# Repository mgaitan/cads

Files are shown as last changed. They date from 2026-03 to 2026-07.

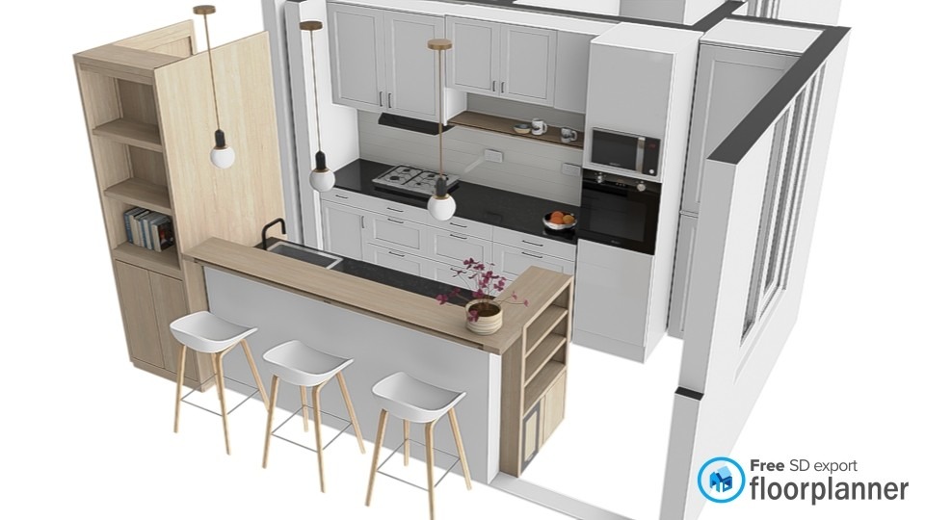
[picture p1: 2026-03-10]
renders/fuga.jpeg

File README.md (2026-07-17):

# Diseños CAD - Cocina

Repositorio de mis diseños de muebles en FreeCAD.

## Flujo actual
- Se edita el modelo directo en FreeCAD, idealmente via MCP.
- La fuente de verdad es el `FCStd`.
- Cada pieza guarda metadata embebida (`bom_*`).
- El despiece para proveedor sale en `TSV`, una fila por objeto real.
- La optimización de corte lee esos `TSV`, no BOM resumidos.

## FreeCAD MCP
Se usa [`freecad-mcp`](https://github.com/neka-nat/freecad-mcp) para editar los modelos desde una sesion de FreeCAD abierta.

La mejor manera de saber donde hay que copiar el addon es preguntarselo a FreeCAD desde su consola Python:

```python
import FreeCAD as App
print(App.getUserAppDataDir())
```

En este caso, usando AppImage `rc3`, el directorio fue:

```text
~/.local/share/FreeCAD/v1-1/
```

Configuracion MCP usada:

```json
{
  "freecad-mcp": {
    "command": "uvx",
    "args": ["-p", "3.12", "freecad-mcp", "--only-text-feedback"],
    "env": {}
  }
}
```

## Estructura útil
- `models/`: modelos fuente
- `models/*.md`: notas constructivas por mueble
- `src/cads/`: herramientas vigentes
- `outputs/supplier/`: TSV para proveedor, un archivo por material y espesor
- `outputs/cutting/`: placements, summary y SVG de corte
- `outputs/screenshots/`: capturas desde FreeCAD GUI
- `outputs/manuals/COCINA.pdf`: manual final

## Modulos
- `AA`: alacena izquierda
- `AB`: alacena derecha
- `AC`: complemento inferior de `AB`
- `BA`: bajo mesada izquierdo
- `BB`: bajo mesada derecho
- `F`: heladera + modular
- `H`: columna horno + micro
- `I`: bajo mesada isla
- `L`: armario lavarropas
- `M`: mesada principal
- `R`: rinconera
- `ENS`: ensamble cocina principal
- `ENSI`: ensamble isla
- `FULL`: ensamble completo
- `vanitory_flotante_800`: vanitory flotante anterior de 800 mm
- `vanitory_reforma_770`: vanitory reforma de 770 mm
- `vanitory_reforma_830`: vanitory reforma de 830 mm

## Herramientas vigentes
- `src/cads/freecad/macros/export_supplier_cut_list_macro.py`
  - macro FreeCAD GUI
  - exporta una fila por pieza real
- `src/cads/freecad/macros/export_screenshots_gui_macro.py`
  - macro FreeCAD GUI para vistas
- `.agents/SKILLS/freecad-furnitures/macros/create_essential_dimensions_macro.py`
  - recurso reutilizable de la skill para cotas opcionales
- `src/cads/cli/optimize_cuts.py`
  - optimiza cortes desde un solo `TSV` por corrida
- `src/cads/cli/refresh_site.py`
  - sincroniza `manual`, `screenshots`, `STL` y `cutting` dentro de `outputs/site/`
- `src/cads/freecad/freecad_gola.py`
  - helpers geométricos de gola
- `tools/build_vanitory_reforma_770.py` y `tools/build_vanitory_reforma_830.py`
  - scripts auxiliares de los vanitories; los `FCStd` siguen siendo la fuente de verdad

## Cantos del proveedor
El proveedor interpreta los 4 flags en este orden:
1. lado izquierdo del `Largo`
2. lado derecho del `Largo`
3. lado superior del `Ancho`
4. lado inferior del `Ancho`

Es decir:
- `Largo` -> `| |`
- `Ancho` -> `— —`

La macro traduce los cantos visibles del modelo a ese sistema.

Cada TSV se importa sin encabezado y tiene este orden fijo:

```text
pieza  cantidad  largo_mm  ancho_mm  girar  canto_izq  canto_der  canto_sup  canto_inf
```

La pieza se forma como `bom_codigo` + `_` + el slug de `bom_pieza`; por ejemplo,
`A1_PISO` o `A2_LAT_DERECHO`.

## Uso
Supplier desde FreeCAD GUI:
- abrir los módulos
- ejecutar `src/cads/freecad/macros/export_supplier_cut_list_macro.py`

Cotas maestras en FreeCAD GUI:
1. abrir el `FCStd` y seleccionar el documento en el arbol
2. abrir `Ver > Paneles > Consola Python`
3. pegar y ejecutar:

```python
DIMENSION_SCOPE = "casco"  # total | casco | seleccion
DIMENSION_AXES = ("X", "Y", "Z")
exec(open("/home/tin/lab/cads/.agents/SKILLS/freecad-furnitures/macros/create_essential_dimensions_macro.py").read())
```

4. en el arbol, seleccionar `Cotas esenciales` y presionar `Espacio` para mostrarlas u ocultarlas

La macro crea solo las cotas elegidas. `casco` excluye frentes, cajones,
herrajes y mesada; se ven tambien en perspectiva y se reemplazan al volver a
ejecutar la macro despues de modificar el mueble.

Optimización de corte:
```bash
uv run optimize-cuts \
  outputs/supplier/AA_AB_BA_BB_H_R_blanco_18mm.tsv \
  --board 2750x1830 --svg
```

Cada espesor o material se corre por separado, con el tamaño de placa que corresponda:

```bash
uv run optimize-cuts outputs/supplier/AA_AB_BA_BB_H_R_blanco_18mm.tsv --board 2750x1830 --svg
uv run optimize-cuts outputs/supplier/AA_AB_BA_BB_H_R_fondo_3mm.tsv --board 2440x1830 --svg
uv run optimize-cuts outputs/supplier/AA_AB_BA_BB_H_R_fondo_6mm.tsv --board 2440x1830 --svg
```

Actualización del sitio:
```bash
uv run refresh-site
```

Ese comando:
- copia el manual desde `outputs/manuals/`
- copia los STL desde `outputs/web_models/`
- copia los cortes desde `outputs/cutting/`
- aplana las capturas desde `outputs/screenshots/<MODULO>/` a `outputs/site/assets/screenshots/`

GitHub Pages publica `outputs/site/` al hacer `push` a `master`.

## Estado actual
- `I.FCStd` es la versión vigente de la isla.
- Los flujos viejos basados en `scripts/models`, `bom/*.csv` y `STEP` quedaron retirados.

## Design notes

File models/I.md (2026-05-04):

# Bajo mesada isla I

## Parametros vigentes
- Ancho casco: `1680 mm`
- Profundidad casco: `650 mm`
- Mesada: `1720 x 658 x 30 mm`
- Alzada piedra: `1720 x 30 x 180 mm`
- Fondo paraiso: desde `z=80` hasta `z=1080`
- Barra: `1720 x 370 x 30 mm`
- Alto casco: `870 mm`
- Zocalo/patas: `80 mm`

## Configuracion actual
- Nicho lavavajillas libre a la izquierda
- Dos puertas bajo bacha:
  - `I18`
  - `I18B`
- Gola `J` superior bajo mesada para las puertas de bacha: `I41`
- Divisor central bajo bacha `I4`
- Sin puerta en lavavajillas
- `I8B` y `I8C` removibles en lavavajillas
- `I8` estante regulable bajo bacha
- Alzada y barra integradas en el propio modelo `I`
- Interior del cajon superior `I29*` de `100 mm` de alto, con fondo `2 mm` sobre `I25`

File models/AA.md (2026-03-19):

# Alacena AA

## Parametros vigentes
- Ancho exterior: `903 mm`
- Profundidad exterior: `300 mm`
- Alto total: `710 mm`
- Base del casco: `0 mm`
- Tapa superior: `692..710 mm`
- Liston fijo inferior `AA10`: `313 x 90 mm`
- Referencia extractor `AA11`: `590 x 470 mm`

## Configuracion
- Dos puertas iguales `AA8/AA9`
- Piso y tapa pasantes
- Profundidad ya corregida de `320` a `300`
- El liston `AA10` va solo desde el lateral izquierdo hasta el extractor

## Instalacion
- En ensamble, la base de `AA` va a `1590 mm`
- Coronacion final alineada a `2300 mm`

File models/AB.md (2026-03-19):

# Conjunto AB + AC

## Parametros vigentes
- Ancho exterior total: `1355 mm`
- Profundidad exterior: `300 mm`
- `AC` inferior en paraiso
- `AB` superior en blanco

## AC
- Alto total de `AC`: `327 mm`
- Laterales `AC1/AC2`: `291 mm` de alto
- `AC4` hace de techo de `AC` y piso estructural de `AB`
- `AC5` es fondo de `18 mm`
- Ya no existen `AC6` a `AC9`

## AB
- Alto total de `AB`: `473 mm` sobre `AC`
- Tres puertas `AB6/AB7/AB8`
- Piso `AB3` al nivel de la gola
- Divisor `AB10` del lado derecho de la puerta central, arrancando sobre `AB3`
- Profundidad ya corregida de `320` a `300`

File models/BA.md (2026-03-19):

# Bajo mesada BA

## Parametros vigentes
- Ancho exterior: `903 mm`
- Profundidad exterior: `580 mm`
- Alto casco: `870 mm`
- Zocalo/patas: `80 mm`

## Configuracion
- Frente falso superior `BA9`
- Dos frentes grandes `BA10/BA11`
- Soporte superior frontal `BA5`: `867 x 100 mm`
- Soporte superior fondo `BA6`: `867 x 100 mm`
- Los cajones mantienen `500 mm` de largo

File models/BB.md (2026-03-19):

# Bajo mesada BB

## Parametros vigentes
- Ancho exterior: `1355 mm`
- Profundidad exterior: `580 mm`
- Alto casco: `870 mm`
- Zocalo/patas: `80 mm`

## Configuracion
- Seis frentes: `BB8` a `BB13`
- Soporte superior frontal `BB5`: `1319 x 100 mm`
- Soporte superior fondo `BB6`: `1319 x 100 mm`
- Los cajones mantienen `500 mm` de largo

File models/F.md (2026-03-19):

# Mueble F

## Parametros vigentes
- Alto total lateral: `2260 mm` sobre patas de `80 mm`
- Coronacion con `F26`: `2278 mm`
- Ancho total: `780 mm`
- Profundidad total: `950 mm`

## Configuracion
- Todo `F` va en paraiso `18 mm`
- Sin cajon superior para spots
- `F26_Techo_Modulo_Estantes` pasante a toda la profundidad
- Los laterales terminan en la cara inferior de `F26`

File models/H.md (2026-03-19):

# Columna H

## Parametros vigentes
- Altura total: `2300 mm`
- Profundidad total: `580 mm`
- Ancho exterior: `672 mm`
- Ancho interior libre entre laterales: `636 mm`
- Patas: `80 mm`

## Configuracion actual
- Dos cuerpos:
  - inferior hasta `H7`
  - alacena superior sobre `H19`
- Cuatro puertas:
  - `H10A/H10B` abajo
  - `H11A/H11B` arriba
- Regruesos horizontales:
  - `H12B` abajo del horno
  - `H9B` arriba del horno
- Regruesos verticales:
  - `H15`
  - `H16`
- `H8` es estante regulable con luz lateral

## Huecos utiles aproximados
- Horno visible de frente: `600 x 600 mm`
- Microondas interior: ancho `636 mm`, profundidad `580 mm`

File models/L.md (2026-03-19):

# Mueble L

## Parametros vigentes
- Ancho exterior: `890 mm`
- Profundidad exterior: `760 mm`
- Altura total: `2300 mm`
- Parantes exteriores: `100 mm`

## Configuracion actual
- Dos cuerpos:
  - inferior hasta la gola
  - alacena superior separada
- Gola `C` media `L12`
- Piso del modulo superior `L13`
- Puertas inferiores:
  - `L8`
  - `L9`
- Puertas superiores:
  - `L10`
  - `L11`
- `L6` es techo del sector lavarropas

## Medidas de puertas
- Inferiores: `1528 x 444 mm`
- Superiores: `666 x 442 mm`

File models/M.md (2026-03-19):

# Mesada M

## Parametros vigentes
- Largo total: `2258 mm`
- Profundidad total: `648 mm`
- Espesor: `30 mm`
- Cota inferior: `870 mm`
- Cota superior final: `900 mm`

## Nota
- La pieza vigente en el modelo es `M1_Mesada_Gris_Mara`
- Verificar siempre plantilla final in situ antes del corte definitivo de piedra

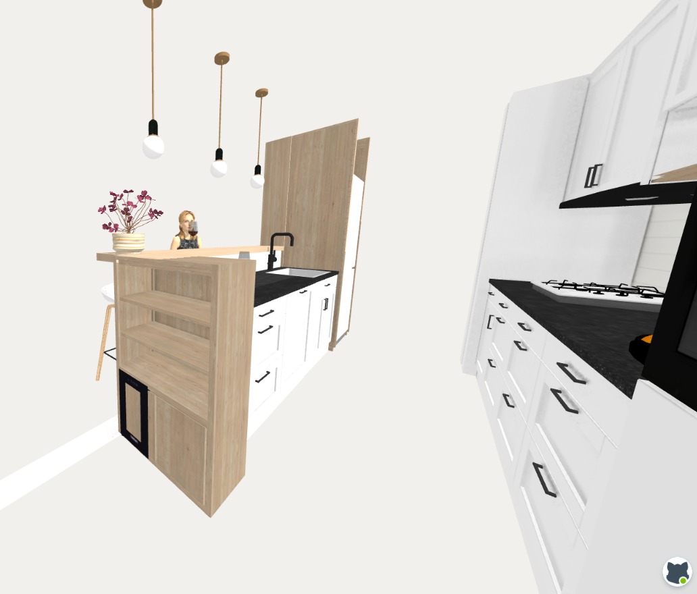
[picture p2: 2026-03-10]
renders/vista_lateral.jpeg

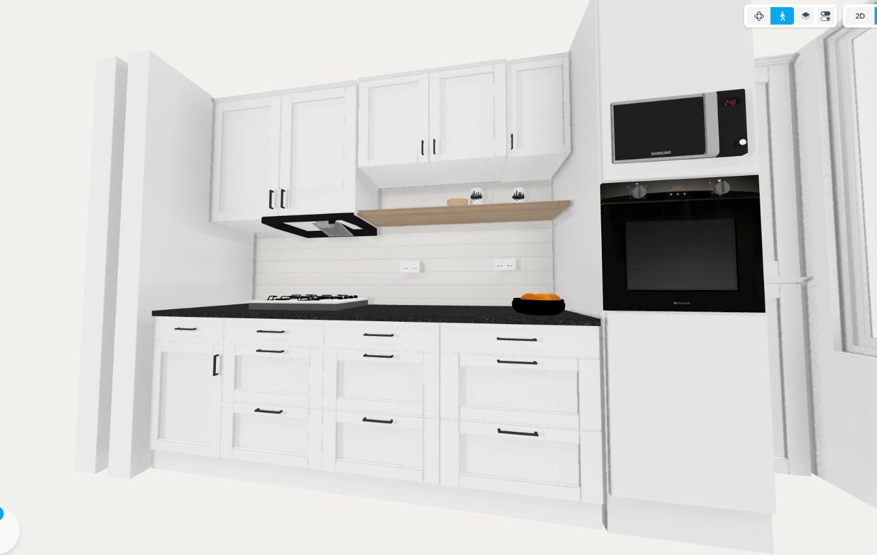
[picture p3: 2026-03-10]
renders/cocina_alacena.jpeg

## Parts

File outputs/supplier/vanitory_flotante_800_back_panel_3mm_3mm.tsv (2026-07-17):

codigo | pieza | categoria | material | largo_mm | ancho_mm | espesor_mm | canto_izq | canto_der | canto_sup | canto_inf | cantos | bisagra_codo | luz_bisagra_mm | bisagra_lado | cazoleta_diametro_mm | cazoleta_cantidad | cazoleta_posiciones
VF07 | Fondo trasero pasante 3mm | Back | back panel 3mm | 800 | 450 | 3 | 0 | 0 | 0 | 0 | sin canto de melamina |  |  |  | 0 | 0

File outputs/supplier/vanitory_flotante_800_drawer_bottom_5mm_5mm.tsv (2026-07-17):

codigo | pieza | categoria | material | largo_mm | ancho_mm | espesor_mm | canto_izq | canto_der | canto_sup | canto_inf | cantos | bisagra_codo | luz_bisagra_mm | bisagra_lado | cazoleta_diametro_mm | cazoleta_cantidad | cazoleta_posiciones
VF12_Cajon_InferiorE | Fondo 5mm pasante cajon inferior | Drawer | drawer bottom 5mm | 347 | 327 | 5 | 0 | 0 | 0 | 0 | fondo cajon 5mm pasante; sin canto de melamina |  |  |  | 0 | 0
VF13_Cajon_MedioE | Fondo 5mm pasante cajon medio | Drawer | drawer bottom 5mm | 347 | 327 | 5 | 0 | 0 | 0 | 0 | fondo cajon 5mm pasante; sin canto de melamina |  |  |  | 0 | 0
VF14_Cajon_SuperiorE | Fondo 5mm pasante cajon superior | Drawer | drawer bottom 5mm | 347 | 327 | 5 | 0 | 0 | 0 | 0 | fondo cajon 5mm pasante; sin canto de melamina |  |  |  | 0 | 0

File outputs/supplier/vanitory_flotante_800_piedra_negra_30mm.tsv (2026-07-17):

codigo | pieza | categoria | material | largo_mm | ancho_mm | espesor_mm | canto_izq | canto_der | canto_sup | canto_inf | cantos | bisagra_codo | luz_bisagra_mm | bisagra_lado | cazoleta_diametro_mm | cazoleta_cantidad | cazoleta_posiciones
VF20 | Tapa piedra negra | Countertop | piedra negra | 800 | 400 | 30 | 0 | 0 | 0 | 0 | sin canto de melamina |  |  |  | 0 | 0

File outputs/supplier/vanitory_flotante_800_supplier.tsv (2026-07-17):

codigo | pieza | categoria | material | largo_mm | ancho_mm | espesor_mm | canto_izq | canto_der | canto_sup | canto_inf | cantos | bisagra_codo | luz_bisagra_mm | bisagra_lado | cazoleta_diametro_mm | cazoleta_cantidad | cazoleta_posiciones
VF03 | Base inferior pasante | Carcass | white melamine | 800 | 370 | 18 | 1 | 0 | 0 | 0 | front edge |  |  |  | 0 | 0
VF01 | Lateral izquierdo sobre base | Carcass | white melamine | 432 | 370 | 18 | 1 | 0 | 0 | 0 | front edge |  |  |  | 0 | 0
VF02 | Lateral derecho sobre base | Carcass | white melamine | 432 | 370 | 18 | 1 | 0 | 0 | 0 | front edge |  |  |  | 0 | 0
VF04 | Riel superior frontal soporte piedra | Carcass | white melamine | 764 | 100 | 18 | 1 | 0 | 0 | 0 | front edge |  |  |  | 0 | 0
VF05 | Riel superior trasero soporte piedra | Carcass | white melamine | 764 | 100 | 18 | 0 | 0 | 0 | 0 | oculto, sin canto visible |  |  |  | 0 | 0
VF06 | Divisor vertical interior puerta/cajones | Partition | white melamine | 414 | 370 | 18 | 1 | 0 | 0 | 0 | front edge |  |  |  | 0 | 0
VF07 | Fondo trasero pasante 3mm | Back | back panel 3mm | 800 | 450 | 3 | 0 | 0 | 0 | 0 | sin canto de melamina |  |  |  | 0 | 0
VF08 | Frente puerta izquierda codo 0 | Front | white melamine | 444 | 395 | 18 | 1 | 1 | 1 | 1 | todos los cantos visibles | 0 | 3 | left | 35 | 2 | left side; codo 0; 3mm reveal; centers 90mm from bottom/top; x center 22mm from hinge edge
VF09 | Frente cajon inferior medio canto | Front | white melamine | 396 | 146 | 18 | 1 | 1 | 1 | 1 | todos los cantos visibles |  |  |  | 0 | 0
VF10 | Frente cajon medio medio canto | Front | white melamine | 396 | 146 | 18 | 1 | 1 | 1 | 1 | todos los cantos visibles |  |  |  | 0 | 0
VF11 | Frente cajon superior medio canto | Front | white melamine | 396 | 146 | 18 | 1 | 1 | 1 | 1 | todos los cantos visibles |  |  |  | 0 | 0
VF20 | Tapa piedra negra | Countertop | piedra negra | 800 | 400 | 30 | 0 | 0 | 0 | 0 | sin canto de melamina |  |  |  | 0 | 0
VF21 | Zocalo posterior piedra negra | Countertop | piedra negra | 800 | 70 | 20 | 0 | 0 | 0 | 0 | sin canto de melamina |  |  |  | 0 | 0
VF22 | Zocalo lateral izquierdo piedra negra | Countertop | piedra negra | 400 | 70 | 20 | 0 | 0 | 0 | 0 | sin canto de melamina |  |  |  | 0 | 0
VF12_Cajon_InferiorE | Fondo 5mm pasante cajon inferior | Drawer | drawer bottom 5mm | 347 | 327 | 5 | 0 | 0 | 0 | 0 | fondo cajon 5mm pasante; sin canto de melamina |  |  |  | 0 | 0
VF12_Cajon_InferiorA | Lateral izquierdo cajon inferior | Drawer | white melamine | 327 | 110 | 18 | 0 | 0 | 1 | 0 | canto superior visible al abrir el cajon |  |  |  | 0 | 0
VF12_Cajon_InferiorB | Lateral derecho cajon inferior | Drawer | white melamine | 327 | 110 | 18 | 0 | 0 | 1 | 0 | canto superior visible al abrir el cajon |  |  |  | 0 | 0
VF12_Cajon_InferiorC | Trasfrente cajon inferior | Drawer | white melamine | 311 | 110 | 18 | 0 | 0 | 1 | 0 | canto superior visible al abrir el cajon |  |  |  | 0 | 0
VF12_Cajon_InferiorD | Contrafrente cajon inferior | Drawer | white melamine | 311 | 110 | 18 | 0 | 0 | 1 | 0 | canto superior visible al abrir el cajon |  |  |  | 0 | 0
VF13_Cajon_MedioE | Fondo 5mm pasante cajon medio | Drawer | drawer bottom 5mm | 347 | 327 | 5 | 0 | 0 | 0 | 0 | fondo cajon 5mm pasante; sin canto de melamina |  |  |  | 0 | 0
VF13_Cajon_MedioA | Lateral izquierdo cajon medio | Drawer | white melamine | 327 | 110 | 18 | 0 | 0 | 1 | 0 | canto superior visible al abrir el cajon |  |  |  | 0 | 0
VF13_Cajon_MedioB | Lateral derecho cajon medio | Drawer | white melamine | 327 | 110 | 18 | 0 | 0 | 1 | 0 | canto superior visible al abrir el cajon |  |  |  | 0 | 0
VF13_Cajon_MedioC | Trasfrente cajon medio | Drawer | white melamine | 311 | 110 | 18 | 0 | 0 | 1 | 0 | canto superior visible al abrir el cajon |  |  |  | 0 | 0
VF13_Cajon_MedioD | Contrafrente cajon medio | Drawer | white melamine | 311 | 110 | 18 | 0 | 0 | 1 | 0 | canto superior visible al abrir el cajon |  |  |  | 0 | 0
VF14_Cajon_SuperiorE | Fondo 5mm pasante cajon superior | Drawer | drawer bottom 5mm | 347 | 327 | 5 | 0 | 0 | 0 | 0 | fondo cajon 5mm pasante; sin canto de melamina |  |  |  | 0 | 0
VF14_Cajon_SuperiorA | Lateral izquierdo cajon superior | Drawer | white melamine | 327 | 110 | 18 | 0 | 0 | 1 | 0 | canto superior visible al abrir el cajon |  |  |  | 0 | 0
VF14_Cajon_SuperiorB | Lateral derecho cajon superior | Drawer | white melamine | 327 | 110 | 18 | 0 | 0 | 1 | 0 | canto superior visible al abrir el cajon |  |  |  | 0 | 0
VF14_Cajon_SuperiorC | Trasfrente cajon superior | Drawer | white melamine | 311 | 110 | 18 | 0 | 0 | 1 | 0 | canto superior visible al abrir el cajon |  |  |  | 0 | 0
VF14_Cajon_SuperiorD | Contrafrente cajon superior | Drawer | white melamine | 311 | 110 | 18 | 0 | 0 | 1 | 0 | canto superior visible al abrir el cajon |  |  |  | 0 | 0

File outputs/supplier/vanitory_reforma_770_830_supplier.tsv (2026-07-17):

codigo | pieza | categoria | material | largo_mm | ancho_mm | espesor_mm | canto_izq | canto_der | canto_sup | canto_inf | cantos | bisagra_codo | luz_bisagra_mm | bisagra_lado | cazoleta_diametro_mm | cazoleta_cantidad | cazoleta_posiciones
VS_01_base_inf_pas | 770 - Base inferior pasante | Carcass | white melamine | 770 | 500 | 18 | 1 | 0 | 0 | 0 | front edge |  |  |  | 0 | 0
VS_02_lat_izq_base | 770 - Lateral izquierdo sobre base | Carcass | white melamine | 702 | 500 | 18 | 1 | 0 | 0 | 0 | front edge |  |  |  | 0 | 0
VS_03_lat_der_base | 770 - Lateral derecho sobre base | Carcass | white melamine | 702 | 500 | 18 | 1 | 0 | 0 | 0 | front edge |  |  |  | 0 | 0
VS_04_riel_sup_front_sop | 770 - Riel superior frontal soporte piedra | Carcass | white melamine | 734 | 100 | 18 | 1 | 0 | 0 | 0 | front edge |  |  |  | 0 | 0
VS_05_riel_sup_tras_sop | 770 - Riel superior trasero soporte piedra | Carcass | white melamine | 734 | 100 | 18 | 0 | 0 | 0 | 0 | oculto, sin canto visible |  |  |  | 0 | 0
VS_06_est_reg_comp | 770 - Estante regulable completo | Adjustable_Shelf | white melamine | 734 | 470 | 18 | 1 | 0 | 0 | 0 | front edge; estante regulable con soportes/perforaciones laterales |  |  |  | 0 | 0
VS_17_faja_cent_izq_sop | 770 - Faja central izquierda soporte corredera | Carcass | white melamine | 500 | 180 | 18 | 0 | 0 | 0 | 0 | soporte interior de corredera, atornillable desde arriba |  |  |  | 0 | 0
VS_18_faja_cent_der_sop | 770 - Faja central derecha soporte corredera | Carcass | white melamine | 500 | 180 | 18 | 0 | 0 | 0 | 0 | soporte interior de corredera, atornillable desde arriba |  |  |  | 0 | 0
VS_07_fte_caj_izq | 770 - Frente cajon izquierdo | Front | white melamine | 380 | 180 | 18 | 1 | 1 | 1 | 1 | todos los cantos visibles |  |  |  | 0 | 0
VS_08_fte_caj_der | 770 - Frente cajon derecho | Front | white melamine | 380 | 180 | 18 | 1 | 1 | 1 | 1 | todos los cantos visibles |  |  |  | 0 | 0
VS_09_pta_inf_izq | 770 - Puerta inferior izquierda | Front | white melamine | 510 | 380 | 18 | 1 | 1 | 1 | 1 | todos los cantos visibles | 0 | 3 | left | 35 | 2 | left side; codo 0; 3mm reveal; centers 90mm from bottom/top; x center 22mm from hinge edge
VS_10_pta_inf_der | 770 - Puerta inferior derecha | Front | white melamine | 510 | 380 | 18 | 1 | 1 | 1 | 1 | todos los cantos visibles | 0 | 3 | right | 35 | 2 | right side; codo 0; 3mm reveal; centers 90mm from bottom/top; x center 22mm from hinge edge
VS_11a_lat_izq_caj_izq | 770 - Lateral izquierdo cajon izquierdo | Drawer | white melamine | 300 | 140 | 18 | 0 | 0 | 1 | 0 | canto superior visible al abrir el cajon |  |  |  | 0 | 0
VS_11b_lat_der_caj_izq | 770 - Lateral derecho cajon izquierdo | Drawer | white melamine | 300 | 140 | 18 | 0 | 0 | 1 | 0 | canto superior visible al abrir el cajon |  |  |  | 0 | 0
VS_11c_trasfte_caj_izq | 770 - Trasfrente cajon izquierdo | Drawer | white melamine | 283 | 140 | 18 | 0 | 0 | 1 | 0 | canto superior visible al abrir el cajon |  |  |  | 0 | 0
VS_11d_ctrfte_caj_izq | 770 - Contrafrente cajon izquierdo | Drawer | white melamine | 283 | 140 | 18 | 0 | 0 | 1 | 0 | canto superior visible al abrir el cajon |  |  |  | 0 | 0
VS_11e_fondo_caj_izq | 770 - Fondo cajon izquierdo | Drawer | drawer bottom 5mm | 300 | 283 | 5 | 0 | 0 | 0 | 0 | sin canto visible |  |  |  | 0 | 0
VS_12a_lat_izq_caj_der | 770 - Lateral izquierdo cajon derecho | Drawer | white melamine | 300 | 140 | 18 | 0 | 0 | 1 | 0 | canto superior visible al abrir el cajon |  |  |  | 0 | 0
VS_12b_lat_der_caj_der | 770 - Lateral derecho cajon derecho | Drawer | white melamine | 300 | 140 | 18 | 0 | 0 | 1 | 0 | canto superior visible al abrir el cajon |  |  |  | 0 | 0
VS_12c_trasfte_caj_der | 770 - Trasfrente cajon derecho | Drawer | white melamine | 283 | 140 | 18 | 0 | 0 | 1 | 0 | canto superior visible al abrir el cajon |  |  |  | 0 | 0
VS_12d_ctrfte_caj_der | 770 - Contrafrente cajon derecho | Drawer | white melamine | 283 | 140 | 18 | 0 | 0 | 1 | 0 | canto superior visible al abrir el cajon |  |  |  | 0 | 0
VS_12e_fondo_caj_der | 770 - Fondo cajon derecho | Drawer | drawer bottom 5mm | 300 | 283 | 5 | 0 | 0 | 0 | 0 | sin canto visible |  |  |  | 0 | 0
VS_15_zoc_mes_piedra_tras | 770 - Zocalo mesada piedra trasero | Plinth | black stone | 770 | 120 | 20 | 0 | 0 | 0 | 0 | alzada trasera sobre mesada |  |  |  | 0 | 0
VS_16_piedra_sup | 770 - Piedra superior | Countertop | black stone | 770 | 533 | 20 | 0 | 0 | 0 | 0 | vuela 15mm por delante de los frentes; verificar plantilla en obra |  |  |  | 0 | 0
VC_01_base_inf_pas | 820 - Base inferior pasante | Carcass | white melamine | 820 | 407 | 18 | 1 | 0 | 0 | 0 | front edge |  |  |  | 0 | 0
VC_02_lat_izq_base | 820 - Lateral izquierdo sobre base | Carcass | white melamine | 702 | 407 | 18 | 1 | 0 | 0 | 0 | front edge |  |  |  | 0 | 0
VC_03_lat_der_base | 820 - Lateral derecho sobre base | Carcass | white melamine | 702 | 407 | 18 | 1 | 0 | 0 | 0 | front edge |  |  |  | 0 | 0
VC_04_riel_sup_front_sop | 820 - Riel superior frontal soporte piedra | Carcass | white melamine | 784 | 100 | 18 | 1 | 0 | 0 | 0 | front edge |  |  |  | 0 | 0
VC_05_riel_sup_tras_sop | 820 - Riel superior trasero soporte piedra | Carcass | white melamine | 784 | 100 | 18 | 0 | 0 | 0 | 0 | oculto, sin canto visible |  |  |  | 0 | 0
VC_06_est_reg_comp | 820 - Estante regulable completo | Adjustable_Shelf | white melamine | 784 | 377 | 18 | 1 | 0 | 0 | 0 | front edge; estante regulable con soportes/perforaciones laterales |  |  |  | 0 | 0
VC_17_faja_cent_izq_sop | 820 - Faja central izquierda soporte corredera | Carcass | white melamine | 407 | 180 | 18 | 0 | 0 | 0 | 0 | soporte interior de corredera, atornillable desde arriba |  |  |  | 0 | 0
VC_18_faja_cent_der_sop | 820 - Faja central derecha soporte corredera | Carcass | white melamine | 407 | 180 | 18 | 0 | 0 | 0 | 0 | soporte interior de corredera, atornillable desde arriba |  |  |  | 0 | 0
VC_07_fte_caj_izq | 820 - Frente cajon izquierdo | Front | white melamine | 405 | 180 | 18 | 1 | 1 | 1 | 1 | todos los cantos visibles |  |  |  | 0 | 0
VC_08_fte_caj_der | 820 - Frente cajon derecho | Front | white melamine | 405 | 180 | 18 | 1 | 1 | 1 | 1 | todos los cantos visibles |  |  |  | 0 | 0
VC_09_pta_inf_izq | 820 - Puerta inferior izquierda | Front | white melamine | 510 | 405 | 18 | 1 | 1 | 1 | 1 | todos los cantos visibles | 0 | 3 | left | 35 | 2 | left side; codo 0; 3mm reveal; centers 90mm from bottom/top; x center 22mm from hinge edge
VC_10_pta_inf_der | 820 - Puerta inferior derecha | Front | white melamine | 510 | 405 | 18 | 1 | 1 | 1 | 1 | todos los cantos visibles | 0 | 3 | right | 35 | 2 | right side; codo 0; 3mm reveal; centers 90mm from bottom/top; x center 22mm from hinge edge
VC_11a_lat_izq_caj_izq | 820 - Lateral izquierdo cajon izquierdo | Drawer | white melamine | 300 | 140 | 18 | 0 | 0 | 1 | 0 | canto superior visible al abrir el cajon |  |  |  | 0 | 0
VC_11b_lat_der_caj_izq | 820 - Lateral derecho cajon izquierdo | Drawer | white melamine | 300 | 140 | 18 | 0 | 0 | 1 | 0 | canto superior visible al abrir el cajon |  |  |  | 0 | 0
VC_11c_trasfte_caj_izq | 820 - Trasfrente cajon izquierdo | Drawer | white melamine | 308 | 140 | 18 | 0 | 0 | 1 | 0 | canto superior visible al abrir el cajon |  |  |  | 0 | 0
VC_11d_ctrfte_caj_izq | 820 - Contrafrente cajon izquierdo | Drawer | white melamine | 308 | 140 | 18 | 0 | 0 | 1 | 0 | canto superior visible al abrir el cajon |  |  |  | 0 | 0
VC_11e_fondo_caj_izq | 820 - Fondo cajon izquierdo | Drawer | drawer bottom 5mm | 308 | 300 | 5 | 0 | 0 | 0 | 0 | sin canto visible |  |  |  | 0 | 0
VC_12a_lat_izq_caj_der | 820 - Lateral izquierdo cajon derecho | Drawer | white melamine | 300 | 140 | 18 | 0 | 0 | 1 | 0 | canto superior visible al abrir el cajon |  |  |  | 0 | 0
VC_12b_lat_der_caj_der | 820 - Lateral derecho cajon derecho | Drawer | white melamine | 300 | 140 | 18 | 0 | 0 | 1 | 0 | canto superior visible al abrir el cajon |  |  |  | 0 | 0
VC_12c_trasfte_caj_der | 820 - Trasfrente cajon derecho | Drawer | white melamine | 308 | 140 | 18 | 0 | 0 | 1 | 0 | canto superior visible al abrir el cajon |  |  |  | 0 | 0
VC_12d_ctrfte_caj_der | 820 - Contrafrente cajon derecho | Drawer | white melamine | 308 | 140 | 18 | 0 | 0 | 1 | 0 | canto superior visible al abrir el cajon |  |  |  | 0 | 0
VC_12e_fondo_caj_der | 820 - Fondo cajon derecho | Drawer | drawer bottom 5mm | 308 | 300 | 5 | 0 | 0 | 0 | 0 | sin canto visible |  |  |  | 0 | 0
VC_15_zoc_mes_piedra_tras | 820 - Zocalo mesada piedra trasero | Plinth | black stone | 820 | 120 | 20 | 0 | 0 | 0 | 0 | alzada trasera sobre mesada |  |  |  | 0 | 0
VC_16_piedra_sup | 820 - Piedra superior | Countertop | black stone | 820 | 440 | 20 | 0 | 0 | 0 | 0 | vuela 15mm por delante de los frentes; verificar plantilla en obra |  |  |  | 0 | 0

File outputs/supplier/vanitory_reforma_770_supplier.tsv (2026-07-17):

codigo | pieza | categoria | material | largo_mm | ancho_mm | espesor_mm | canto_izq | canto_der | canto_sup | canto_inf | cantos | bisagra_codo | luz_bisagra_mm | bisagra_lado | cazoleta_diametro_mm | cazoleta_cantidad | cazoleta_posiciones
VS_01_base_inf_pas | Base inferior pasante | Carcass | white melamine | 770 | 500 | 18 | 1 | 0 | 0 | 0 | front edge |  |  |  | 0 | 0
VS_02_lat_izq_base | Lateral izquierdo sobre base | Carcass | white melamine | 702 | 500 | 18 | 1 | 0 | 0 | 0 | front edge |  |  |  | 0 | 0
VS_03_lat_der_base | Lateral derecho sobre base | Carcass | white melamine | 702 | 500 | 18 | 1 | 0 | 0 | 0 | front edge |  |  |  | 0 | 0
VS_04_riel_sup_front_sop | Riel superior frontal soporte piedra | Carcass | white melamine | 734 | 100 | 18 | 1 | 0 | 0 | 0 | front edge |  |  |  | 0 | 0
VS_05_riel_sup_tras_sop | Riel superior trasero soporte piedra | Carcass | white melamine | 734 | 100 | 18 | 0 | 0 | 0 | 0 | oculto, sin canto visible |  |  |  | 0 | 0
VS_06_est_reg_comp | Estante regulable completo | Adjustable_Shelf | white melamine | 734 | 470 | 18 | 1 | 0 | 0 | 0 | front edge; estante regulable con soportes/perforaciones laterales |  |  |  | 0 | 0
VS_17_faja_cent_izq_sop | Faja central izquierda soporte corredera | Carcass | white melamine | 500 | 180 | 18 | 0 | 0 | 0 | 0 | soporte interior de corredera, atornillable desde arriba |  |  |  | 0 | 0
VS_18_faja_cent_der_sop | Faja central derecha soporte corredera | Carcass | white melamine | 500 | 180 | 18 | 0 | 0 | 0 | 0 | soporte interior de corredera, atornillable desde arriba |  |  |  | 0 | 0
VS_07_fte_caj_izq | Frente cajon izquierdo | Front | white melamine | 380 | 180 | 18 | 1 | 1 | 1 | 1 | todos los cantos visibles |  |  |  | 0 | 0
VS_08_fte_caj_der | Frente cajon derecho | Front | white melamine | 380 | 180 | 18 | 1 | 1 | 1 | 1 | todos los cantos visibles |  |  |  | 0 | 0
VS_09_pta_inf_izq | Puerta inferior izquierda | Front | white melamine | 510 | 380 | 18 | 1 | 1 | 1 | 1 | todos los cantos visibles | 0 | 3 | left | 35 | 2 | left side; codo 0; 3mm reveal; centers 90mm from bottom/top; x center 22mm from hinge edge
VS_10_pta_inf_der | Puerta inferior derecha | Front | white melamine | 510 | 380 | 18 | 1 | 1 | 1 | 1 | todos los cantos visibles | 0 | 3 | right | 35 | 2 | right side; codo 0; 3mm reveal; centers 90mm from bottom/top; x center 22mm from hinge edge
VS_11a_lat_izq_caj_izq | Lateral izquierdo cajon izquierdo | Drawer | white melamine | 300 | 140 | 18 | 0 | 0 | 1 | 0 | canto superior visible al abrir el cajon |  |  |  | 0 | 0
VS_11b_lat_der_caj_izq | Lateral derecho cajon izquierdo | Drawer | white melamine | 300 | 140 | 18 | 0 | 0 | 1 | 0 | canto superior visible al abrir el cajon |  |  |  | 0 | 0
VS_11c_trasfte_caj_izq | Trasfrente cajon izquierdo | Drawer | white melamine | 283 | 140 | 18 | 0 | 0 | 1 | 0 | canto superior visible al abrir el cajon |  |  |  | 0 | 0
VS_11d_ctrfte_caj_izq | Contrafrente cajon izquierdo | Drawer | white melamine | 283 | 140 | 18 | 0 | 0 | 1 | 0 | canto superior visible al abrir el cajon |  |  |  | 0 | 0
VS_11e_fondo_caj_izq | Fondo cajon izquierdo | Drawer | drawer bottom 5mm | 300 | 283 | 5 | 0 | 0 | 0 | 0 | sin canto visible |  |  |  | 0 | 0
VS_12a_lat_izq_caj_der | Lateral izquierdo cajon derecho | Drawer | white melamine | 300 | 140 | 18 | 0 | 0 | 1 | 0 | canto superior visible al abrir el cajon |  |  |  | 0 | 0
VS_12b_lat_der_caj_der | Lateral derecho cajon derecho | Drawer | white melamine | 300 | 140 | 18 | 0 | 0 | 1 | 0 | canto superior visible al abrir el cajon |  |  |  | 0 | 0
VS_12c_trasfte_caj_der | Trasfrente cajon derecho | Drawer | white melamine | 283 | 140 | 18 | 0 | 0 | 1 | 0 | canto superior visible al abrir el cajon |  |  |  | 0 | 0
VS_12d_ctrfte_caj_der | Contrafrente cajon derecho | Drawer | white melamine | 283 | 140 | 18 | 0 | 0 | 1 | 0 | canto superior visible al abrir el cajon |  |  |  | 0 | 0
VS_12e_fondo_caj_der | Fondo cajon derecho | Drawer | drawer bottom 5mm | 300 | 283 | 5 | 0 | 0 | 0 | 0 | sin canto visible |  |  |  | 0 | 0
VS_15_zoc_mes_piedra_tras | Zocalo mesada piedra trasero | Plinth | black stone | 770 | 120 | 20 | 0 | 0 | 0 | 0 | alzada trasera sobre mesada |  |  |  | 0 | 0
VS_16_piedra_sup | Piedra superior | Countertop | black stone | 770 | 533 | 20 | 0 | 0 | 0 | 0 | vuela 15mm por delante de los frentes; verificar plantilla en obra |  |  |  | 0 | 0

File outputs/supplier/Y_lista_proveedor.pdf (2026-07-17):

# Lista de piezas proveedor - Modulo Y

## Blanco 18 mm (25 piezas)

Pieza | Cant. | Largo | Ancho | Rot. | C.Izq | C.Der | C.Sup | C.Inf
Y18B_Puerta_Bacha_Der | 1 | 762 | 555 | SI | 0 | 0 | 0 | 0
Y18_Puerta_Bacha_Izq | 1 | 762 | 555 | SI | 1 | 1 | 1 | 1
Y1_Lateral_Izq_Frente | 1 | 772 | 650 | SI | 0 | 1 | 0 | 0
Y24_Division_Cajonera_Izq | 1 | 772 | 650 | SI | 0 | 1 | 0 | 0
Y26_Frente_Cajon_Superior | 1 | 237 | 556 | SI | 1 | 1 | 1 | 1
Y27_Frente_Cajon_Medio | 1 | 597 | 556 | SI | 1 | 1 | 1 | 1
Y28_Frente_Cajon_Inferior | 1 | 237 | 538 | SI | 1 | 1 | 1 | 1
Y29B_Caja_Cajon_Superior_Lateral_Der | 1 | 330 | 100 | SI | 0 | 0 | 0 | 0
Y29C_Caja_Cajon_Superior_Frente | 1 | 477 | 100 | SI | 0 | 0 | 0 | 0
Y29D_Caja_Cajon_Superior_Trasera | 1 | 477 | 100 | SI | 0 | 0 | 0 | 0
Y29_Caja_Cajon_Superior_Lateral_Izq | 1 | 330 | 100 | SI | 0 | 0 | 0 | 0
Y2_Lateral_Der | 1 | 772 | 650 | SI | 1 | 0 | 0 | 0
Y32_Piso_Cajonera | 1 | 574 | 650 | SI | 0 | 0 | 0 | 0
Y35_Estante_Nicho_Trasero | 1 | 536 | 290 | SI | 0 | 0 | 0 | 0
Y37_Fondo_Cajon_Trasero | 1 | 772 | 538 | SI | 0 | 0 | 0 | 0
Y38_Regrueso_Bisagra_Nicho | 1 | 772 | 50 | SI | 0 | 0 | 0 | 0
Y39_Puerta_Nicho_Lateral | 1 | 744 | 284 | SI | 0 | 0 | 0 | 0
Y3_Division_1 | 1 | 772 | 650 | SI | 1 | 0 | 0 | 0
Y6_Piso_Der | 1 | 1057 | 650 | SI | 0 | 0 | 0 | 0
Y8B_Piso_Removible_Lavavajillas | 1 | 583 | 601 | SI | 0 | 0 | 0 | 0
Y8C_Piso_Falso_Lavavajillas | 1 | 601 | 650 | SI | 0 | 0 | 0 | 0
Y9B_Soporte_Sup_Trasero | 1 | 556 | 100 | SI | 0 | 0 | 0 | 0
Y9C_Soporte_Sup_Frente_Bacha | 1 | 1095 | 100 | SI | 1 | 0 | 0 | 0
Y9D_Soporte_Sup_Trasero_Bacha | 1 | 1095 | 100 | SI | 0 | 0 | 0 | 0
Y9_Soporte_Sup_Frente | 1 | 556 | 100 | SI | 1 | 0 | 0 | 0

## Fondo 3 mm (0 piezas)

Sin piezas para este material.

## Fondo 6 mm (1 piezas)

Pieza | Cant. | Largo | Ancho | Rot. | C.Izq | C.Der | C.Sup | C.Inf
Y29E_Caja_Cajon_Superior_Fondo_6mm | 1 | 513 | 330 | SI | 0 | 0 | 0 | 0

## Paraiso 18 mm (1 piezas)

Pieza | Cant. | Largo | Ancho | Rot. | C.Izq | C.Der | C.Sup | C.Inf
Y21B_Placa_Fondo_Paraiso | 1 | 2350 | 1000 | SI | 0 | 0 | 0 | 0

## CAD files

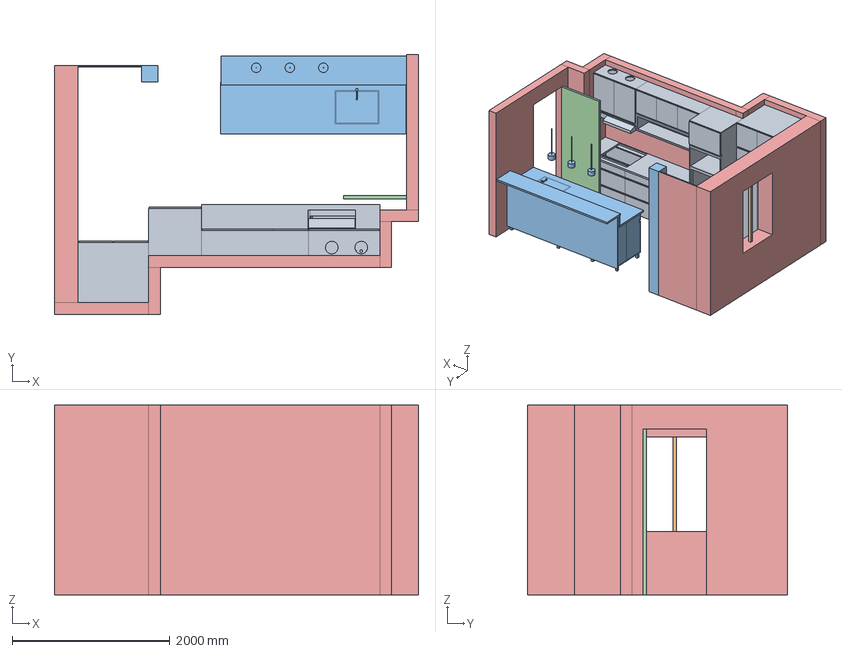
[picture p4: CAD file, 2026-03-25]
models/FULL.FCStd
4610.0 x 3293.0 x 2400.0 mm
FULL_ENS
FULL_Ventana_Parteluz
FULL_ENSI
FULL_Puerta_Cierre_Der
FULL_Muros_Arquitectura

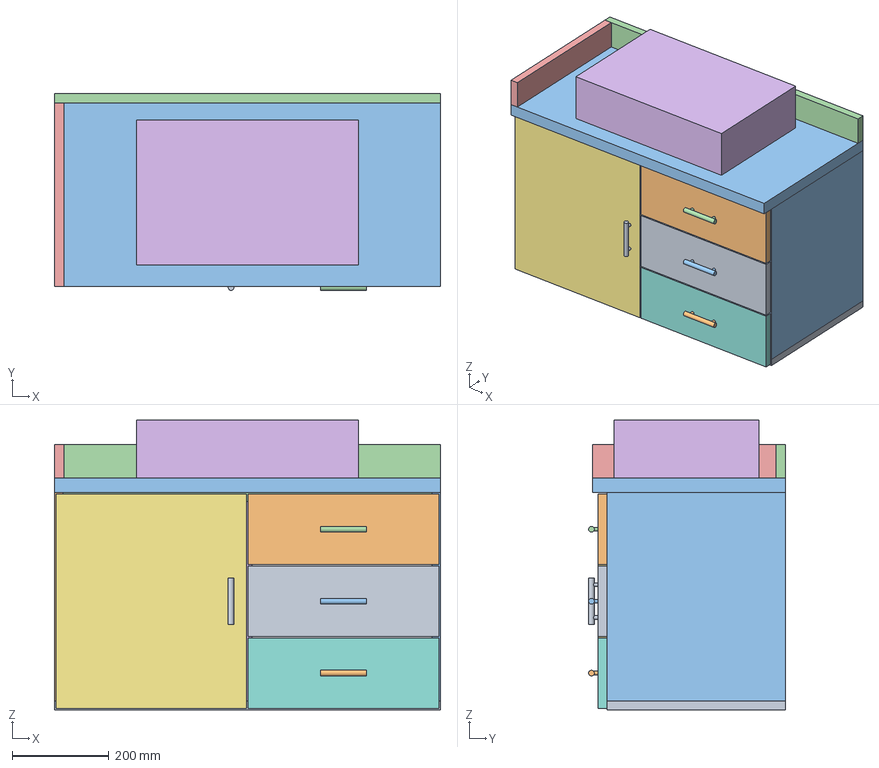
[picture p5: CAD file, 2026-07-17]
models/vanitory_flotante_800.FCStd
800.0 x 408.0 x 600.0 mm
VF03_Base_Inferior_Pasante
VF01_Lateral_Izquierdo
VF02_Lateral_Derecho
VF04_Riel_Superior_Frontal
VF05_Riel_Superior_Trasero
VF06_Divisor_Vertical_Interior
VF08_Frente_Puerta_Izquierda
VF09_Frente_cajon_inferior_medio_canto
VF10_Frente_cajon_medio_medio_canto
VF11_Frente_cajon_superior_medio_canto
VF20_Tapa_Piedra_Negra
VF21_Zocalo_Posterior_Piedra
VF22_Zocalo_Lateral_Izq_Piedra
VF30_Pileta_Sobreponer_120h
VF31_Cavidad_Pileta_Referencia
VF32_Desague_Referencia
VF50_Tirador_Puerta_Compuesto
VF51_Tirador_Cajon_Inferior_Compuesto
VF52_Tirador_Cajon_Medio_Compuesto
VF53_Tirador_Cajon_Superior_Compuesto
VF60_Cazoletas_Puerta_35mm
VF12_Cajon_Inferior_Fondo_5mm_Pasante
VF12_Cajon_Inferior_Lateral_Izq
VF12_Cajon_Inferior_Lateral_Der
VF12_Cajon_Inferior_Trasfrente
VF12_Cajon_Inferior_Contrafrente
VF13_Cajon_Medio_Fondo_5mm_Pasante
VF13_Cajon_Medio_Lateral_Izq
VF13_Cajon_Medio_Lateral_Der
VF13_Cajon_Medio_Trasfrente
VF13_Cajon_Medio_Contrafrente
VF14_Cajon_Superior_Fondo_5mm_Pasante
VF14_Cajon_Superior_Lateral_Izq
VF14_Cajon_Superior_Lateral_Der
VF14_Cajon_Superior_Trasfrente
VF14_Cajon_Superior_Contrafrente

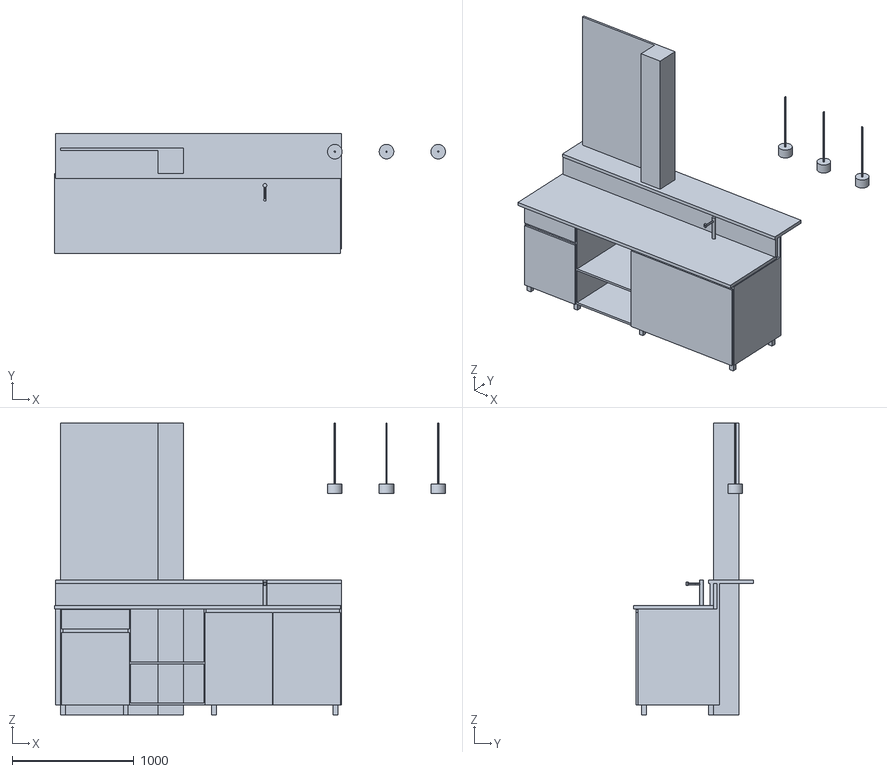
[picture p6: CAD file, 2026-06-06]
outputs/site/assets/models/ENSI.stl
3215.0 x 988.0 x 2400.0

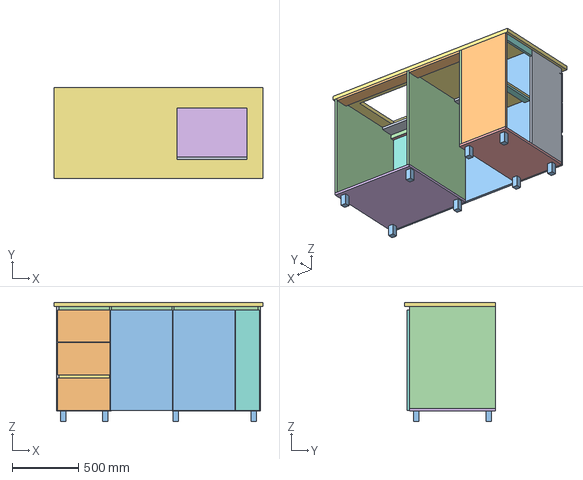
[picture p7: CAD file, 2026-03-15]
outputs/site/assets/variants/I/alt-01/I_alt-01.step
1580.0 x 688.0 x 900.0 mm

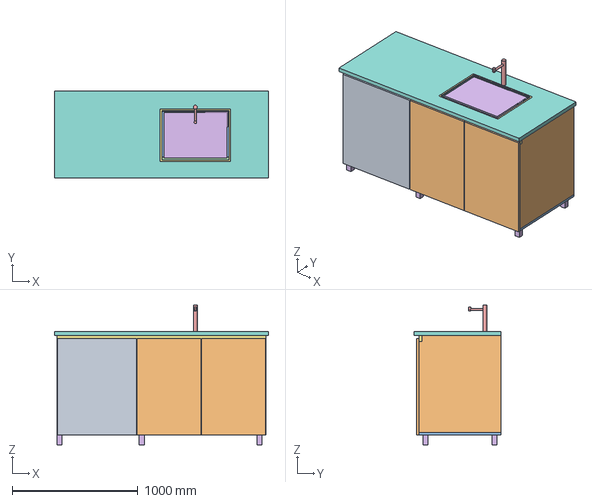
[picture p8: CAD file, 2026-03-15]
outputs/site/assets/variants/I/alt-02/I_alt-02.step
1700.0 x 688.0 x 1110.0 mm

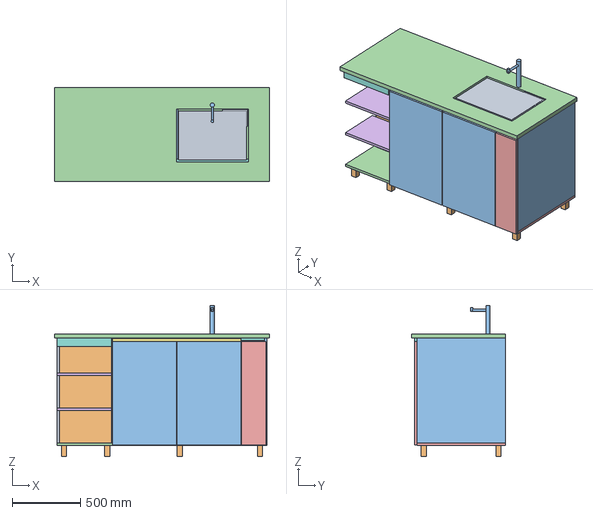
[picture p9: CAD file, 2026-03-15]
outputs/site/assets/variants/I/alt-03/I_alt-03.step
1580.0 x 688.0 x 1110.0 mm

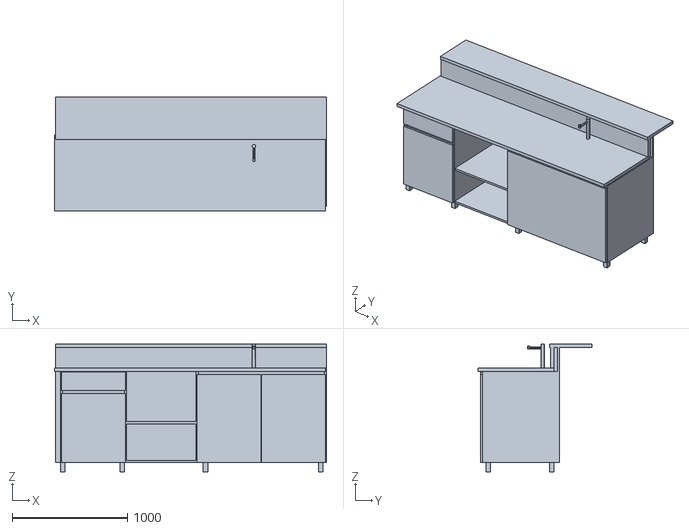
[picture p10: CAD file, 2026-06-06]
outputs/web_models/I.stl
2360.0 x 988.0 x 1110.0

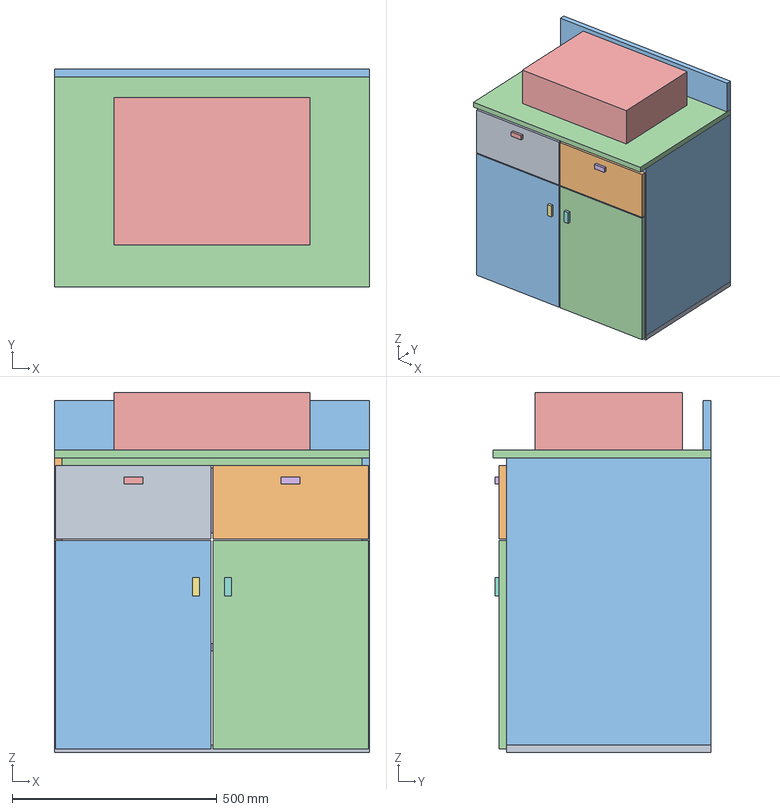
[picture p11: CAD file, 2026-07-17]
models/vanitory_reforma_770.FCStd
770.0 x 533.0 x 880.0 mm
VS_01_base_inf_pas Base inferior pasante
VS_02_lat_izq_base Lateral izquierdo sobre base
VS_03_lat_der_base Lateral derecho sobre base
VS_04_riel_sup_front_sop Riel superior frontal soporte piedra
VS_05_riel_sup_tras_sop Riel superior trasero soporte piedra
VS_06_est_reg_comp Estante regulable completo
VS_17_faja_cent_izq_sop Faja central izquierda soporte corredera
VS_18_faja_cent_der_sop Faja central derecha soporte corredera
VS_07_fte_caj_izq Frente cajon izquierdo
VS_08_fte_caj_der Frente cajon derecho
VS_09_pta_inf_izq Puerta inferior izquierda
VS_10_pta_inf_der Puerta inferior derecha
VS_01_tirado_negro_46mm_horizo Tirador negro 46mm horizontal cajon izquierdo
VS_02_tirado_negro_46mm_horizo Tirador negro 46mm horizontal cajon derecho
VS_03_tirado_negro_46mm_vertic Tirador negro 46mm vertical puerta izquierda
VS_04_tirado_negro_46mm_vertic Tirador negro 46mm vertical puerta derecha
VS_11a_lat_izq_caj_izq Lateral izquierdo cajon izquierdo
VS_11b_lat_der_caj_izq Lateral derecho cajon izquierdo
VS_11c_trasfte_caj_izq Trasfrente cajon izquierdo
VS_11d_ctrfte_caj_izq Contrafrente cajon izquierdo
VS_11e_fondo_caj_izq Fondo cajon izquierdo
VS_12a_lat_izq_caj_der Lateral izquierdo cajon derecho
VS_12b_lat_der_caj_der Lateral derecho cajon derecho
VS_12c_trasfte_caj_der Trasfrente cajon derecho
VS_12d_ctrfte_caj_der Contrafrente cajon derecho
VS_12e_fondo_caj_der Fondo cajon derecho
VS_15_zoc_mes_piedra_tras Zocalo mesada piedra trasero
VS_16_piedra_sup Piedra superior
VS_01_bacha_de_apoyar_centra Bacha de apoyar centrada referencia
VS_02_canal_sanita_cajone_80mm Canal sanitario cajones 80mm

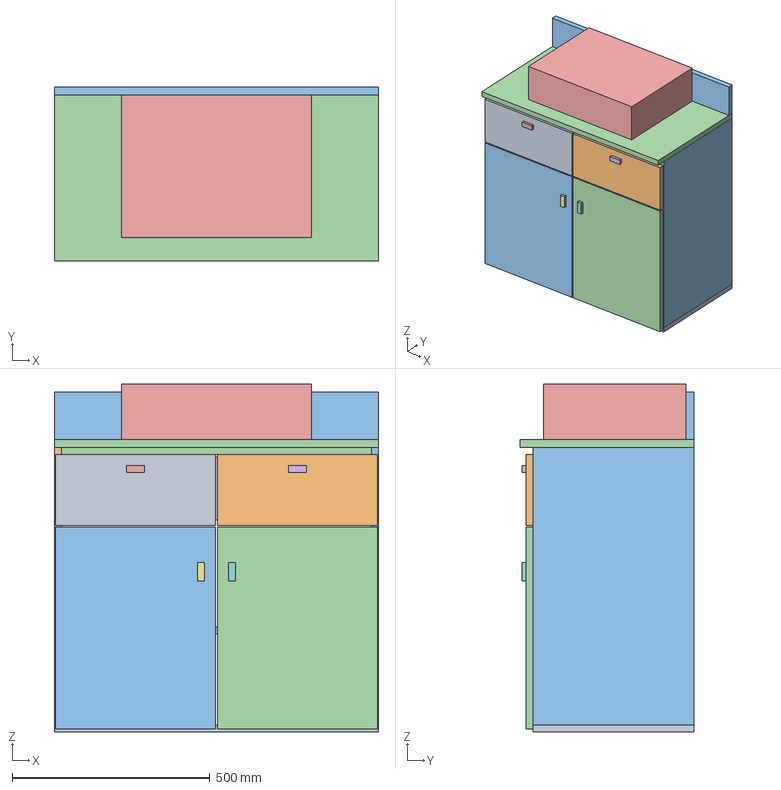
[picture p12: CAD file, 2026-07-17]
models/vanitory_reforma_830.FCStd
820.0 x 440.0 x 880.0 mm
VC_01_base_inf_pas Base inferior pasante
VC_02_lat_izq_base Lateral izquierdo sobre base
VC_03_lat_der_base Lateral derecho sobre base
VC_04_riel_sup_front_sop Riel superior frontal soporte piedra
VC_05_riel_sup_tras_sop Riel superior trasero soporte piedra
VC_06_est_reg_comp Estante regulable completo
VC_17_faja_cent_izq_sop Faja central izquierda soporte corredera
VC_18_faja_cent_der_sop Faja central derecha soporte corredera
VC_07_fte_caj_izq Frente cajon izquierdo
VC_08_fte_caj_der Frente cajon derecho
VC_09_pta_inf_izq Puerta inferior izquierda
VC_10_pta_inf_der Puerta inferior derecha
VC_01_tirado_negro_46mm_horizo Tirador negro 46mm horizontal cajon izquierdo
VC_02_tirado_negro_46mm_horizo Tirador negro 46mm horizontal cajon derecho
VC_03_tirado_negro_46mm_vertic Tirador negro 46mm vertical puerta izquierda
VC_04_tirado_negro_46mm_vertic Tirador negro 46mm vertical puerta derecha
VC_11a_lat_izq_caj_izq Lateral izquierdo cajon izquierdo
VC_11b_lat_der_caj_izq Lateral derecho cajon izquierdo
VC_11c_trasfte_caj_izq Trasfrente cajon izquierdo
VC_11d_ctrfte_caj_izq Contrafrente cajon izquierdo
VC_11e_fondo_caj_izq Fondo cajon izquierdo
VC_12a_lat_izq_caj_der Lateral izquierdo cajon derecho
VC_12b_lat_der_caj_der Lateral derecho cajon derecho
VC_12c_trasfte_caj_der Trasfrente cajon derecho
VC_12d_ctrfte_caj_der Contrafrente cajon derecho
VC_12e_fondo_caj_der Fondo cajon derecho
VC_15_zoc_mes_piedra_tras Zocalo mesada piedra trasero
VC_16_piedra_sup Piedra superior
VC_01_bacha_de_apoyar_centra Bacha de apoyar centrada referencia
VC_02_canal_sanita_cajone_80mm Canal sanitario cajones 80mm

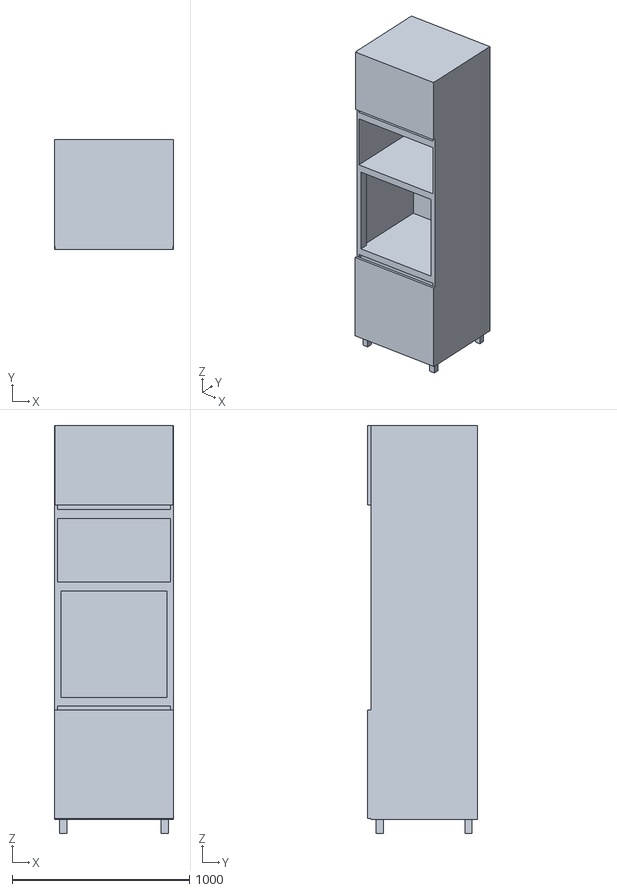
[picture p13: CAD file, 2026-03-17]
outputs/site/assets/models/H.stl
672.0 x 618.0 x 2300.0

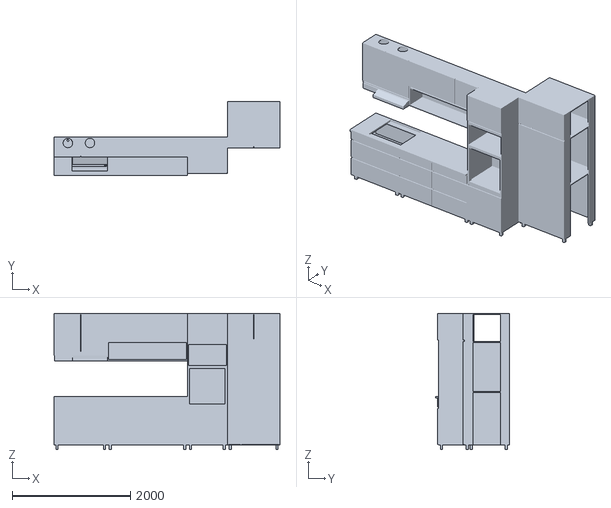
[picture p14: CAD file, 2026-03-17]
outputs/site/assets/models/ENS.stl
3820.0 x 1243.0 x 2300.0

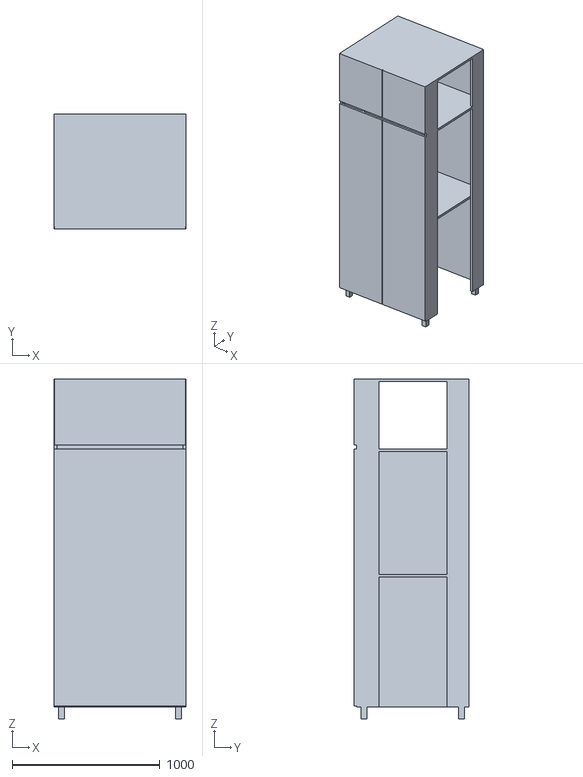
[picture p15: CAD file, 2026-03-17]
outputs/site/assets/models/L.stl
890.0 x 778.0 x 2300.0

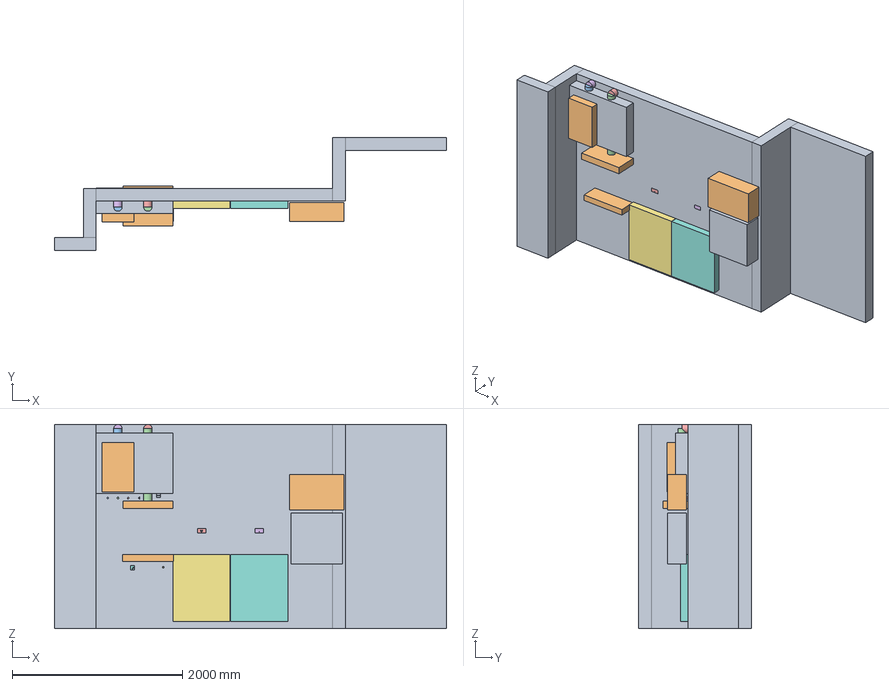
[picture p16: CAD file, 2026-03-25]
models/ENS_INSTALACIONES.FCStd
4610.0 x 1325.0 x 2400.0 mm
ENS_INST_Muros
AA_Calefon_Simplificado
AA_Calefon_AguaCaliente
AA_Calefon_Gas
AA_Calefon_AguaFria
AA_Calefon_Salida_100
AA_Calefon_Gancho_Izq
AA_Calefon_Gancho_Der
REF_AA_Casco_Simplificado
REF_AA_Extractor_Simplificado
AA_Calefon_Ducto_Vertical
AA_Extractor_Ducto_Vertical
AA_Extractor_Codo_100
AA_Calefon_Llave_Paso_Fria
BA_Anafe_Gas
BA_Anafe_Caja_Electrica
AA_Extractor_Caja_Electrica
BA_Anafe_Simplificado
H_Horno_Caja_Electrica
H_Micro_Caja_Electrica
BB_Caja_Electrica_Izq
BB_Caja_Electrica_Der
BB_Cajonera_Izq_Simplificada
BB_Cajonera_Der_Simplificada
H_Horno_Simplificado
H_Micro_Simplificado
BB_Caja_Inspeccion_Agua

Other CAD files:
outputs/site/assets/models/FULL.stl
models/ENSI.FCStd
models/I.FCStd
models/AA.FCStd
models/AB.FCStd
models/BA.FCStd
models/BB.FCStd
models/ENS.FCStd
models/F.FCStd
models/H.FCStd
models/L.FCStd
models/M.FCStd
models/R.FCStd
outputs/site/assets/models/AA.stl
outputs/site/assets/models/AB.stl
outputs/site/assets/models/BA.stl
outputs/site/assets/models/BB.stl
outputs/site/assets/models/F.stl
outputs/site/assets/models/M.stl
outputs/site/assets/models/R.stl
outputs/site/assets/variants/I/alt-01/I_alt-01.stl
outputs/site/assets/variants/I/alt-02/I_alt-02.stl
outputs/site/assets/variants/I/alt-03/I_alt-03.stl

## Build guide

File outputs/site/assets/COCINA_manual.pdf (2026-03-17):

# Manual Constructivo Integral - Cocina

## 1. Ensambles generales

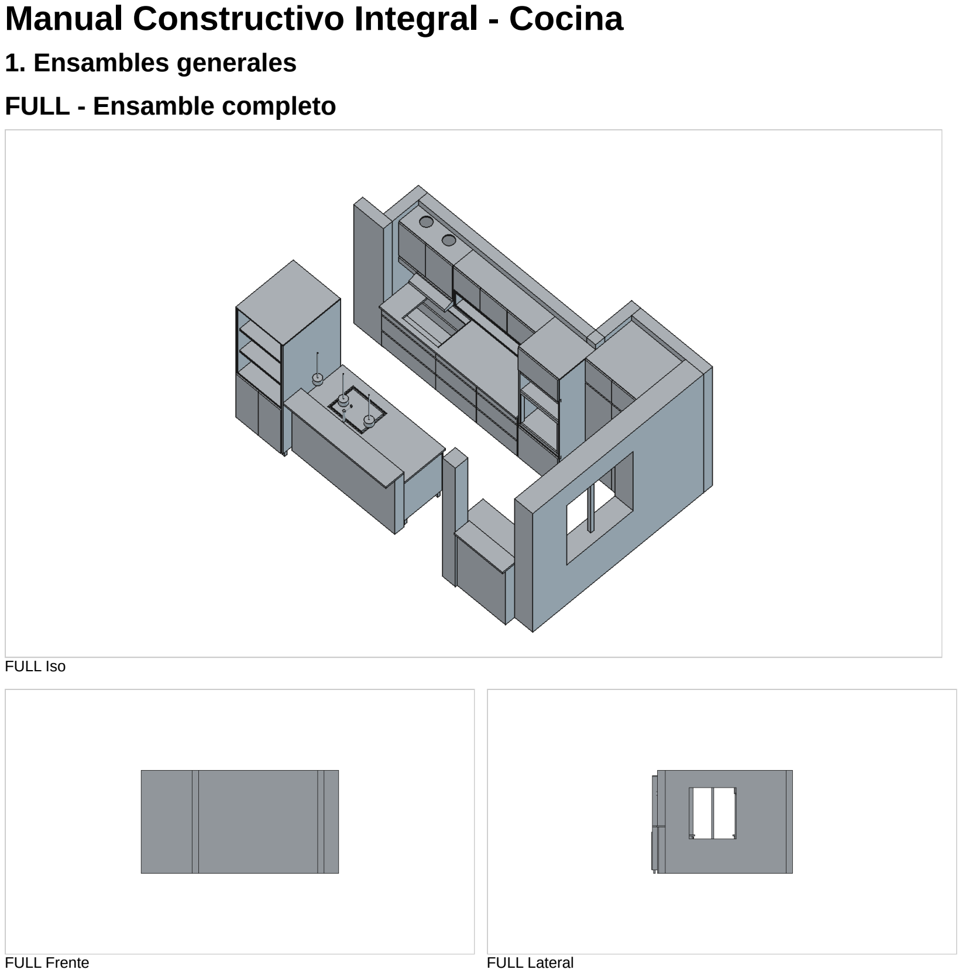
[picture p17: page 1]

## FULL - Ensamble completo

FULL Iso

FULL Frente | FULL Lateral

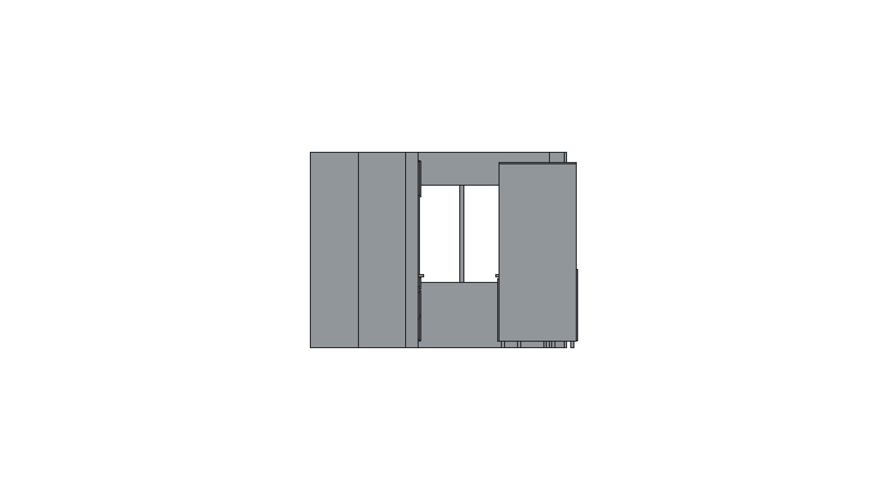
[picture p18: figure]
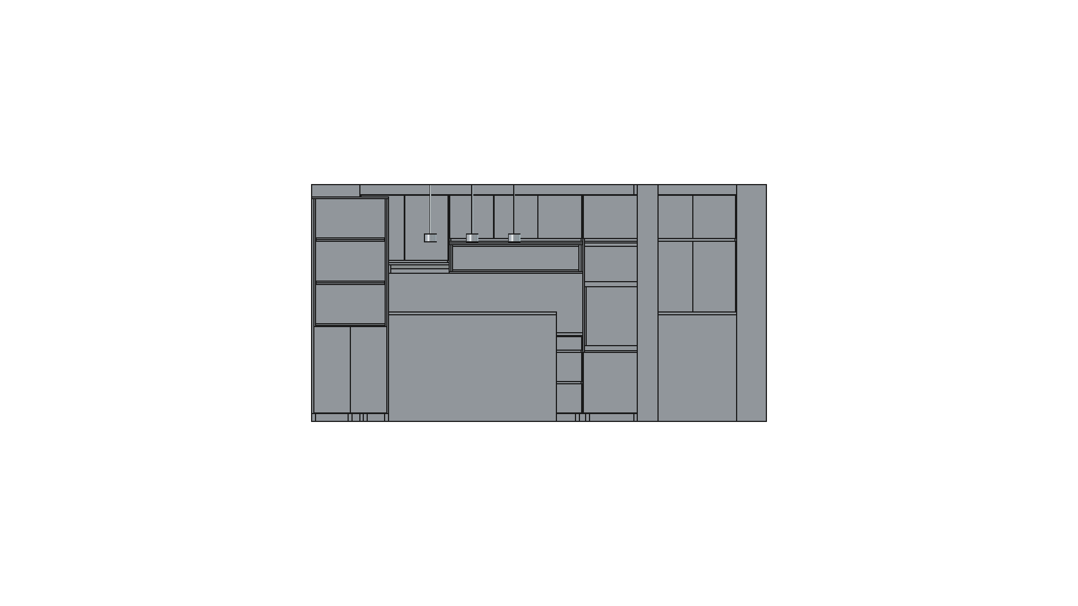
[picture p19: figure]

FULL Lateral opuesto | FULL Posterior

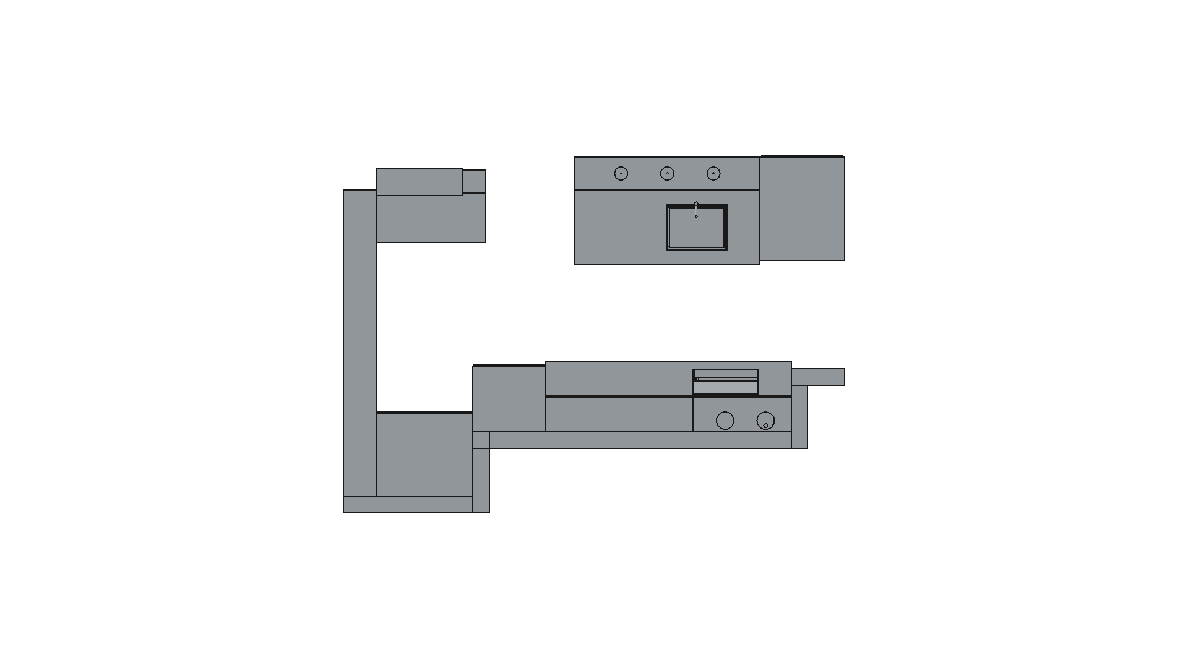
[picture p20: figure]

FULL Superior

## ENS - Ensamble cocina principal

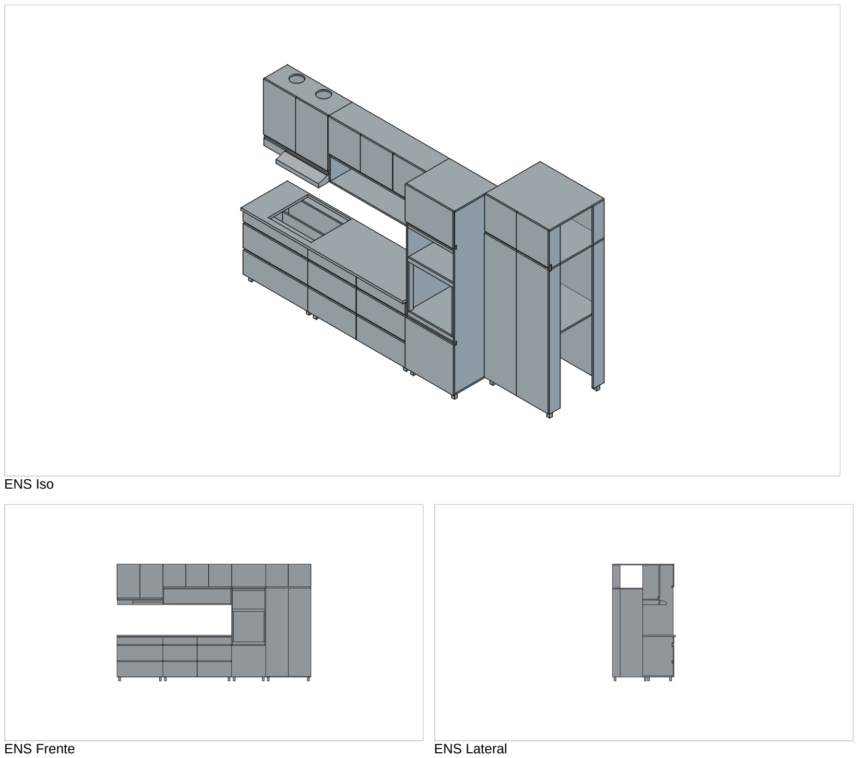
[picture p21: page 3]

ENS Iso

ENS Frente | ENS Lateral

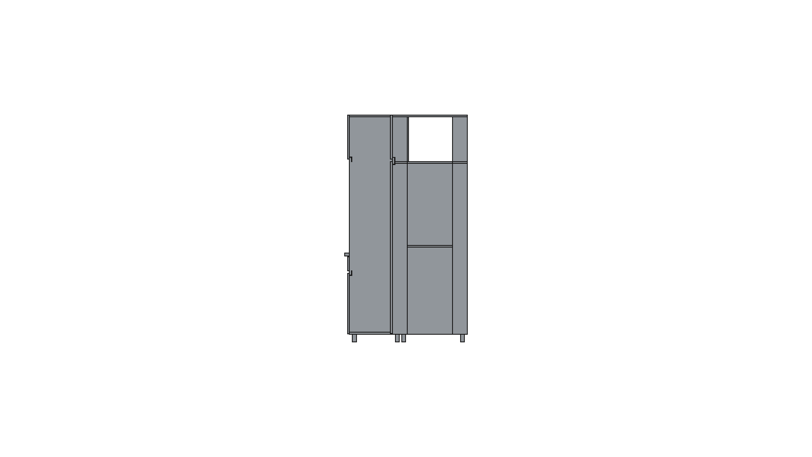
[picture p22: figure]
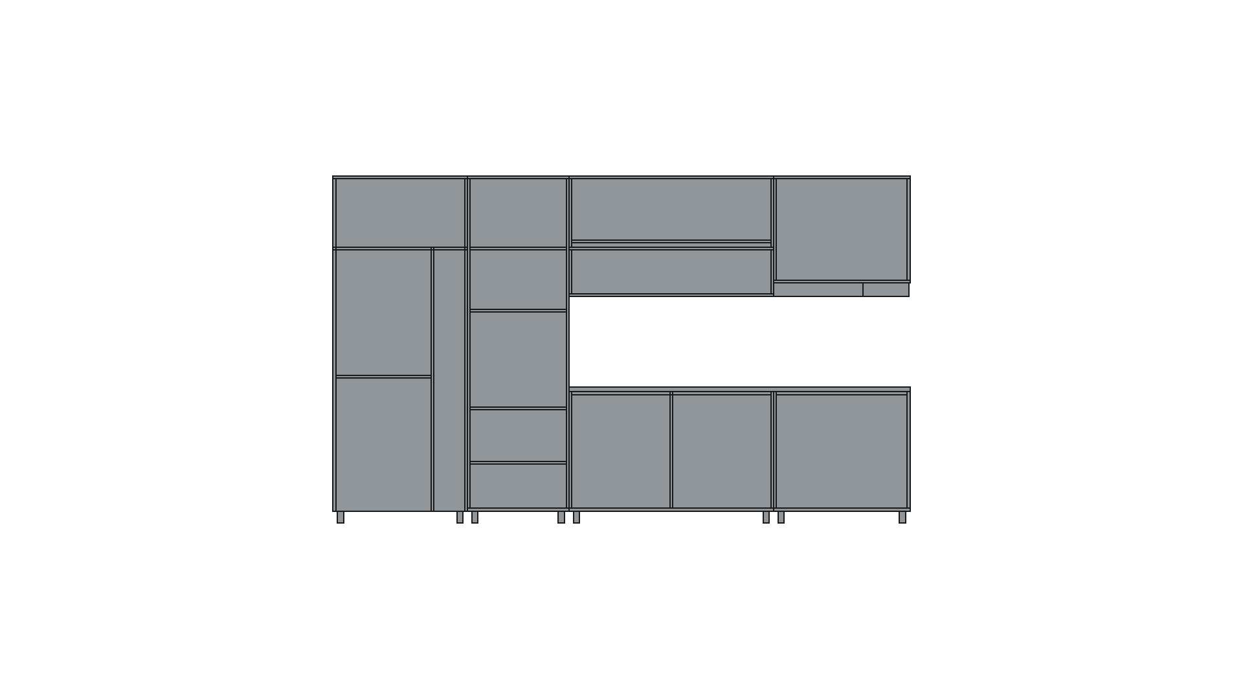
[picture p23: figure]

ENS Lateral opuesto | ENS Posterior

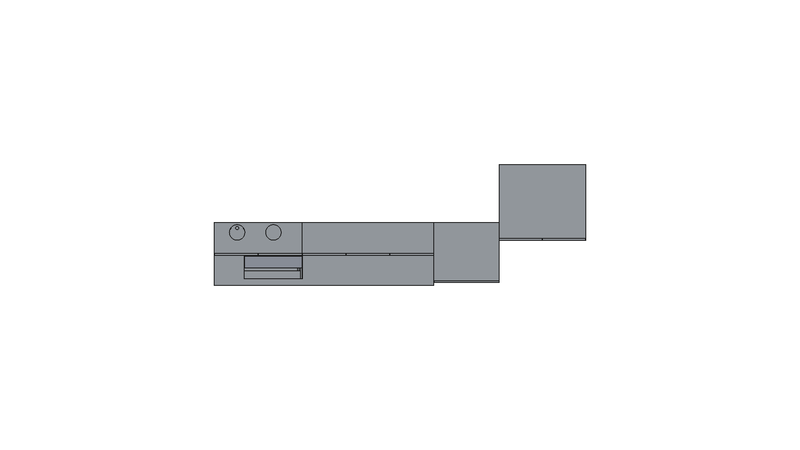
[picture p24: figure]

ENS Superior

## ENSI - Ensamble isla

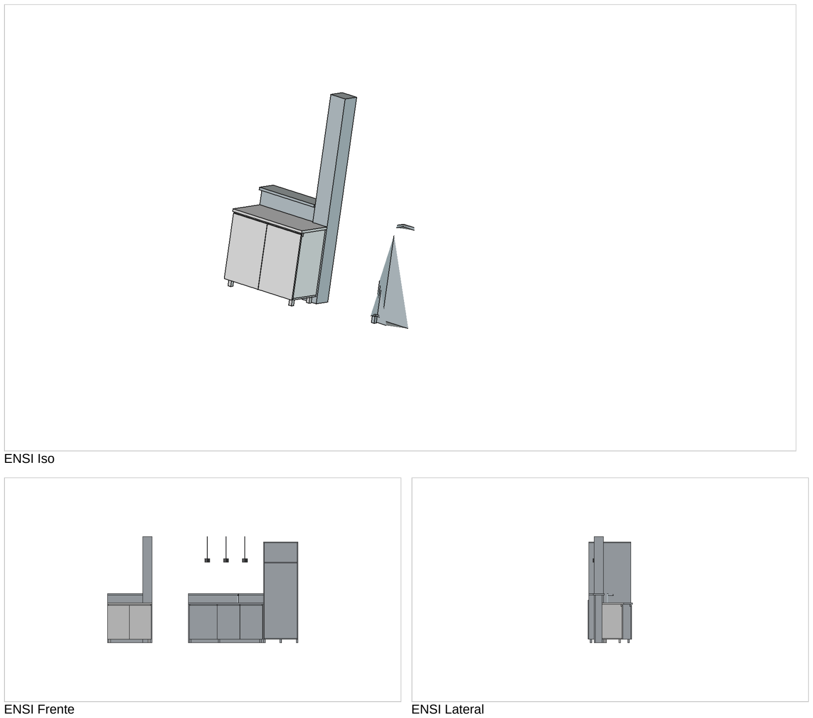
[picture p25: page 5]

ENSI Iso

ENSI Frente | ENSI Lateral

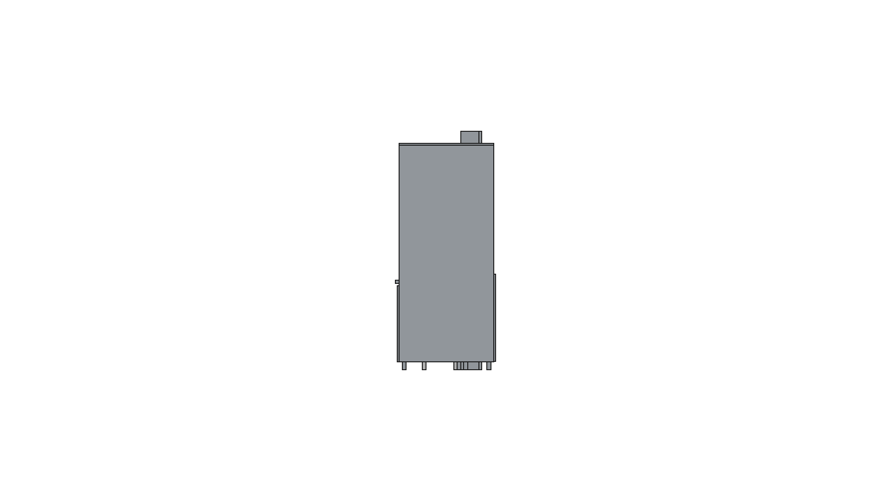
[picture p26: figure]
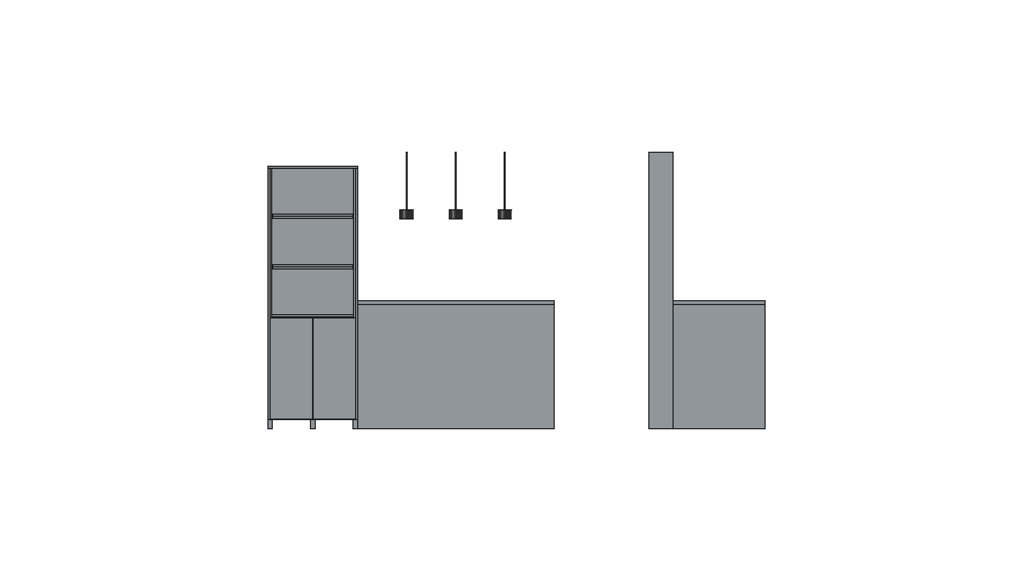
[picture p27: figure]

ENSI Lateral opuesto | ENSI Posterior

ENSI Superior

## 2. Lista unica total de partes

Categoria | Pieza | Cant total | Largo | Ancho | Espesor | Cantos | Modulos | ML gola | Bisagras
Cajon | Caja_Bot_Der_Frente_Caja | 1 | 589.1 | 180.0 | 18.0 | 4 cantos | BB
Cajon | Caja_Bot_Der_Trasera_Caja | 1 | 589.1 | 180.0 | 18.0 | Sin canto | BB
Cajon | Caja_Bot_Frente_Caja | 1 | 805.6 | 180.0 | 18.0 | 4 cantos | BA
Cajon | Caja_Bot_Izq_Frente_Caja | 1 | 589.1 | 180.0 | 18.0 | 4 cantos | BB
Cajon | Caja_Bot_Izq_Trasera_Caja | 1 | 589.1 | 180.0 | 18.0 | Sin canto | BB
Cajon | Caja_Bot_Trasera_Caja | 1 | 805.6 | 180.0 | 18.0 | Sin canto | BA
Cajon | Caja_Mid_Der_Frente_Caja | 1 | 589.1 | 180.0 | 18.0 | 4 cantos | BB
Cajon | Caja_Mid_Der_Trasera_Caja | 1 | 589.1 | 180.0 | 18.0 | Sin canto | BB
Cajon | Caja_Mid_Frente_Caja | 1 | 805.6 | 180.0 | 18.0 | 4 cantos | BA
Cajon | Caja_Mid_Izq_Frente_Caja | 1 | 589.1 | 180.0 | 18.0 | 4 cantos | BB
Cajon | Caja_Mid_Izq_Trasera_Caja | 1 | 589.1 | 180.0 | 18.0 | Sin canto | BB
Cajon | Caja_Mid_Trasera_Caja | 1 | 805.6 | 180.0 | 18.0 | Sin canto | BA
Cajon | Caja_Top_Der_Frente_Caja | 1 | 589.1 | 60.0 | 18.0 | 4 cantos | BB
Cajon | Caja_Top_Der_Trasera_Caja | 1 | 589.1 | 60.0 | 18.0 | Sin canto | BB
Cajon | Caja_Top_Izq_Frente_Caja | 1 | 589.1 | 60.0 | 18.0 | 4 cantos | BB
Cajon | Caja_Top_Izq_Trasera_Caja | 1 | 589.1 | 60.0 | 18.0 | Sin canto | BB
Casco | Caja_Bot_Der_Lateral_Der | 1 | 500.0 | 180.0 | 18.0 | Canto frente | BB
Casco | Caja_Bot_Der_Lateral_Izq | 1 | 500.0 | 180.0 | 18.0 | Canto frente | BB
Casco | Caja_Bot_Izq_Lateral_Der | 1 | 500.0 | 180.0 | 18.0 | Canto frente | BB
Casco | Caja_Bot_Izq_Lateral_Izq | 1 | 500.0 | 180.0 | 18.0 | Canto frente | BB
Casco | Caja_Bot_Lateral_Der | 1 | 500.0 | 180.0 | 18.0 | Canto frente | BA
Casco | Caja_Bot_Lateral_Izq | 1 | 500.0 | 180.0 | 18.0 | Canto frente | BA
Casco | Caja_Mid_Der_Lateral_Der | 1 | 500.0 | 180.0 | 18.0 | Canto frente | BB
Casco | Caja_Mid_Der_Lateral_Izq | 1 | 500.0 | 180.0 | 18.0 | Canto frente | BB
Casco | Caja_Mid_Izq_Lateral_Der | 1 | 500.0 | 180.0 | 18.0 | Canto frente | BB
Casco | Caja_Mid_Izq_Lateral_Izq | 1 | 500.0 | 180.0 | 18.0 | Canto frente | BB
Casco | Caja_Mid_Lateral_Der | 1 | 500.0 | 180.0 | 18.0 | Canto frente | BA
Casco | Caja_Mid_Lateral_Izq | 1 | 500.0 | 180.0 | 18.0 | Canto frente | BA
Casco | Caja_Top_Der_Lateral_Der | 1 | 500.0 | 60.0 | 18.0 | Canto frente | BB
Casco | Caja_Top_Der_Lateral_Izq | 1 | 500.0 | 60.0 | 18.0 | Canto frente | BB
Casco | Caja_Top_Izq_Lateral_Der | 1 | 500.0 | 60.0 | 18.0 | Canto frente | BB

Categoria | Pieza | Cant total | Largo | Ancho | Espesor | Cantos | Modulos | ML gola | Bisagras
Casco | Caja_Top_Izq_Lateral_Izq | 1 | 500.0 | 60.0 | 18.0 | Canto frente | BB
Casco | Extractor_Ref | 1 | 590.0 | 470.0 | 90.0 | Sin canto | AA
Casco | Faja_Frontal_50 | 1 | 636.0 | 50.0 | 18.0 | Sin canto | H
Casco | Faja_Frontal_Inferior_50 | 1 | 636.0 | 50.0 | 18.0 | Sin canto | H
Casco | Faja_Frontal_Superior_Micro_50 | 1 | 636.0 | 50.0 | 18.0 | Sin canto | H
Casco | Lateral_Der | 1 | 674.0 | 320.0 | 18.0 | Canto frente | AA
Casco | Lateral_Der | 1 | 455.0 | 320.0 | 18.0 | Canto frente | AB
Casco | Lateral_Der | 1 | 320.0 | 291.0 | 18.0 | Canto frente | AB
Casco | Lateral_Der | 2 | 772.0 | 600.0 | 18.0 | Canto frente | BA,BB
Casco | Lateral_Der | 1 | 2180.0 | 950.0 | 18.0 | Canto frente | F
Casco | Lateral_Der | 1 | 2184.0 | 600.0 | 18.0 | Canto frente | H
Casco | Lateral_Der | 1 | 772.0 | 650.0 | 18.0 | Canto frente | I
Casco | Lateral_Der | 1 | 790.0 | 420.0 | 18.0 | Canto frente | R
Casco | Lateral_Izq | 1 | 674.0 | 320.0 | 18.0 | Canto frente | AA
Casco | Lateral_Izq | 1 | 455.0 | 320.0 | 18.0 | Canto frente | AB
Casco | Lateral_Izq | 1 | 320.0 | 291.0 | 18.0 | Canto frente | AB
Casco | Lateral_Izq | 2 | 772.0 | 600.0 | 18.0 | Canto frente | BA,BB
Casco | Lateral_Izq | 1 | 2180.0 | 950.0 | 18.0 | Canto frente | F
Casco | Lateral_Izq | 1 | 2184.0 | 600.0 | 18.0 | Canto frente | H
Casco | Lateral_Izq | 1 | 790.0 | 450.0 | 18.0 | Canto frente | R
Casco | Lateral_Izq_Frente | 1 | 790.0 | 650.0 | 18.0 | 4 cantos | I
Casco | Liston_Fijo_90 | 1 | 885.0 | 90.0 | 18.0 | Sin canto | AA
Casco | Liston_Vert_Der | 1 | 631.0 | 60.0 | 18.0 | Sin canto | H
Casco | Liston_Vert_Izq | 1 | 631.0 | 60.0 | 18.0 | Sin canto | H
Casco | Piso | 1 | 1319.0 | 295.6 | 18.0 | Canto frente | AB
Casco | Piso | 1 | 1355.0 | 320.0 | 18.0 | Canto frente | AB
Casco | Piso | 1 | 990.0 | 450.0 | 18.0 | Canto frente | R
Casco | Piso_Casco | 1 | 903.0 | 320.0 | 18.0 | Canto frente | AA
Casco | Piso_Casco | 1 | 672.0 | 600.0 | 18.0 | Canto frente | H
Casco | Piso_Der | 1 | 1037.0 | 650.0 | 18.0 | Canto frente | I
Casco | Piso_Falso_Lavavajillas | 1 | 612.0 | 601.0 | 18.0 | Canto frente | I
Casco | Piso_Horno | 1 | 636.0 | 582.0 | 18.0 | Canto frente | H
Casco | Piso_Micro | 1 | 636.0 | 582.0 | 18.0 | Canto frente | H
Casco | Piso_Modular | 1 | 744.0 | 300.0 | 18.0 | Canto frente | F
Casco | Piso_Modulo_Superior | 1 | 890.0 | 734.0 | 18.0 | Canto frente | L
Casco | Piso_Pasante | 1 | 903.0 | 600.0 | 18.0 | Canto frente | BA
Casco | Piso_Pasante | 1 | 1355.0 | 600.0 | 18.0 | Canto frente | BB
Casco | Piso_Removible_Lavavajillas | 1 | 612.0 | 601.0 | 18.0 | Canto frente | I
Casco | Soporte_Sup_Fondo | 1 | 1037.0 | 100.0 | 18.0 | Canto frente | I
Casco | Soporte_Sup_Frente | 1 | 1624.0 | 100.0 | 18.0 | 4 cantos | I
Casco | Soporte_Superior_Fondo | 1 | 867.0 | 100.0 | 18.0 | Canto frente | BA
Casco | Soporte_Superior_Fondo | 1 | 1319.0 | 100.0 | 18.0 | Canto frente | BB
Casco | Soporte_Superior_Frente | 1 | 867.0 | 100.0 | 18.0 | 4 cantos | BA
Casco | Soporte_Superior_Frente | 1 | 1319.0 | 100.0 | 18.0 | 4 cantos | BB
Casco | Tapa | 2 | 1355.0 | 320.0 | 18.0 | Sin canto | AB
Casco | Tapa_Casco | 1 | 903.0 | 320.0 | 18.0 | Sin canto | AA
Casco | Tapa_Casco | 1 | 672.0 | 600.0 | 18.0 | Sin canto | H
Casco | Tapa_Casco | 1 | 890.0 | 760.0 | 18.0 | Sin canto | L
Casco | Tapa_Micro | 1 | 636.0 | 600.0 | 18.0 | Sin canto | H
Casco | Techo_Heladera_1800 | 1 | 740.0 | 650.0 | 18.0 | Sin canto | F
Casco | Techo_Lavarropas_Der | 1 | 760.0 | 630.0 | 18.0 | Sin canto | L
Casco | Travesano_Sup_Trasero | 1 | 764.0 | 100.0 | 18.0 | Sin canto | R
Division | Division_1 | 1 | 772.0 | 650.0 | 18.0 | Canto frente | I
Division | Division_2 | 1 | 772.0 | 650.0 | 18.0 | Canto frente | I
Division | Divisor_Central | 1 | 772.0 | 600.0 | 18.0 | Canto frente | BB
Division | Panel_Divisor_Prof | 1 | 2180.0 | 744.0 | 18.0 | Canto frente | F
Division | Parante_Front_Der | 1 | 2202.0 | 150.0 | 18.0 | Canto frente | L

Categoria | Pieza | Cant total | Largo | Ancho | Espesor | Cantos | Modulos | ML gola | Bisagras
Division | Parante_Front_Izq | 1 | 2202.0 | 150.0 | 18.0 | Canto frente | L
Division | Parante_Interior | 1 | 1747.0 | 760.0 | 18.0 | Canto frente | L
Division | Parante_Rear_Der | 1 | 2202.0 | 150.0 | 18.0 | Canto frente | L
Division | Parante_Rear_Izq | 1 | 2202.0 | 150.0 | 18.0 | Canto frente | L
Estante_Regulable | Estante_Bajo_Reg | 1 | 708.0 | 282.0 | 18.0 | Canto frente | F
Estante_Regulable | Estante_Fijo_Interior | 1 | 708.0 | 282.0 | 18.0 | Canto frente | F
Estante_Regulable | Estante_Inferior | 1 | 636.0 | 600.0 | 18.0 | Canto frente | H
Estante_Regulable | Estante_Regulable | 1 | 760.0 | 442.0 | 18.0 | Canto frente | R
Estante_Regulable | Estante_Regulable_Bacha | 1 | 612.0 | 509.8 | 18.0 | Canto frente | I
Estante_Regulable | Estante_Sup_Reg_1 | 1 | 692.0 | 262.0 | 18.0 | Canto frente | F
Estante_Regulable | Estante_Sup_Reg_2 | 1 | 692.0 | 262.0 | 18.0 | Canto frente | F
Estante_Regulable | Regrueso_Front_Estante_Sup_1 | 1 | 692.0 | 50.0 | 18.0 | Crudo (cinta 36mm en obra) | F
Estante_Regulable | Regrueso_Front_Estante_Sup_2 | 1 | 692.0 | 50.0 | 18.0 | Crudo (cinta 36mm en obra) | F
Estante_Regulable | Techo_Modulo_Estantes | 1 | 950.0 | 780.0 | 18.0 | Canto frente | F
Fondo | Caja_Bot_Der_Fondo_6mm | 1 | 625.1 | 500.0 | 6.0 | Fondo clavado pasante | BB
Fondo | Caja_Bot_Fondo_6mm | 1 | 841.6 | 500.0 | 6.0 | Fondo clavado pasante | BA
Fondo | Caja_Bot_Izq_Fondo_6mm | 1 | 625.1 | 500.0 | 6.0 | Fondo clavado pasante | BB
Fondo | Caja_Mid_Der_Fondo_6mm | 1 | 625.1 | 500.0 | 6.0 | Fondo clavado pasante | BB
Fondo | Caja_Mid_Fondo_6mm | 1 | 841.6 | 500.0 | 6.0 | Fondo clavado pasante | BA
Fondo | Caja_Mid_Izq_Fondo_6mm | 1 | 625.1 | 500.0 | 6.0 | Fondo clavado pasante | BB
Fondo | Caja_Top_Der_Fondo_6mm | 1 | 625.1 | 500.0 | 6.0 | Fondo clavado pasante | BB
Fondo | Caja_Top_Izq_Fondo_6mm | 1 | 625.1 | 500.0 | 6.0 | Fondo clavado pasante | BB
Fondo | Fondo_18mm | 1 | 1319.0 | 291.0 | 18.0 | Sin canto | AB
Fondo | Fondo_3mm | 1 | 867.0 | 674.0 | 3.0 | Sin canto | AA
Fondo | Fondo_3mm | 1 | 1319.0 | 455.0 | 3.0 | Sin canto | AB
Fondo | Fondo_3mm | 1 | 867.0 | 772.0 | 3.0 | Sin canto | BA
Fondo | Fondo_3mm | 1 | 1319.0 | 772.0 | 3.0 | Sin canto | BB
Fondo | Fondo_3mm | 1 | 2184.0 | 636.0 | 3.0 | Sin canto | H
Fondo | Fondo_3mm | 1 | 2202.0 | 854.0 | 3.0 | Sin canto | L
Fondo | Fondo_6mm | 1 | 954.0 | 790.0 | 36.0 | Fondo clavado pasante | R
Frente | Frente_Bot | 1 | 903.0 | 293.0 | 18.0 | 4 cantos | BA
Frente | Frente_Bot_Der | 1 | 679.0 | 293.0 | 18.0 | 4 cantos | BB
Frente | Frente_Bot_Izq | 1 | 672.0 | 293.0 | 18.0 | 4 cantos | BB
Frente | Frente_Der | 1 | 666.0 | 448.0 | 18.0 | 4 cantos | AA
Frente | Frente_Falso_Sup | 1 | 903.0 | 139.0 | 18.0 | 4 cantos | BA
Frente | Frente_Izq | 1 | 666.0 | 448.0 | 18.0 | 4 cantos | AA
Frente | Frente_Mid | 1 | 903.0 | 293.0 | 18.0 | 4 cantos | BA
Frente | Frente_Mid_Der | 1 | 679.0 | 293.0 | 18.0 | 4 cantos | BB
Frente | Frente_Mid_Izq | 1 | 672.0 | 293.0 | 18.0 | 4 cantos | BB
Frente | Frente_Top_Der | 1 | 679.0 | 139.0 | 18.0 | 4 cantos | BB
Frente | Frente_Top_Izq | 1 | 672.0 | 139.0 | 18.0 | 4 cantos | BB

Categoria | Pieza | Cant total | Largo | Ancho | Espesor | Cantos | Modulos | ML gola | Bisagras
Frente | Puerta_1 | 1 | 448.3 | 447.0 | 18.0 | 4 cantos | AB
Frente | Puerta_2 | 1 | 448.3 | 447.0 | 18.0 | 4 cantos | AB
Frente | Puerta_3 | 1 | 448.3 | 447.0 | 18.0 | 4 cantos | AB
Frente | Puerta_Bacha_Der | 1 | 764.0 | 510.8 | 18.0 | 4 cantos | I
Frente | Puerta_Bacha_Izq | 1 | 764.0 | 510.8 | 18.0 | 4 cantos | I
Frente | Puerta_Der | 1 | 768.0 | 493.5 | 18.0 | 4 cantos | R
Frente | Puerta_Inf_Der | 1 | 1738.0 | 444.0 | 18.0 | 4 cantos | L
Frente | Puerta_Inf_Izq | 1 | 1738.0 | 444.0 | 18.0 | 4 cantos | L
Frente | Puerta_Inferior | 1 | 672.0 | 612.0 | 18.0 | 4 cantos | H
Frente | Puerta_Izq | 1 | 768.0 | 493.5 | 18.0 | 4 cantos | R
Frente | Puerta_Lavavajillas | 1 | 764.0 | 628.5 | 18.0 | 4 cantos | I
Frente | Puerta_Mod_Der | 1 | 877.0 | 369.0 | 18.0 | 4 cantos | F
Frente | Puerta_Mod_Izq | 1 | 877.0 | 369.0 | 18.0 | 4 cantos | F
Frente | Puerta_Sup_Der | 1 | 447.0 | 441.5 | 18.0 | 4 cantos | L
Frente | Puerta_Sup_Izq | 1 | 447.0 | 441.5 | 18.0 | 4 cantos | L
Frente | Puerta_Superior | 1 | 668.0 | 447.0 | 18.0 | 4 cantos | H
Herraje | Gola_C_Media | 1 | 890.0 | 72.8 | 26.0 | Aluminio | L
Herraje | Gola_C_Superior | 1 | 903.0 | 72.8 | 26.0 | Aluminio | BA
Herraje | Gola_C_Superior | 1 | 1355.0 | 72.8 | 26.0 | Aluminio | BB
Herraje | Gola_J_Continuidad | 1 | 672.0 | 48.0 | 24.4 | Aluminio | H
Herraje | Gola_J_Inferior | 1 | 903.0 | 48.0 | 24.4 | Aluminio | AA
Herraje | Gola_J_Inferior | 1 | 1355.0 | 48.0 | 24.4 | Aluminio | AB
Herraje | Gola_J_Media | 1 | 903.0 | 48.0 | 24.4 | Aluminio | BA
Herraje | Gola_J_Media | 1 | 1355.0 | 48.0 | 24.4 | Aluminio | BB
Herraje | Gola_J_Sup | 1 | 672.0 | 48.0 | 24.4 | Aluminio | H
Herraje | Gola_J_Superior | 1 | 1660.0 | 48.0 | 24.4 | Aluminio | I
Herraje | Gola_J_Superior | 1 | 990.0 | 48.0 | 24.4 | Aluminio | R
Herraje | Pata_1 | 6 | 80.0 | 40.0 | 40.0 | PVC/Aluminio | BA,BB,F,H,L,R
Herraje | Pata_2 | 6 | 80.0 | 40.0 | 40.0 | PVC/Aluminio | BA,BB,F,H,L,R
Herraje | Pata_3 | 6 | 80.0 | 40.0 | 40.0 | PVC/Aluminio | BA,BB,F,H,L,R
Herraje | Pata_4 | 6 | 80.0 | 40.0 | 40.0 | PVC/Aluminio | BA,BB,F,H,L,R
Herraje | Pata_5 | 1 | 80.0 | 40.0 | 40.0 | PVC/Aluminio | F
Herraje | Pata_Back_1 | 1 | 80.0 | 40.0 | 40.0 | PVC/Aluminio | I
Herraje | Pata_Back_2 | 1 | 80.0 | 40.0 | 40.0 | PVC/Aluminio | I
Herraje | Pata_Back_3 | 1 | 80.0 | 40.0 | 40.0 | PVC/Aluminio | I
Herraje | Pata_Front_1 | 1 | 80.0 | 40.0 | 40.0 | PVC/Aluminio | I
Herraje | Pata_Front_2 | 1 | 80.0 | 40.0 | 40.0 | PVC/Aluminio | I
Herraje | Pata_Front_3 | 1 | 80.0 | 40.0 | 40.0 | PVC/Aluminio | I
Mesada | Mesada | 1 | 1010.0 | 488.0 | 30.0 | Sin canto | R
Mesada | Mesada_Calado_Bacha | 1 | 1700.0 | 688.0 | 30.0 | Sin canto | I
Mesada | Mesada_Gris_Mara | 1 | 2258.0 | 648.0 | 30.0 | Sin canto | M
Regrueso | Regrueso_Sobre_F9 | 1 | 708.0 | 50.0 | 18.0 | Crudo (cinta 36mm en obra) | F
Regrueso | Regrueso_Techo_Lav | 1 | 630.0 | 60.0 | 18.0 | Crudo (cinta 36mm en obra) | L
Regrueso | Regrueso_Vis_Der | 1 | 2162.0 | 282.0 | 18.0 | Crudo (cinta 36mm en obra) | F
Regrueso | Regrueso_Vis_Izq | 1 | 2162.0 | 282.0 | 18.0 | Crudo (cinta 36mm en obra) | F

## 3. Modulos Modulo H - Columna horno + micro

Terminacion: Melamina blanca

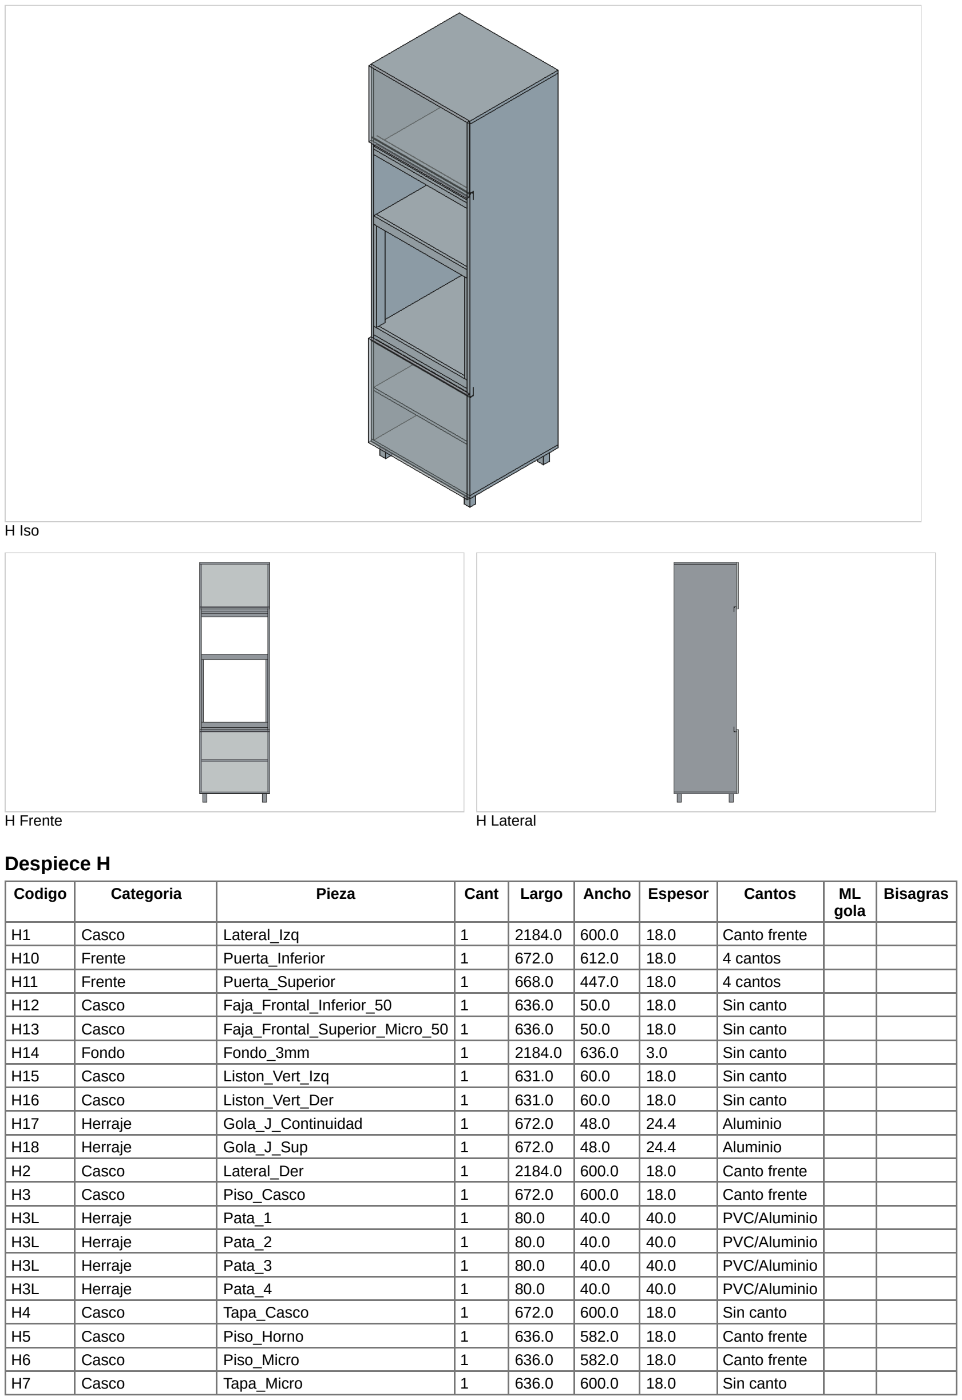
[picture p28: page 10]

H Iso

H Frente | H Lateral

### Despiece H

Codigo | Categoria | Pieza | Cant | Largo | Ancho | Espesor | Cantos | ML gola | Bisagras
H1 | Casco | Lateral_Izq | 1 | 2184.0 | 600.0 | 18.0 | Canto frente
H10 | Frente | Puerta_Inferior | 1 | 672.0 | 612.0 | 18.0 | 4 cantos
H11 | Frente | Puerta_Superior | 1 | 668.0 | 447.0 | 18.0 | 4 cantos
H12 | Casco | Faja_Frontal_Inferior_50 | 1 | 636.0 | 50.0 | 18.0 | Sin canto
H13 | Casco | Faja_Frontal_Superior_Micro_50 | 1 | 636.0 | 50.0 | 18.0 | Sin canto
H14 | Fondo | Fondo_3mm | 1 | 2184.0 | 636.0 | 3.0 | Sin canto
H15 | Casco | Liston_Vert_Izq | 1 | 631.0 | 60.0 | 18.0 | Sin canto
H16 | Casco | Liston_Vert_Der | 1 | 631.0 | 60.0 | 18.0 | Sin canto
H17 | Herraje | Gola_J_Continuidad | 1 | 672.0 | 48.0 | 24.4 | Aluminio
H18 | Herraje | Gola_J_Sup | 1 | 672.0 | 48.0 | 24.4 | Aluminio
H2 | Casco | Lateral_Der | 1 | 2184.0 | 600.0 | 18.0 | Canto frente
H3 | Casco | Piso_Casco | 1 | 672.0 | 600.0 | 18.0 | Canto frente
H3L | Herraje | Pata_1 | 1 | 80.0 | 40.0 | 40.0 | PVC/Aluminio
H3L | Herraje | Pata_2 | 1 | 80.0 | 40.0 | 40.0 | PVC/Aluminio
H3L | Herraje | Pata_3 | 1 | 80.0 | 40.0 | 40.0 | PVC/Aluminio
H3L | Herraje | Pata_4 | 1 | 80.0 | 40.0 | 40.0 | PVC/Aluminio
H4 | Casco | Tapa_Casco | 1 | 672.0 | 600.0 | 18.0 | Sin canto
H5 | Casco | Piso_Horno | 1 | 636.0 | 582.0 | 18.0 | Canto frente
H6 | Casco | Piso_Micro | 1 | 636.0 | 582.0 | 18.0 | Canto frente
H7 | Casco | Tapa_Micro | 1 | 636.0 | 600.0 | 18.0 | Sin canto

Codigo | Categoria | Pieza | Cant | Largo | Ancho | Espesor | Cantos | ML gola | Bisagras
H8 | Estante_Regulable | Estante_Inferior | 1 | 636.0 | 600.0 | 18.0 | Canto frente
H9 | Casco | Faja_Frontal_50 | 1 | 636.0 | 50.0 | 18.0 | Sin canto

### Notas de armado H

# Columna horno + microondas (melamina 18 mm)

## Parametros usados

Altura total: 2300 mm
Profundidad total: 600 mm
Ancho interior util: 636 mm
Ancho exterior: 672 mm
Patas: 80 mm (ocultas por zocalo)
Fondo 3 mm (oculto en vistas de captura)
Piso y techo del casco pasantes (672 mm), con laterales apoyados Laterales entre piso y techo (36 mm menos de altura respecto al casco) Piso de horno y piso de micro retranqueados 18 mm (profundidad 582 mm)

## Codigos de piezas (prefijo H)

H1: Lateral izquierdo
H2: Lateral derecho
H3: Piso casco (pasante)
H4: Tapa casco (pasante)
H5: Piso horno
H6: Piso micro
H7: Tapa micro
H8: Estante inferior
H9: Faja frontal central 50 mm (entre horno y micro)
H10: Puerta inferior
H11: Puerta superior
H12: Faja frontal inferior 50 mm (entre puerta inferior y horno)
H13: Faja frontal superior micro 50 mm (techo del hueco micro)
H14: Fondo 3 mm
H15: Liston vertical frontal izq (18 mm frente x 60 mm fondo, solo horno) H16: Liston vertical frontal der (18 mm frente x 60 mm fondo, solo horno) Hueco horno visible: 600 x 599 mm, arranque a 800 mm desde piso
Hueco horno interno: 600 x 650 mm
Hueco microondas: 600 x 436 mm
Hueco microondas arranca a 1449 mm desde piso (enrasado con faja intermedia) Fajas frontales: 3 unidades de 50 mm
Arriba del micro: puerta
Abajo del horno: puerta + 1 estante intermedio

## Logica del “regrueso” frontal

Se deja 50 mm extra internos por encima del horno (hueco interno de 650 mm), y se tapa visualmente con una faja frontal central de 50 mm. De frente se percibe una separacion marcada entre horno y micro, pero el horno internamente queda con aire superior extra.

## Herrajes sugeridos

4 patas regulables de 80 mm (o 6 si queres mayor rigidez)
4 bisagras cazoleta 35 mm para puerta inferior (apertura derecha) 3 bisagras cazoleta 35 mm para puerta superior
1 juego de soportes para estante interior
Tornillos confirmat 5x50 o sistema minifix (segun tu preferencia)

## Secuencia de armado (resumen)

1. Cortar y cantear piezas segun BOM.
2. Pre-taladrar laterales para pisos/tapas/estante.
3. Armar casco: laterales + piso inferior + tapa superior.
4. Instalar piso horno, piso micro y tapa micro a cotas definidas.
5. Instalar estante interior inferior a media altura.
6. Colocar las 3 fajas frontales de 50 mm (inferior horno, central y techo micro).

## Nota de validacion

## Modulo AA - Alacena izquierda

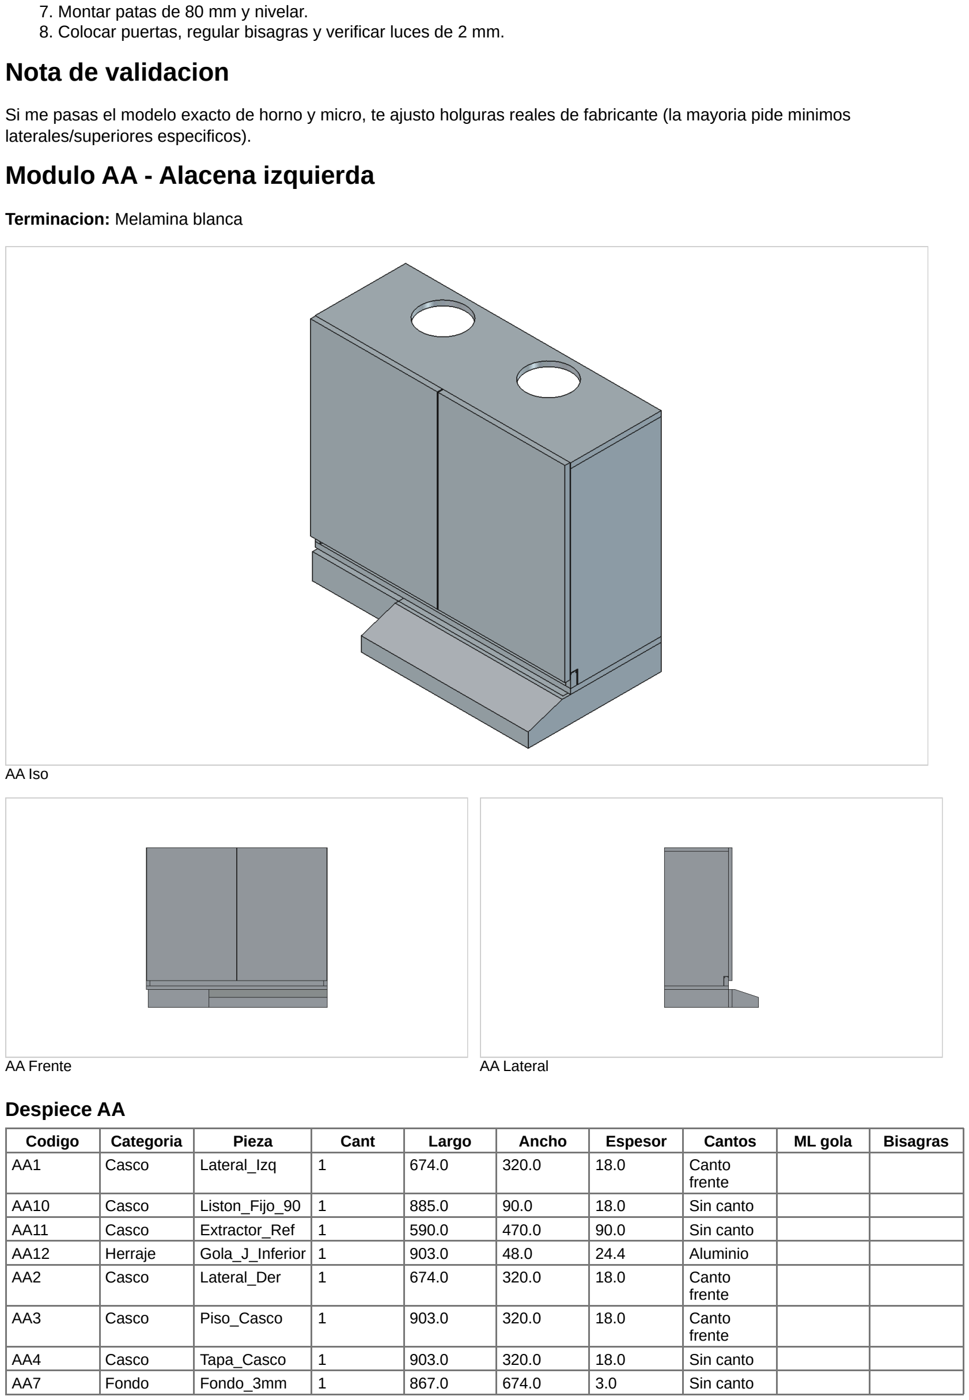
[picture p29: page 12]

7. Montar patas de 80 mm y nivelar.
8. Colocar puertas, regular bisagras y verificar luces de 2 mm.

Si me pasas el modelo exacto de horno y micro, te ajusto holguras reales de fabricante (la mayoria pide minimos laterales/superiores especificos).

Terminacion: Melamina blanca

AA Iso

AA Frente | AA Lateral

### Despiece AA

Codigo | Categoria | Pieza | Cant | Largo | Ancho | Espesor | Cantos | ML gola | Bisagras
AA1 | Casco | Lateral_Izq | 1 | 674.0 | 320.0 | 18.0 | Canto frente
AA10 | Casco | Liston_Fijo_90 | 1 | 885.0 | 90.0 | 18.0 | Sin canto
AA11 | Casco | Extractor_Ref | 1 | 590.0 | 470.0 | 90.0 | Sin canto
AA12 | Herraje | Gola_J_Inferior | 1 | 903.0 | 48.0 | 24.4 | Aluminio
AA2 | Casco | Lateral_Der | 1 | 674.0 | 320.0 | 18.0 | Canto frente
AA3 | Casco | Piso_Casco | 1 | 903.0 | 320.0 | 18.0 | Canto frente
AA4 | Casco | Tapa_Casco | 1 | 903.0 | 320.0 | 18.0 | Sin canto
AA7 | Fondo | Fondo_3mm | 1 | 867.0 | 674.0 | 3.0 | Sin canto

Codigo | Categoria | Pieza | Cant | Largo | Ancho | Espesor | Cantos | ML gola | Bisagras
AA8 | Frente | Frente_Izq | 1 | 666.0 | 448.0 | 18.0 | 4 cantos
AA9 | Frente | Frente_Der | 1 | 666.0 | 448.0 | 18.0 | 4 cantos

### Notas de armado AA

# Alacena A (AA) - superior izquierda

## Parametros usados

Espesor melamina: 18 mm
Fondo: 3 mm
Ancho exterior: 1050 mm
Profundidad exterior: 320 mm
Alto del mueble: 680 mm
Piso y tapa pasantes (laterales entre piso y tapa)
Interior dividido en 2 mitades iguales por divisor vertical central Estante solo en lado derecho, a media altura
2 puertas iguales (apertura desde centro hacia izquierda y derecha) Calado para ducto extractor: diametro 160 mm
Eje de calado centrado en modulo derecho y a 20 mm del fondo El calado atraviesa piso, estante derecho y tapa

## Instalacion recomendada (respecto a cocina)

Mesada: 900 mm
Techo: 2300 mm
Colocacion sugerida: base de alacena a 1620 mm
Con eso, la alacena llega al techo (1620 + 680 = 2300)

## Codigos de piezas (prefijo AA)

AA1: lateral izquierdo
AA2: lateral derecho
AA3: piso casco (calado 160)
AA4: tapa casco (calado 160) AA5: divisor central
AA6: estante derecho
AA7: fondo 3 mm
AA8: puerta izquierda
AA9: puerta derecha

## Herrajes sugeridos

4 bisagras cazoleta 35 mm (2 por puerta)
1 tirador por puerta
Colgadores de alacena o escuadras segun sistema de fijacion Tornillos para melamina (confirmat 5x50 o equivalente) Soportes de estante

## Secuencia de armado

1. Cortar y cantear piezas segun BOM.
2. Armar casco: laterales + piso + techo.
3. Colocar divisor central y luego estante derecho a media altura.
4. Fijar fondo de 3 mm escuadrando el mueble.
5. Colocar puertas AA8 y AA9, regular bisagras y dejar luz central de 2 mm.
6. Ejecutar calado de 160 mm en piso/techo antes de montaje final en pared.

## Nota tecnica

El fondo se deja oculto en las capturas para mantener limpieza visual del modelo.
Si queres cambiar altura de colgado, modificar la cota de instalacion; el mueble sigue midiendo 680 mm.

## Modulo AB - Alacena derecha + cajon AC

Terminacion: AB blanco / AC simil paraiso

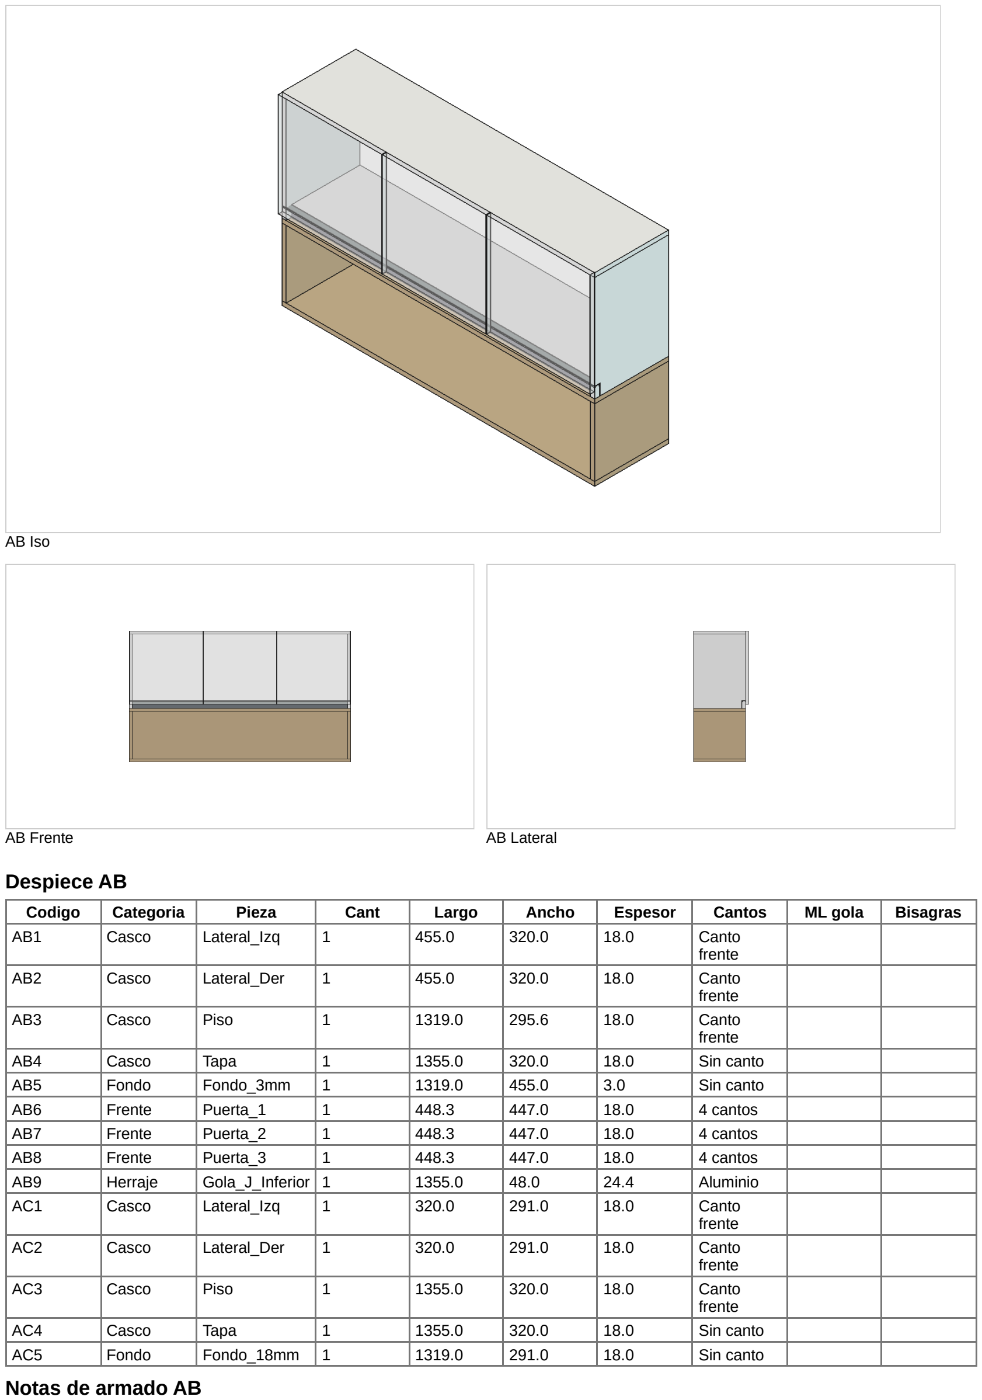
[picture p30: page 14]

AB Iso

AB Frente | AB Lateral

### Despiece AB

Codigo | Categoria | Pieza | Cant | Largo | Ancho | Espesor | Cantos | ML gola | Bisagras
AB1 | Casco | Lateral_Izq | 1 | 455.0 | 320.0 | 18.0 | Canto frente
AB2 | Casco | Lateral_Der | 1 | 455.0 | 320.0 | 18.0 | Canto frente
AB3 | Casco | Piso | 1 | 1319.0 | 295.6 | 18.0 | Canto frente
AB4 | Casco | Tapa | 1 | 1355.0 | 320.0 | 18.0 | Sin canto
AB5 | Fondo | Fondo_3mm | 1 | 1319.0 | 455.0 | 3.0 | Sin canto
AB6 | Frente | Puerta_1 | 1 | 448.3 | 447.0 | 18.0 | 4 cantos
AB7 | Frente | Puerta_2 | 1 | 448.3 | 447.0 | 18.0 | 4 cantos
AB8 | Frente | Puerta_3 | 1 | 448.3 | 447.0 | 18.0 | 4 cantos
AB9 | Herraje | Gola_J_Inferior | 1 | 1355.0 | 48.0 | 24.4 | Aluminio
AC1 | Casco | Lateral_Izq | 1 | 320.0 | 291.0 | 18.0 | Canto frente
AC2 | Casco | Lateral_Der | 1 | 320.0 | 291.0 | 18.0 | Canto frente
AC3 | Casco | Piso | 1 | 1355.0 | 320.0 | 18.0 | Canto frente
AC4 | Casco | Tapa | 1 | 1355.0 | 320.0 | 18.0 | Sin canto
AC5 | Fondo | Fondo_18mm | 1 | 1319.0 | 291.0 | 18.0 | Sin canto

### Notas de armado AB

# Conjunto derecho AB + AC

## Parametros

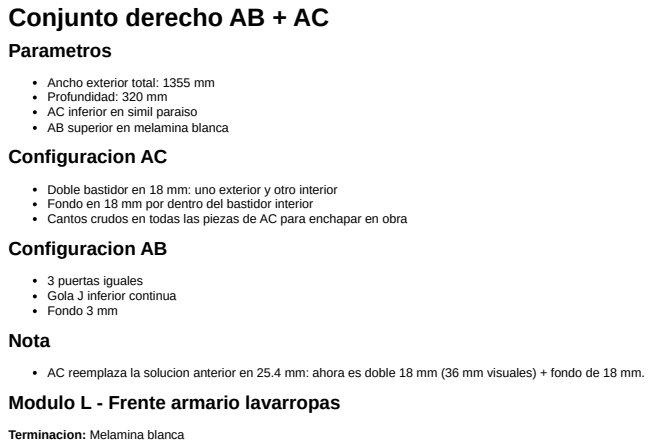
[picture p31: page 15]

Ancho exterior total: 1355 mm
Profundidad: 320 mm
AC inferior en simil paraiso
AB superior en melamina blanca
Configuracion AC

Doble bastidor en 18 mm: uno exterior y otro interior
Fondo en 18 mm por dentro del bastidor interior
Cantos crudos en todas las piezas de AC para enchapar en obra
Configuracion AB

3 puertas iguales
Gola J inferior continua
Fondo 3 mm
Nota

AC reemplaza la solucion anterior en 25.4 mm: ahora es doble 18 mm (36 mm visuales) + fondo de 18 mm.
Modulo L - Frente armario lavarropas

Terminacion: Melamina blanca

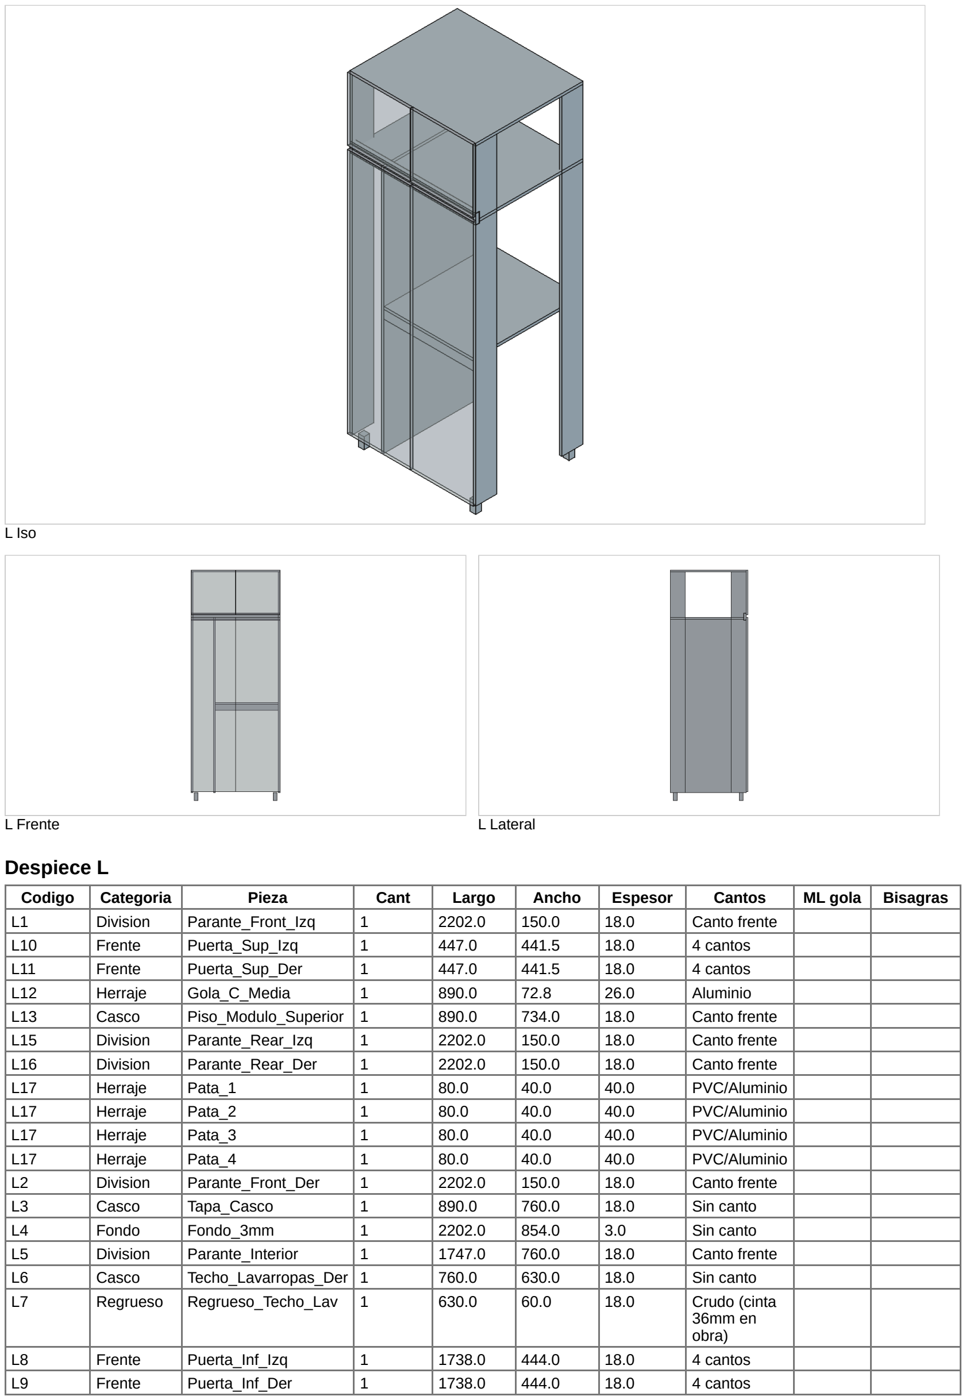
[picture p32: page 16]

L Iso

L Frente | L Lateral

### Despiece L

Codigo | Categoria | Pieza | Cant | Largo | Ancho | Espesor | Cantos | ML gola | Bisagras
L1 | Division | Parante_Front_Izq | 1 | 2202.0 | 150.0 | 18.0 | Canto frente
L10 | Frente | Puerta_Sup_Izq | 1 | 447.0 | 441.5 | 18.0 | 4 cantos
L11 | Frente | Puerta_Sup_Der | 1 | 447.0 | 441.5 | 18.0 | 4 cantos
L12 | Herraje | Gola_C_Media | 1 | 890.0 | 72.8 | 26.0 | Aluminio
L13 | Casco | Piso_Modulo_Superior | 1 | 890.0 | 734.0 | 18.0 | Canto frente
L15 | Division | Parante_Rear_Izq | 1 | 2202.0 | 150.0 | 18.0 | Canto frente
L16 | Division | Parante_Rear_Der | 1 | 2202.0 | 150.0 | 18.0 | Canto frente
L17 | Herraje | Pata_1 | 1 | 80.0 | 40.0 | 40.0 | PVC/Aluminio
L17 | Herraje | Pata_2 | 1 | 80.0 | 40.0 | 40.0 | PVC/Aluminio
L17 | Herraje | Pata_3 | 1 | 80.0 | 40.0 | 40.0 | PVC/Aluminio
L17 | Herraje | Pata_4 | 1 | 80.0 | 40.0 | 40.0 | PVC/Aluminio
L2 | Division | Parante_Front_Der | 1 | 2202.0 | 150.0 | 18.0 | Canto frente
L3 | Casco | Tapa_Casco | 1 | 890.0 | 760.0 | 18.0 | Sin canto
L4 | Fondo | Fondo_3mm | 1 | 2202.0 | 854.0 | 3.0 | Sin canto
L5 | Division | Parante_Interior | 1 | 1747.0 | 760.0 | 18.0 | Canto frente
L6 | Casco | Techo_Lavarropas_Der | 1 | 760.0 | 630.0 | 18.0 | Sin canto
L7 | Regrueso | Regrueso_Techo_Lav | 1 | 630.0 | 60.0 | 18.0 | Crudo (cinta 36mm en obra)
L8 | Frente | Puerta_Inf_Izq | 1 | 1738.0 | 444.0 | 18.0 | 4 cantos
L9 | Frente | Puerta_Inf_Der | 1 | 1738.0 | 444.0 | 18.0 | 4 cantos

### Notas de armado L

1. Armar casco L1-L4 sobre patas/zócalo de 80 mm, verificando escuadra y plomo.
2. Colocar fondo L5 (3 mm) clavado/atornillado para rigidizar el frente completo.
3. Instalar divisor L6 a 260 mm desde el lateral derecho (medida exterior), dejando nicho derecho para escobas.
4. Montar L7 (techo lavarropas) con cara superior a 900 mm y reforzar con L8 por debajo.
5. Montar faja frontal L9 de 50 mm en la cota alineada con puerta superior de H.
6. Verificar calados en piso/tapa:
piso L3: 3 perforaciones de 35 mm para conexiones; tapa L4: perforación 160 mm para ducto.
7. Instalar golas:
L12 (J inferior) alineada con nivel de puerta inferior de H; L15 (J superior) bajo puertas superiores.
8. Colgar frentes:
inferiores L10-L11 (2 hojas iguales);
superiores L13-L14 (2 hojas iguales).
9. Ajustar luces finales (2 mm central) y solape lateral (9 mm) en todas las hojas.

## Modulo BA - Bajo mesada izquierdo

Terminacion: Melamina blanca

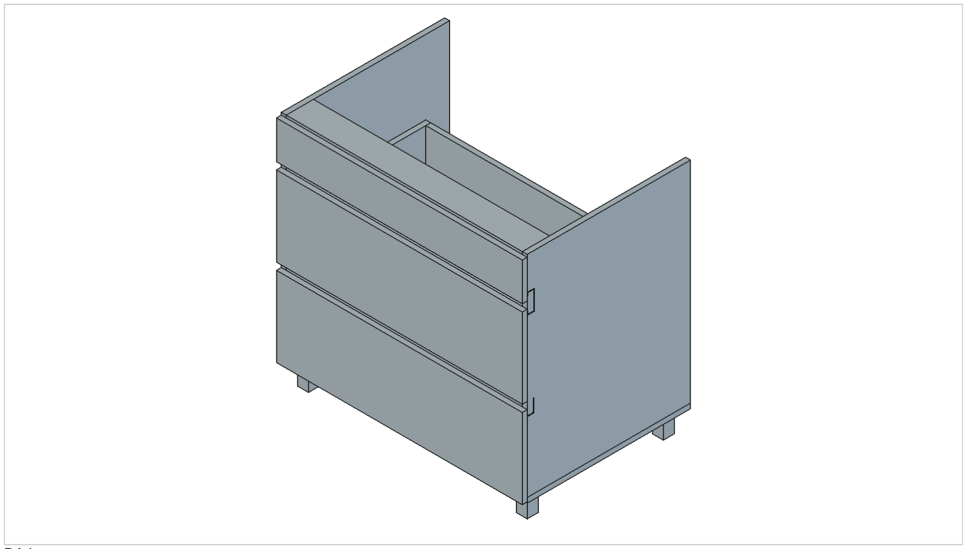
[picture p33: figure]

BA Iso

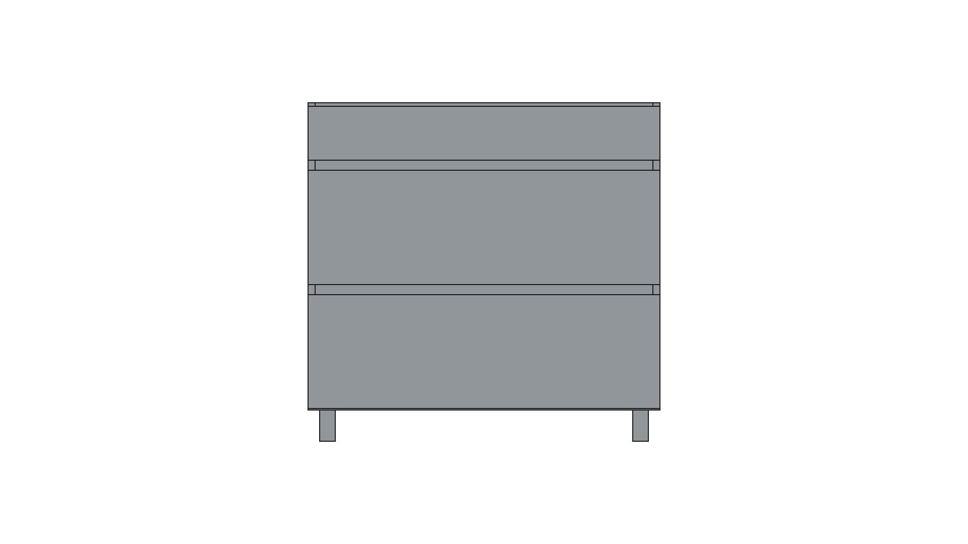
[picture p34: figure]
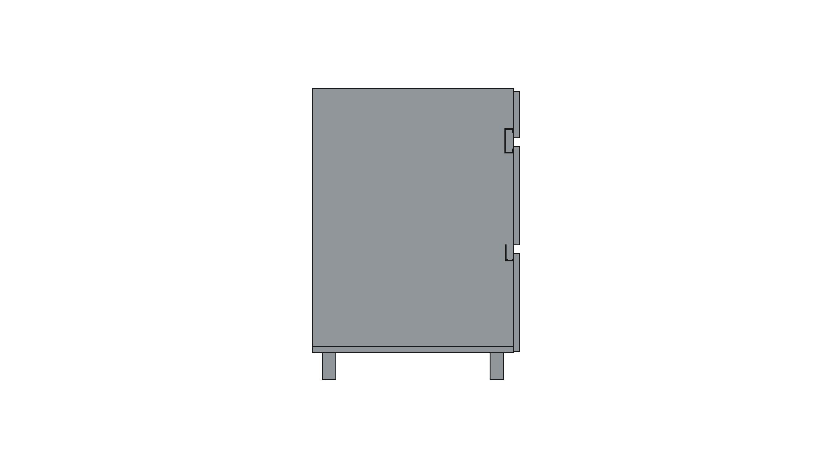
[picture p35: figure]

BA Frente | BA Lateral

### Despiece BA

Codigo | Categoria | Pieza | Cant | Largo | Ancho | Espesor | Cantos | ML gola | Bisagras
BA1 | Casco | Lateral_Izq | 1 | 772.0 | 600.0 | 18.0 | Canto frente
BA10 | Frente | Frente_Mid | 1 | 903.0 | 293.0 | 18.0 | 4 cantos

Codigo | Categoria | Pieza | Cant | Largo | Ancho | Espesor | Cantos | ML gola | Bisagras
BA11 | Frente | Frente_Bot | 1 | 903.0 | 293.0 | 18.0 | 4 cantos
BA12 | Herraje | Gola_C_Superior | 1 | 903.0 | 72.8 | 26.0 | Aluminio
BA13 | Herraje | Gola_J_Media | 1 | 903.0 | 48.0 | 24.4 | Aluminio
BA14 | Fondo | Caja_Mid_Fondo_6mm | 1 | 841.6 | 500.0 | 6.0 | Fondo clavado pasante
BA14 | Cajon | Caja_Mid_Frente_Caja | 1 | 805.6 | 180.0 | 18.0 | 4 cantos
BA14 | Casco | Caja_Mid_Lateral_Der | 1 | 500.0 | 180.0 | 18.0 | Canto frente
BA14 | Casco | Caja_Mid_Lateral_Izq | 1 | 500.0 | 180.0 | 18.0 | Canto frente
BA14 | Cajon | Caja_Mid_Trasera_Caja | 1 | 805.6 | 180.0 | 18.0 | Sin canto
BA15 | Fondo | Caja_Bot_Fondo_6mm | 1 | 841.6 | 500.0 | 6.0 | Fondo clavado pasante
BA15 | Cajon | Caja_Bot_Frente_Caja | 1 | 805.6 | 180.0 | 18.0 | 4 cantos
BA15 | Casco | Caja_Bot_Lateral_Der | 1 | 500.0 | 180.0 | 18.0 | Canto frente
BA15 | Casco | Caja_Bot_Lateral_Izq | 1 | 500.0 | 180.0 | 18.0 | Canto frente
BA15 | Cajon | Caja_Bot_Trasera_Caja | 1 | 805.6 | 180.0 | 18.0 | Sin canto
BA2 | Casco | Lateral_Der | 1 | 772.0 | 600.0 | 18.0 | Canto frente
BA3 | Casco | Piso_Pasante | 1 | 903.0 | 600.0 | 18.0 | Canto frente
BA3L | Herraje | Pata_1 | 1 | 80.0 | 40.0 | 40.0 | PVC/Aluminio
BA3L | Herraje | Pata_2 | 1 | 80.0 | 40.0 | 40.0 | PVC/Aluminio
BA3L | Herraje | Pata_3 | 1 | 80.0 | 40.0 | 40.0 | PVC/Aluminio
BA3L | Herraje | Pata_4 | 1 | 80.0 | 40.0 | 40.0 | PVC/Aluminio
BA4 | Fondo | Fondo_3mm | 1 | 867.0 | 772.0 | 3.0 | Sin canto
BA5 | Casco | Soporte_Superior_Frente | 1 | 867.0 | 100.0 | 18.0 | 4 cantos
BA6 | Casco | Soporte_Superior_Fondo | 1 | 867.0 | 100.0 | 18.0 | Canto frente
BA9 | Frente | Frente_Falso_Sup | 1 | 903.0 | 139.0 | 18.0 | 4 cantos

### Notas de armado BA

# Bajo mesada BA

Ancho: 903 mm
Profundidad: 600 mm
Alto casco: 870 mm
Zocalo: 80 mm
Fila superior: 130 mm
Soportes superiores de mesada: 100 mm de profundidad, por dentro del casco Configuracion: frente falso superior bajo anafe + 2 puertas inferiores + estante interior

## Modulo BB - Bajo mesada derecho

Terminacion: Melamina blanca

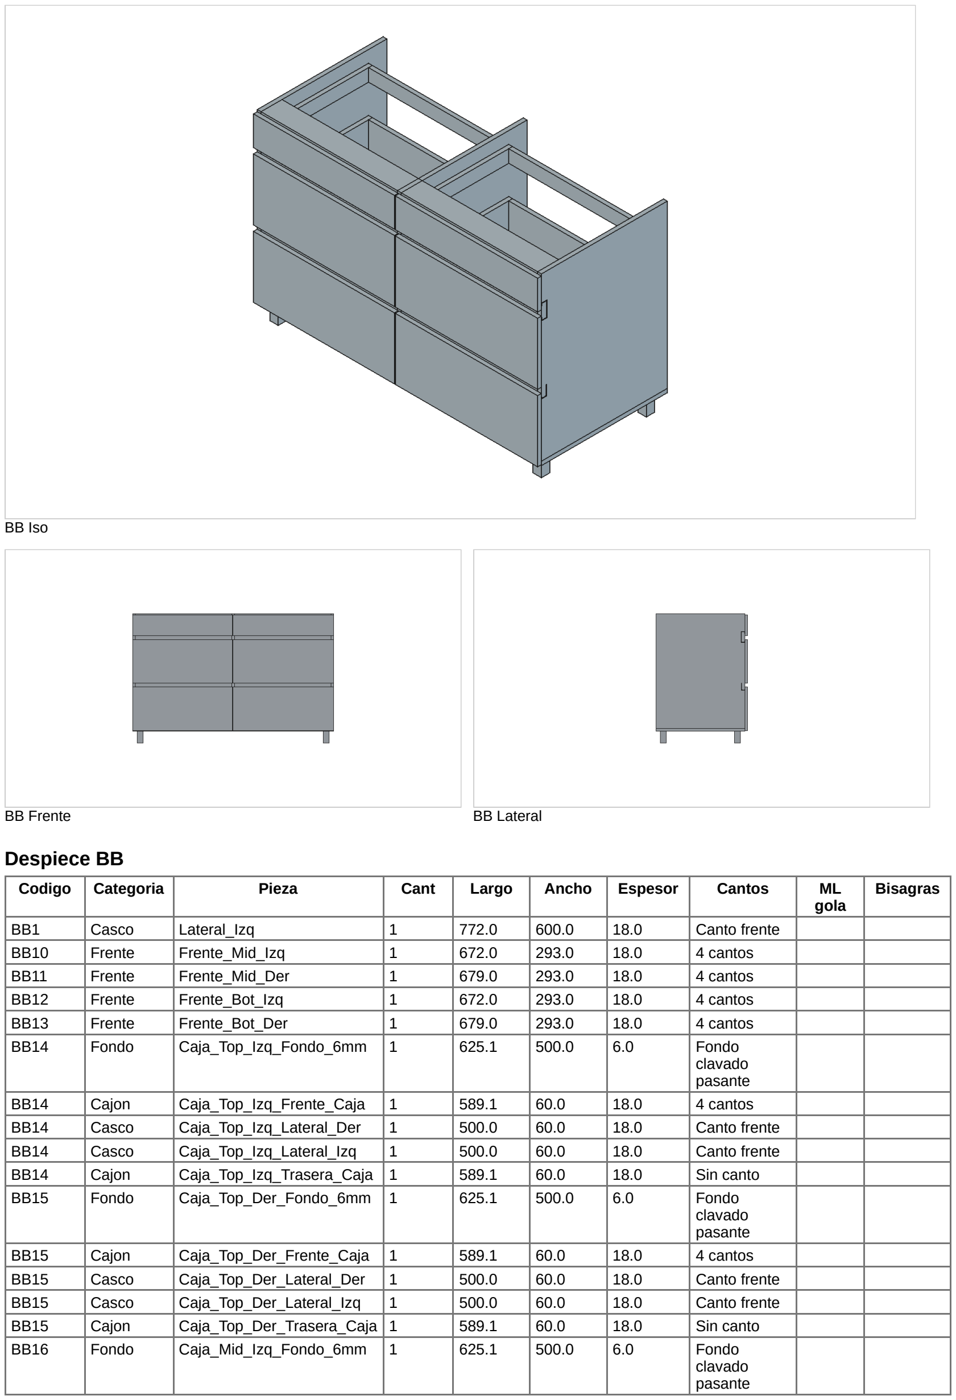
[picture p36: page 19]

BB Iso

BB Frente | BB Lateral

### Despiece BB

Codigo | Categoria | Pieza | Cant | Largo | Ancho | Espesor | Cantos | ML gola | Bisagras
BB1 | Casco | Lateral_Izq | 1 | 772.0 | 600.0 | 18.0 | Canto frente
BB10 | Frente | Frente_Mid_Izq | 1 | 672.0 | 293.0 | 18.0 | 4 cantos
BB11 | Frente | Frente_Mid_Der | 1 | 679.0 | 293.0 | 18.0 | 4 cantos
BB12 | Frente | Frente_Bot_Izq | 1 | 672.0 | 293.0 | 18.0 | 4 cantos
BB13 | Frente | Frente_Bot_Der | 1 | 679.0 | 293.0 | 18.0 | 4 cantos
BB14 | Fondo | Caja_Top_Izq_Fondo_6mm | 1 | 625.1 | 500.0 | 6.0 | Fondo clavado pasante
BB14 | Cajon | Caja_Top_Izq_Frente_Caja | 1 | 589.1 | 60.0 | 18.0 | 4 cantos
BB14 | Casco | Caja_Top_Izq_Lateral_Der | 1 | 500.0 | 60.0 | 18.0 | Canto frente
BB14 | Casco | Caja_Top_Izq_Lateral_Izq | 1 | 500.0 | 60.0 | 18.0 | Canto frente
BB14 | Cajon | Caja_Top_Izq_Trasera_Caja | 1 | 589.1 | 60.0 | 18.0 | Sin canto
BB15 | Fondo | Caja_Top_Der_Fondo_6mm | 1 | 625.1 | 500.0 | 6.0 | Fondo clavado pasante
BB15 | Cajon | Caja_Top_Der_Frente_Caja | 1 | 589.1 | 60.0 | 18.0 | 4 cantos
BB15 | Casco | Caja_Top_Der_Lateral_Der | 1 | 500.0 | 60.0 | 18.0 | Canto frente
BB15 | Casco | Caja_Top_Der_Lateral_Izq | 1 | 500.0 | 60.0 | 18.0 | Canto frente
BB15 | Cajon | Caja_Top_Der_Trasera_Caja | 1 | 589.1 | 60.0 | 18.0 | Sin canto
BB16 | Fondo | Caja_Mid_Izq_Fondo_6mm | 1 | 625.1 | 500.0 | 6.0 | Fondo clavado pasante

Codigo | Categoria | Pieza | Cant | Largo | Ancho | Espesor | Cantos | ML gola | Bisagras
BB16 | Cajon | Caja_Mid_Izq_Frente_Caja | 1 | 589.1 | 180.0 | 18.0 | 4 cantos
BB16 | Casco | Caja_Mid_Izq_Lateral_Der | 1 | 500.0 | 180.0 | 18.0 | Canto frente
BB16 | Casco | Caja_Mid_Izq_Lateral_Izq | 1 | 500.0 | 180.0 | 18.0 | Canto frente
BB16 | Cajon | Caja_Mid_Izq_Trasera_Caja | 1 | 589.1 | 180.0 | 18.0 | Sin canto
BB17 | Fondo | Caja_Mid_Der_Fondo_6mm | 1 | 625.1 | 500.0 | 6.0 | Fondo clavado pasante
BB17 | Cajon | Caja_Mid_Der_Frente_Caja | 1 | 589.1 | 180.0 | 18.0 | 4 cantos
BB17 | Casco | Caja_Mid_Der_Lateral_Der | 1 | 500.0 | 180.0 | 18.0 | Canto frente
BB17 | Casco | Caja_Mid_Der_Lateral_Izq | 1 | 500.0 | 180.0 | 18.0 | Canto frente
BB17 | Cajon | Caja_Mid_Der_Trasera_Caja | 1 | 589.1 | 180.0 | 18.0 | Sin canto
BB18 | Fondo | Caja_Bot_Izq_Fondo_6mm | 1 | 625.1 | 500.0 | 6.0 | Fondo clavado pasante
BB18 | Cajon | Caja_Bot_Izq_Frente_Caja | 1 | 589.1 | 180.0 | 18.0 | 4 cantos
BB18 | Casco | Caja_Bot_Izq_Lateral_Der | 1 | 500.0 | 180.0 | 18.0 | Canto frente
BB18 | Casco | Caja_Bot_Izq_Lateral_Izq | 1 | 500.0 | 180.0 | 18.0 | Canto frente
BB18 | Cajon | Caja_Bot_Izq_Trasera_Caja | 1 | 589.1 | 180.0 | 18.0 | Sin canto
BB19 | Fondo | Caja_Bot_Der_Fondo_6mm | 1 | 625.1 | 500.0 | 6.0 | Fondo clavado pasante
BB19 | Cajon | Caja_Bot_Der_Frente_Caja | 1 | 589.1 | 180.0 | 18.0 | 4 cantos
BB19 | Casco | Caja_Bot_Der_Lateral_Der | 1 | 500.0 | 180.0 | 18.0 | Canto frente
BB19 | Casco | Caja_Bot_Der_Lateral_Izq | 1 | 500.0 | 180.0 | 18.0 | Canto frente
BB19 | Cajon | Caja_Bot_Der_Trasera_Caja | 1 | 589.1 | 180.0 | 18.0 | Sin canto
BB2 | Casco | Lateral_Der | 1 | 772.0 | 600.0 | 18.0 | Canto frente
BB20 | Herraje | Gola_C_Superior | 1 | 1355.0 | 72.8 | 26.0 | Aluminio
BB21 | Herraje | Gola_J_Media | 1 | 1355.0 | 48.0 | 24.4 | Aluminio
BB3 | Casco | Piso_Pasante | 1 | 1355.0 | 600.0 | 18.0 | Canto frente
BB3L | Herraje | Pata_1 | 1 | 80.0 | 40.0 | 40.0 | PVC/Aluminio
BB3L | Herraje | Pata_2 | 1 | 80.0 | 40.0 | 40.0 | PVC/Aluminio
BB3L | Herraje | Pata_3 | 1 | 80.0 | 40.0 | 40.0 | PVC/Aluminio
BB3L | Herraje | Pata_4 | 1 | 80.0 | 40.0 | 40.0 | PVC/Aluminio
BB4 | Fondo | Fondo_3mm | 1 | 1319.0 | 772.0 | 3.0 | Sin canto
BB5 | Casco | Soporte_Superior_Frente | 1 | 1319.0 | 100.0 | 18.0 | 4 cantos
BB6 | Casco | Soporte_Superior_Fondo | 1 | 1319.0 | 100.0 | 18.0 | Canto frente
BB7 | Division | Divisor_Central | 1 | 772.0 | 600.0 | 18.0 | Canto frente
BB8 | Frente | Frente_Top_Izq | 1 | 672.0 | 139.0 | 18.0 | 4 cantos
BB9 | Frente | Frente_Top_Der | 1 | 679.0 | 139.0 | 18.0 | 4 cantos

### Notas de armado BB

# Bajo mesada BB

Ancho: 1355 mm
Profundidad: 600 mm
Alto casco: 870 mm
Zocalo: 80 mm
Fila superior: 130 mm
Soportes superiores de mesada: 100 mm de profundidad, por dentro del casco Configuracion: 6 cajones (2 columnas x 3 filas)

## Modulo F - Mueble heladera + modular

Terminacion: Paraiso + blanco

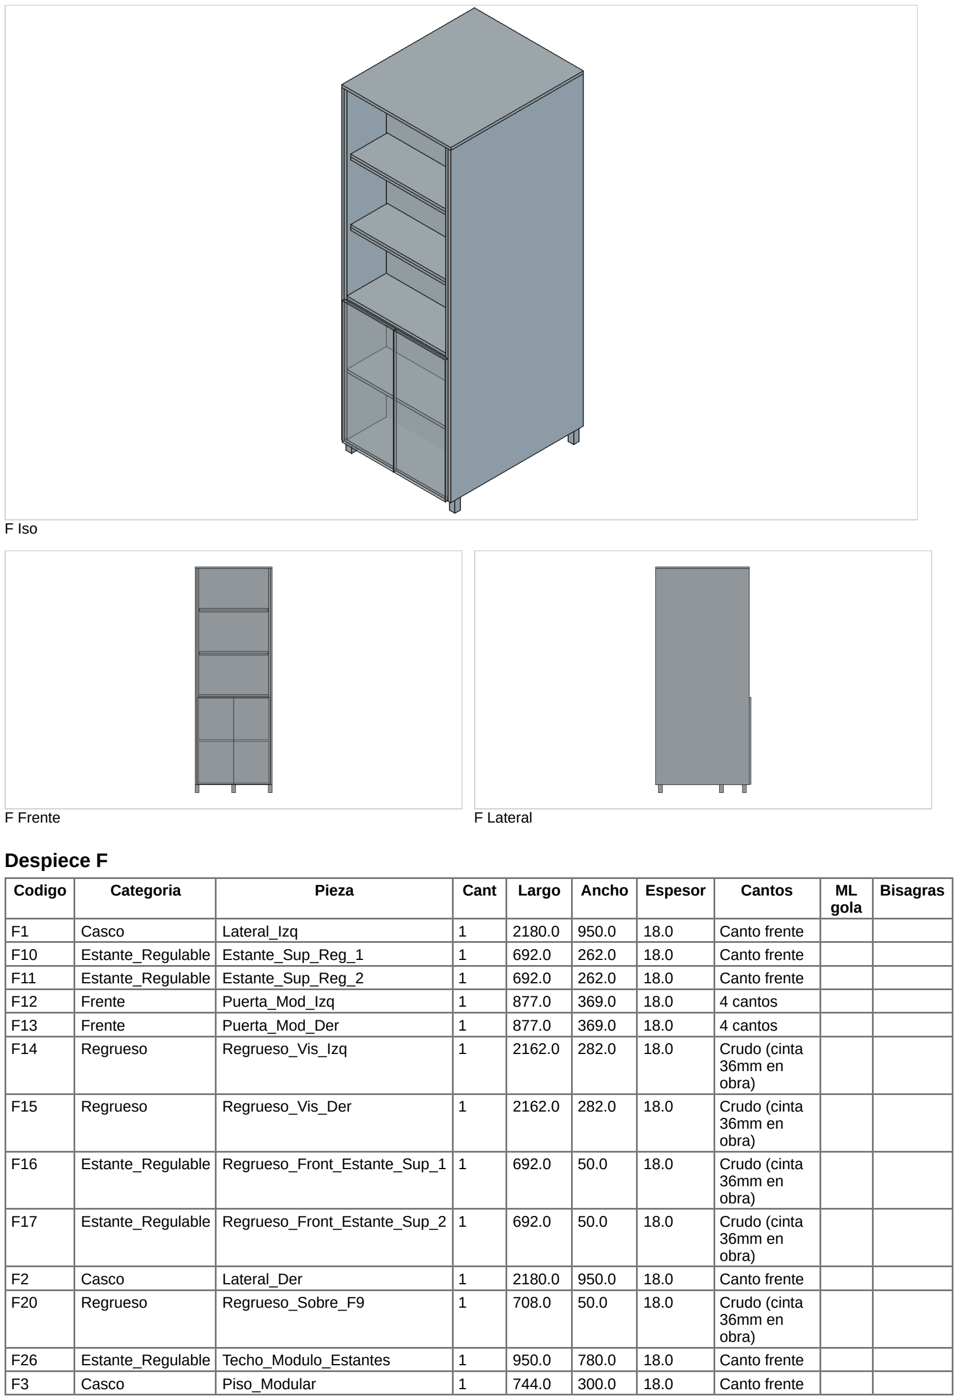
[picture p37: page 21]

F Iso

F Frente | F Lateral

### Despiece F

Codigo | Categoria | Pieza | Cant | Largo | Ancho | Espesor | Cantos | ML gola | Bisagras
F1 | Casco | Lateral_Izq | 1 | 2180.0 | 950.0 | 18.0 | Canto frente
F10 | Estante_Regulable | Estante_Sup_Reg_1 | 1 | 692.0 | 262.0 | 18.0 | Canto frente
F11 | Estante_Regulable | Estante_Sup_Reg_2 | 1 | 692.0 | 262.0 | 18.0 | Canto frente
F12 | Frente | Puerta_Mod_Izq | 1 | 877.0 | 369.0 | 18.0 | 4 cantos
F13 | Frente | Puerta_Mod_Der | 1 | 877.0 | 369.0 | 18.0 | 4 cantos
F14 | Regrueso | Regrueso_Vis_Izq | 1 | 2162.0 | 282.0 | 18.0 | Crudo (cinta 36mm en obra)
F15 | Regrueso | Regrueso_Vis_Der | 1 | 2162.0 | 282.0 | 18.0 | Crudo (cinta 36mm en obra)
F16 | Estante_Regulable | Regrueso_Front_Estante_Sup_1 | 1 | 692.0 | 50.0 | 18.0 | Crudo (cinta 36mm en obra)
F17 | Estante_Regulable | Regrueso_Front_Estante_Sup_2 | 1 | 692.0 | 50.0 | 18.0 | Crudo (cinta 36mm en obra)
F2 | Casco | Lateral_Der | 1 | 2180.0 | 950.0 | 18.0 | Canto frente
F20 | Regrueso | Regrueso_Sobre_F9 | 1 | 708.0 | 50.0 | 18.0 | Crudo (cinta 36mm en obra)
F26 | Estante_Regulable | Techo_Modulo_Estantes | 1 | 950.0 | 780.0 | 18.0 | Canto frente
F3 | Casco | Piso_Modular | 1 | 744.0 | 300.0 | 18.0 | Canto frente

Codigo | Categoria | Pieza | Cant | Largo | Ancho | Espesor | Cantos | ML gola | Bisagras
F3L | Herraje | Pata_1 | 1 | 80.0 | 40.0 | 40.0 | PVC/Aluminio
F3L | Herraje | Pata_2 | 1 | 80.0 | 40.0 | 40.0 | PVC/Aluminio
F3L | Herraje | Pata_3 | 1 | 80.0 | 40.0 | 40.0 | PVC/Aluminio
F3L | Herraje | Pata_4 | 1 | 80.0 | 40.0 | 40.0 | PVC/Aluminio
F3L | Herraje | Pata_5 | 1 | 80.0 | 40.0 | 40.0 | PVC/Aluminio
F5 | Division | Panel_Divisor_Prof | 1 | 2180.0 | 744.0 | 18.0 | Canto frente
F6 | Casco | Techo_Heladera_1800 | 1 | 740.0 | 650.0 | 18.0 | Sin canto
F7 | Estante_Regulable | Estante_Bajo_Reg | 1 | 708.0 | 282.0 | 18.0 | Canto frente
F9 | Estante_Regulable | Estante_Fijo_Interior | 1 | 708.0 | 282.0 | 18.0 | Canto frente

### Notas de armado F

# Mueble F (heladera + modular)

Alto total: 2400 mm
Ancho cuerpo: 780 mm
Profundidad total: 950 mm
Modular posterior: 300 mm de profundidad
Cajon superior corrido integrado, volado hacia la derecha

## Nota constructiva

Los pares de cantos dobles visibles (F1/F14 y F2/F15) se dejan crudos en taller. Enchapar en obra con cinta continua de 36 mm para evitar lectura de junta entre placas.

## Modulo I - Bajo mesada isla

Terminacion: Melamina blanca

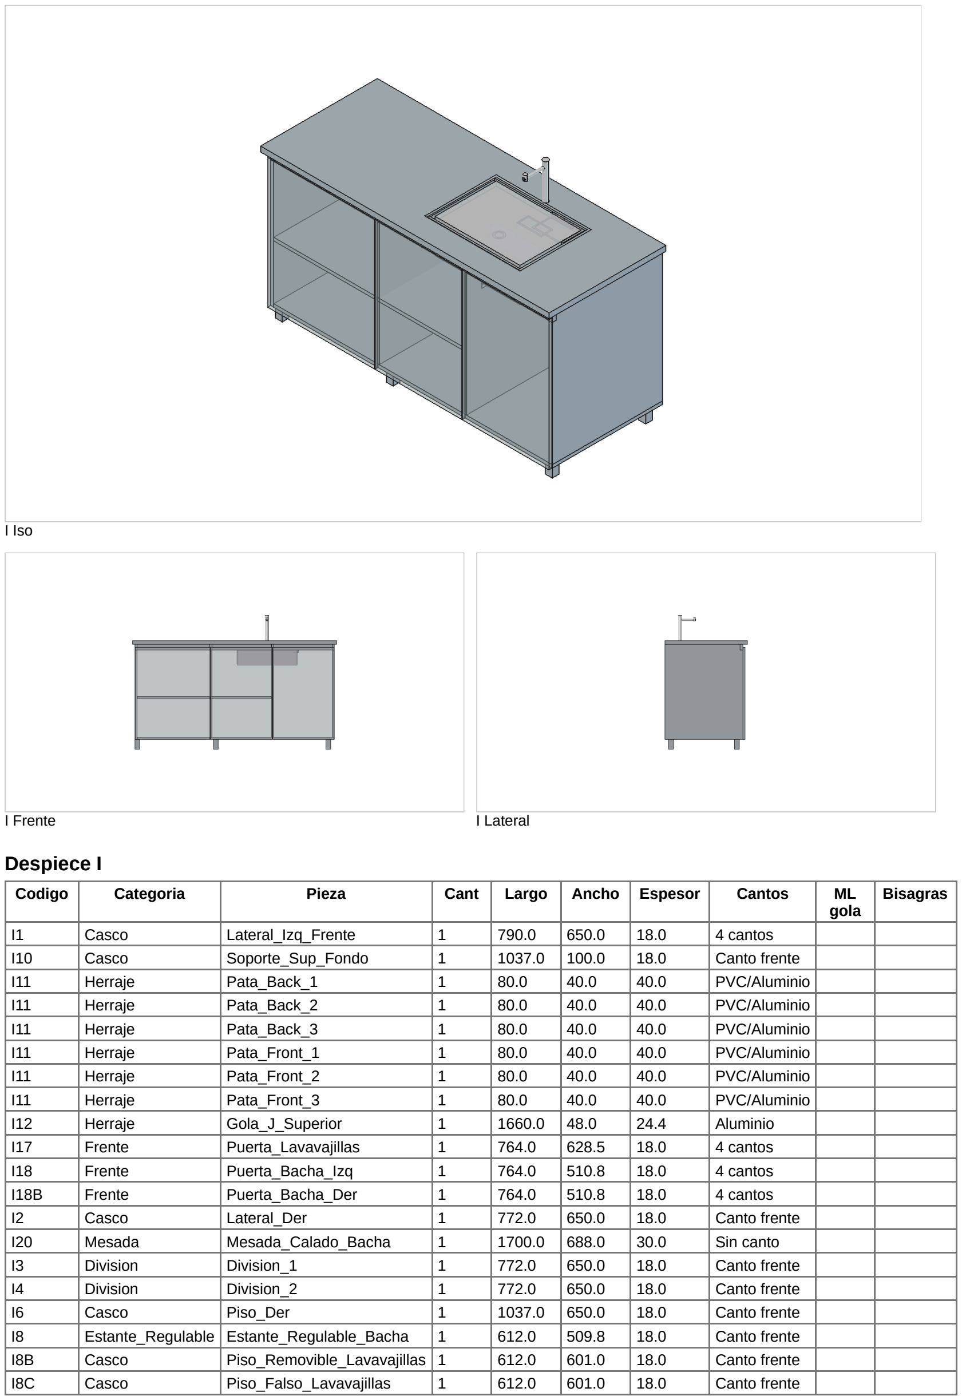
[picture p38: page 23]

I Iso

I Frente | I Lateral

### Despiece I

Codigo | Categoria | Pieza | Cant | Largo | Ancho | Espesor | Cantos | ML gola | Bisagras
I1 | Casco | Lateral_Izq_Frente | 1 | 790.0 | 650.0 | 18.0 | 4 cantos
I10 | Casco | Soporte_Sup_Fondo | 1 | 1037.0 | 100.0 | 18.0 | Canto frente
I11 | Herraje | Pata_Back_1 | 1 | 80.0 | 40.0 | 40.0 | PVC/Aluminio
I11 | Herraje | Pata_Back_2 | 1 | 80.0 | 40.0 | 40.0 | PVC/Aluminio
I11 | Herraje | Pata_Back_3 | 1 | 80.0 | 40.0 | 40.0 | PVC/Aluminio
I11 | Herraje | Pata_Front_1 | 1 | 80.0 | 40.0 | 40.0 | PVC/Aluminio
I11 | Herraje | Pata_Front_2 | 1 | 80.0 | 40.0 | 40.0 | PVC/Aluminio
I11 | Herraje | Pata_Front_3 | 1 | 80.0 | 40.0 | 40.0 | PVC/Aluminio
I12 | Herraje | Gola_J_Superior | 1 | 1660.0 | 48.0 | 24.4 | Aluminio
I17 | Frente | Puerta_Lavavajillas | 1 | 764.0 | 628.5 | 18.0 | 4 cantos
I18 | Frente | Puerta_Bacha_Izq | 1 | 764.0 | 510.8 | 18.0 | 4 cantos
I18B | Frente | Puerta_Bacha_Der | 1 | 764.0 | 510.8 | 18.0 | 4 cantos
I2 | Casco | Lateral_Der | 1 | 772.0 | 650.0 | 18.0 | Canto frente
I20 | Mesada | Mesada_Calado_Bacha | 1 | 1700.0 | 688.0 | 30.0 | Sin canto
I3 | Division | Division_1 | 1 | 772.0 | 650.0 | 18.0 | Canto frente
I4 | Division | Division_2 | 1 | 772.0 | 650.0 | 18.0 | Canto frente
I6 | Casco | Piso_Der | 1 | 1037.0 | 650.0 | 18.0 | Canto frente
I8 | Estante_Regulable | Estante_Regulable_Bacha | 1 | 612.0 | 509.8 | 18.0 | Canto frente
I8B | Casco | Piso_Removible_Lavavajillas | 1 | 612.0 | 601.0 | 18.0 | Canto frente
I8C | Casco | Piso_Falso_Lavavajillas | 1 | 612.0 | 601.0 | 18.0 | Canto frente

Codigo | Categoria | Pieza | Cant | Largo | Ancho | Espesor | Cantos | ML gola | Bisagras
I9 | Casco | Soporte_Sup_Frente | 1 | 1624.0 | 100.0 | 18.0 | 4 cantos

### Notas de armado I

# Bajo mesada isla I

## Parametros

Ancho: 1540 mm
Profundidad casco/frentes: 650 mm Mesada: 688 mm de profundidad total Alto casco: 870 mm
Zocalo/patas: 80 mm
Nicho lavavajillas libre: 455 mm
Nicho izquierdo: 290 mm de ancho x 289 mm de profundidad

## Configuracion

Columna izquierda: 3 cajones iguales
Centro: frente lavavajillas
Derecha: puerta
Nicho izquierdo posterior abierto con un estante regulable
Faja superior de nicho en el eje Y y otra faja frontal bajo estante para engrosar visualmente

## Herrajes

Gola J superior continua
Gola C en columna izquierda para cajones medio e inferior Correderas telescopicas para 3 cajones
Patas 80 mm

## Nota

El nicho izquierdo ya no lleva cava integrada.
La piedra sobresale respecto del frente y la profundidad total terminada es 688 mm.

## Modulo R - Rinconera

Terminacion: Melamina blanca

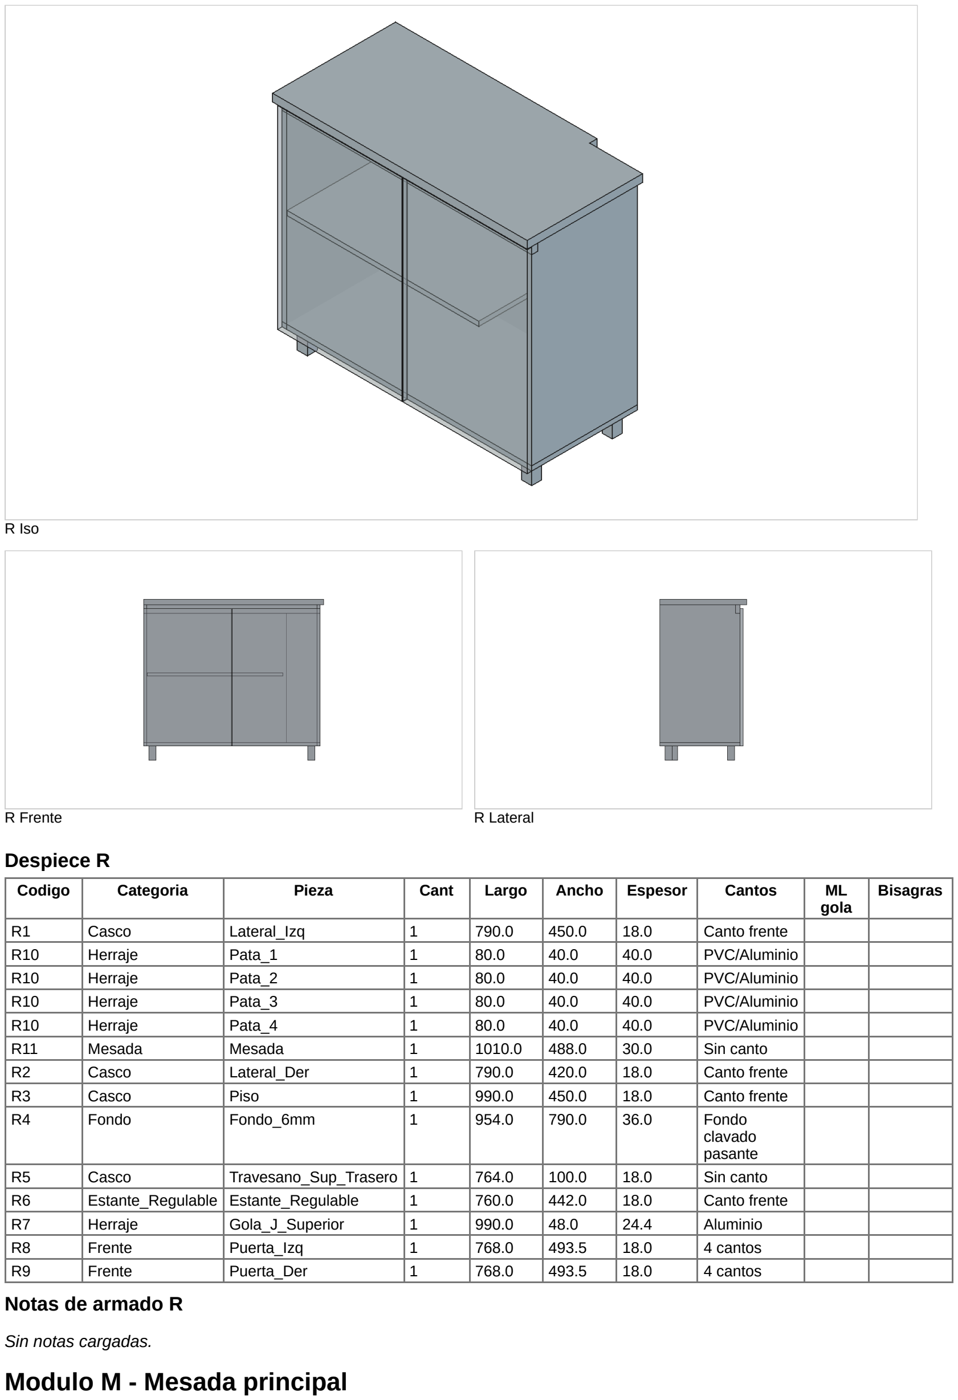
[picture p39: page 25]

R Iso

R Frente | R Lateral

### Despiece R

Codigo | Categoria | Pieza | Cant | Largo | Ancho | Espesor | Cantos | ML gola | Bisagras
R1 | Casco | Lateral_Izq | 1 | 790.0 | 450.0 | 18.0 | Canto frente
R10 | Herraje | Pata_1 | 1 | 80.0 | 40.0 | 40.0 | PVC/Aluminio
R10 | Herraje | Pata_2 | 1 | 80.0 | 40.0 | 40.0 | PVC/Aluminio
R10 | Herraje | Pata_3 | 1 | 80.0 | 40.0 | 40.0 | PVC/Aluminio
R10 | Herraje | Pata_4 | 1 | 80.0 | 40.0 | 40.0 | PVC/Aluminio
R11 | Mesada | Mesada | 1 | 1010.0 | 488.0 | 30.0 | Sin canto
R2 | Casco | Lateral_Der | 1 | 790.0 | 420.0 | 18.0 | Canto frente
R3 | Casco | Piso | 1 | 990.0 | 450.0 | 18.0 | Canto frente
R4 | Fondo | Fondo_6mm | 1 | 954.0 | 790.0 | 36.0 | Fondo clavado pasante
R5 | Casco | Travesano_Sup_Trasero | 1 | 764.0 | 100.0 | 18.0 | Sin canto
R6 | Estante_Regulable | Estante_Regulable | 1 | 760.0 | 442.0 | 18.0 | Canto frente
R7 | Herraje | Gola_J_Superior | 1 | 990.0 | 48.0 | 24.4 | Aluminio
R8 | Frente | Puerta_Izq | 1 | 768.0 | 493.5 | 18.0 | 4 cantos
R9 | Frente | Puerta_Der | 1 | 768.0 | 493.5 | 18.0 | 4 cantos

### Notas de armado R

Sin notas cargadas.

## Modulo M - Mesada principal

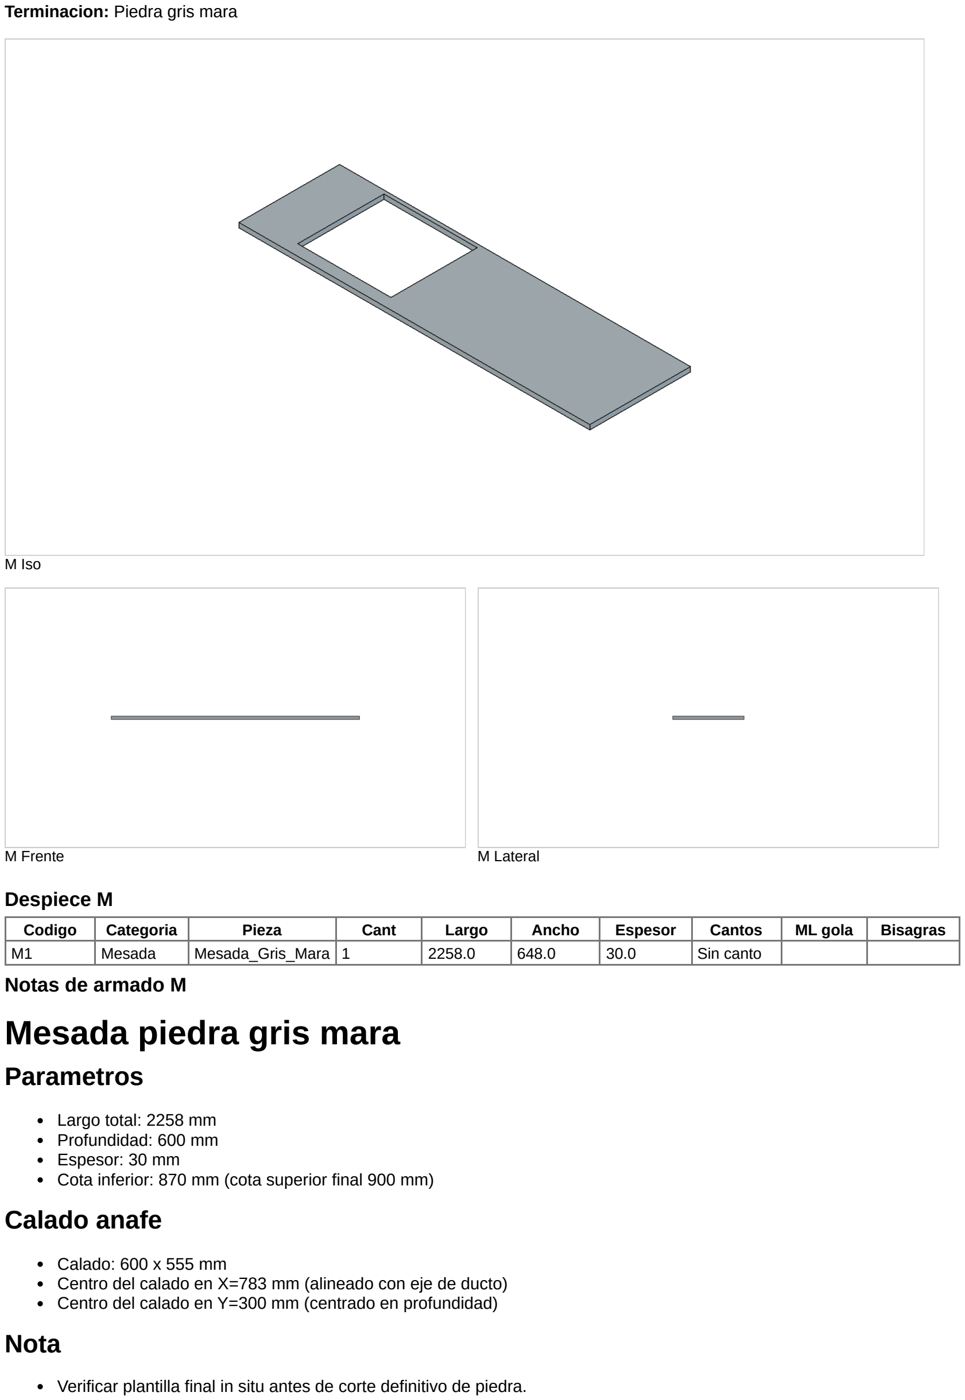
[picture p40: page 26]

Terminacion: Piedra gris mara

M Iso

M Frente | M Lateral

### Despiece M

Codigo | Categoria | Pieza | Cant | Largo | Ancho | Espesor | Cantos | ML gola | Bisagras
M1 | Mesada | Mesada_Gris_Mara | 1 | 2258.0 | 648.0 | 30.0 | Sin canto

### Notas de armado M

# Mesada piedra gris mara

## Parametros

Largo total: 2258 mm
Profundidad: 600 mm
Espesor: 30 mm
Cota inferior: 870 mm (cota superior final 900 mm)

## Calado anafe

Calado: 600 x 555 mm
Centro del calado en X=783 mm (alineado con eje de ducto) Centro del calado en Y=300 mm (centrado en profundidad)

## Nota

Verificar plantilla final in situ antes de corte definitivo de piedra.

## 4. Plan de corte

Grupo | Piezas | Placas | Placa util (mm) | Kerf | Margen | Aprovechamiento | Descarte
blanco_18mm | 151 | 10 | 2800 x 1810 | 3 | 10 | 84.13% | 15.87%
fondo_3mm | 6 | 2 | 2800 x 1810 | 3 | 10 | 60.98% | 39.02%
fondo_6mm | 12 | 1 | 2800 x 1810 | 3 | 10 | 73.63% | 26.37%
paraiso_18mm | 9 | 1 | 2800 x 1810 | 3 | 10 | 47.74% | 52.26%

### Layouts por grupo

Sin SVGs.

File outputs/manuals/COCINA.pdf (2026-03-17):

# Manual Constructivo Integral - Cocina

## 1. Ensambles generales

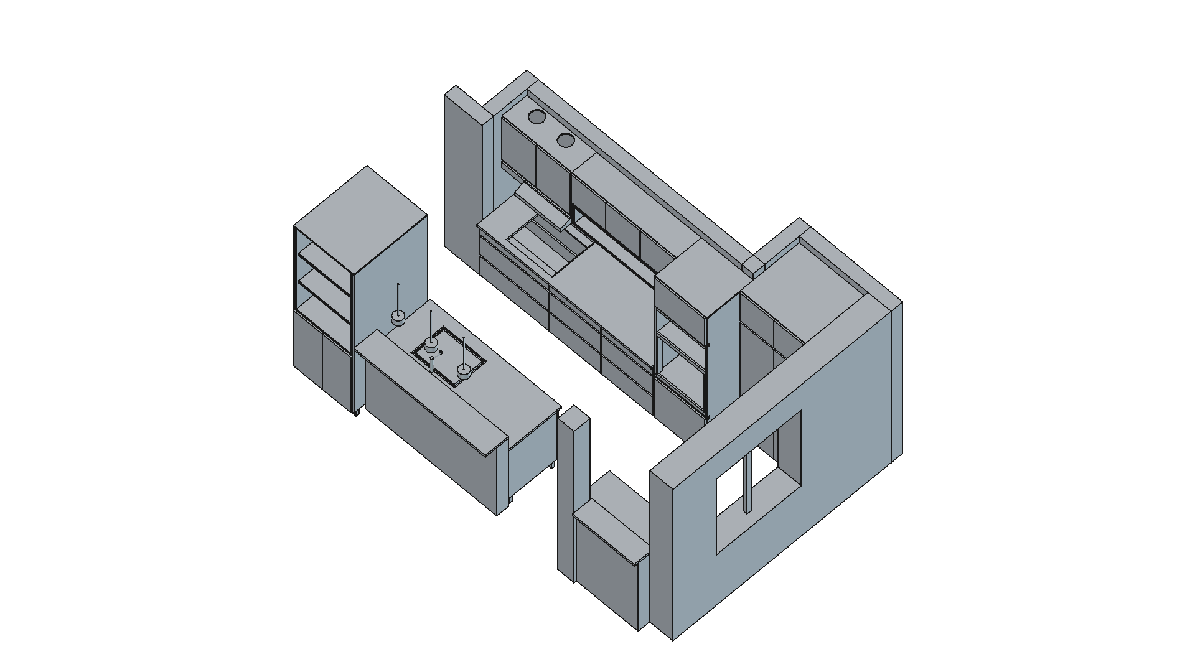
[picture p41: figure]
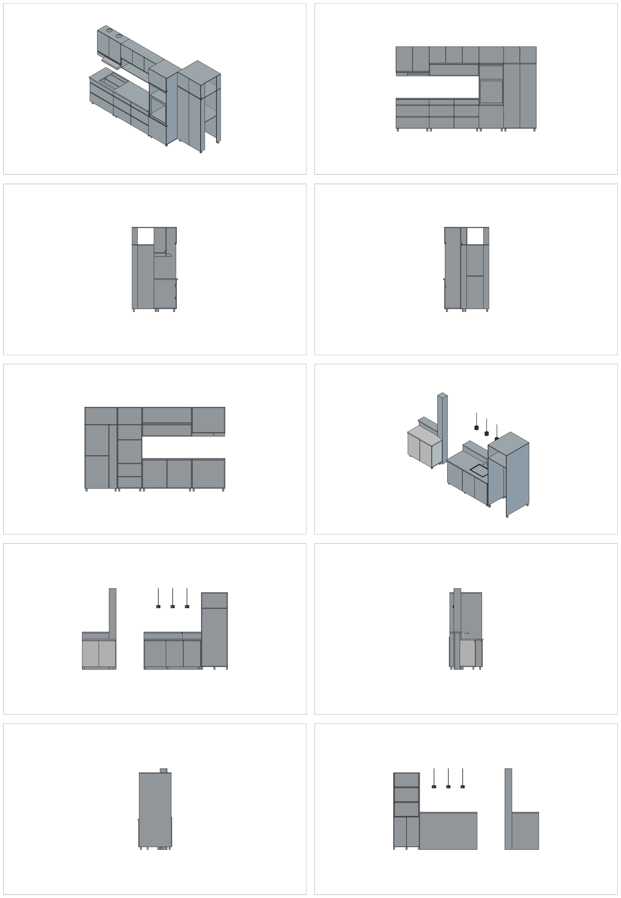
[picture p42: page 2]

## 2. Modulos Modulo H - Columna horno + micro

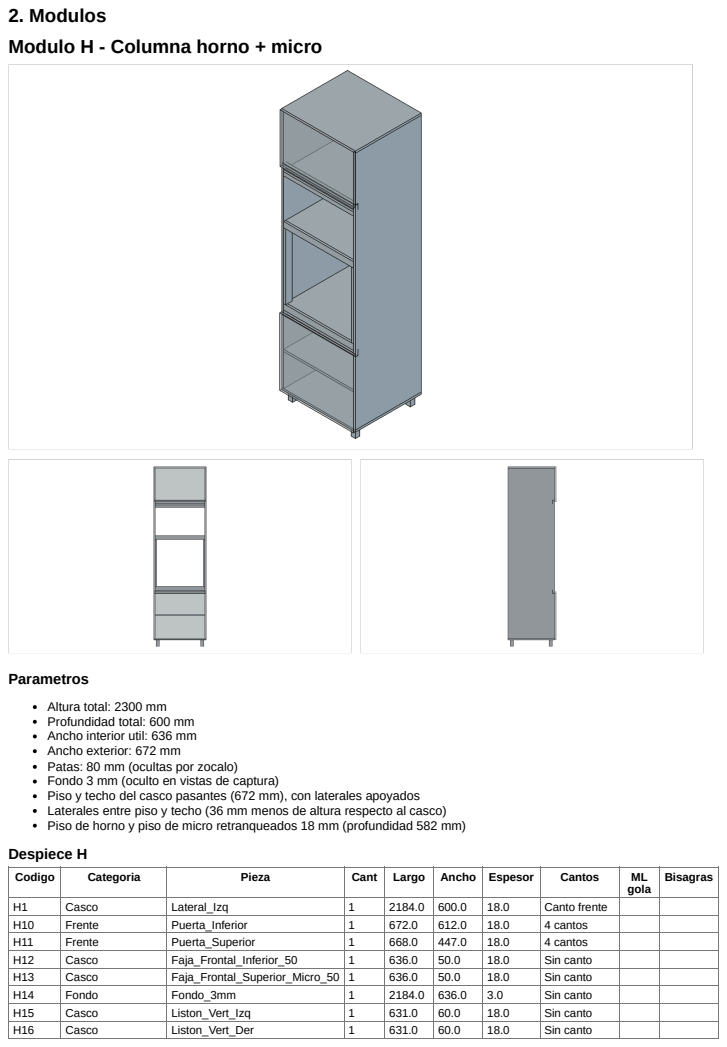
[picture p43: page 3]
Parametros

Altura total: 2300 mm
Profundidad total: 600 mm
Ancho interior util: 636 mm
Ancho exterior: 672 mm
Patas: 80 mm (ocultas por zocalo)
Fondo 3 mm (oculto en vistas de captura)
Piso y techo del casco pasantes (672 mm), con laterales apoyados
Laterales entre piso y techo (36 mm menos de altura respecto al casco)
Piso de horno y piso de micro retranqueados 18 mm (profundidad 582 mm)
Despiece H

Codigo | Categoria | Pieza | Cant | Largo | Ancho | Espesor | Cantos | ML gola | Bisagras

H1 | Casco | Lateral_Izq | 1 | 2184.0 | 600.0 | 18.0 | Canto frente
H10 | Frente | Puerta_Inferior | 1 | 672.0 | 612.0 | 18.0 | 4 cantos
H11 | Frente | Puerta_Superior | 1 | 668.0 | 447.0 | 18.0 | 4 cantos
H12 | Casco | Faja_Frontal_Inferior_50 | 1 | 636.0 | 50.0 | 18.0 | Sin canto
H13 | Casco | Faja_Frontal_Superior_Micro_50 | 1 | 636.0 | 50.0 | 18.0 | Sin canto
H14 | Fondo | Fondo_3mm | 1 | 2184.0 | 636.0 | 3.0 | Sin canto
H15 | Casco | Liston_Vert_Izq | 1 | 631.0 | 60.0 | 18.0 | Sin canto
H16 | Casco | Liston_Vert_Der | 1 | 631.0 | 60.0 | 18.0 | Sin canto

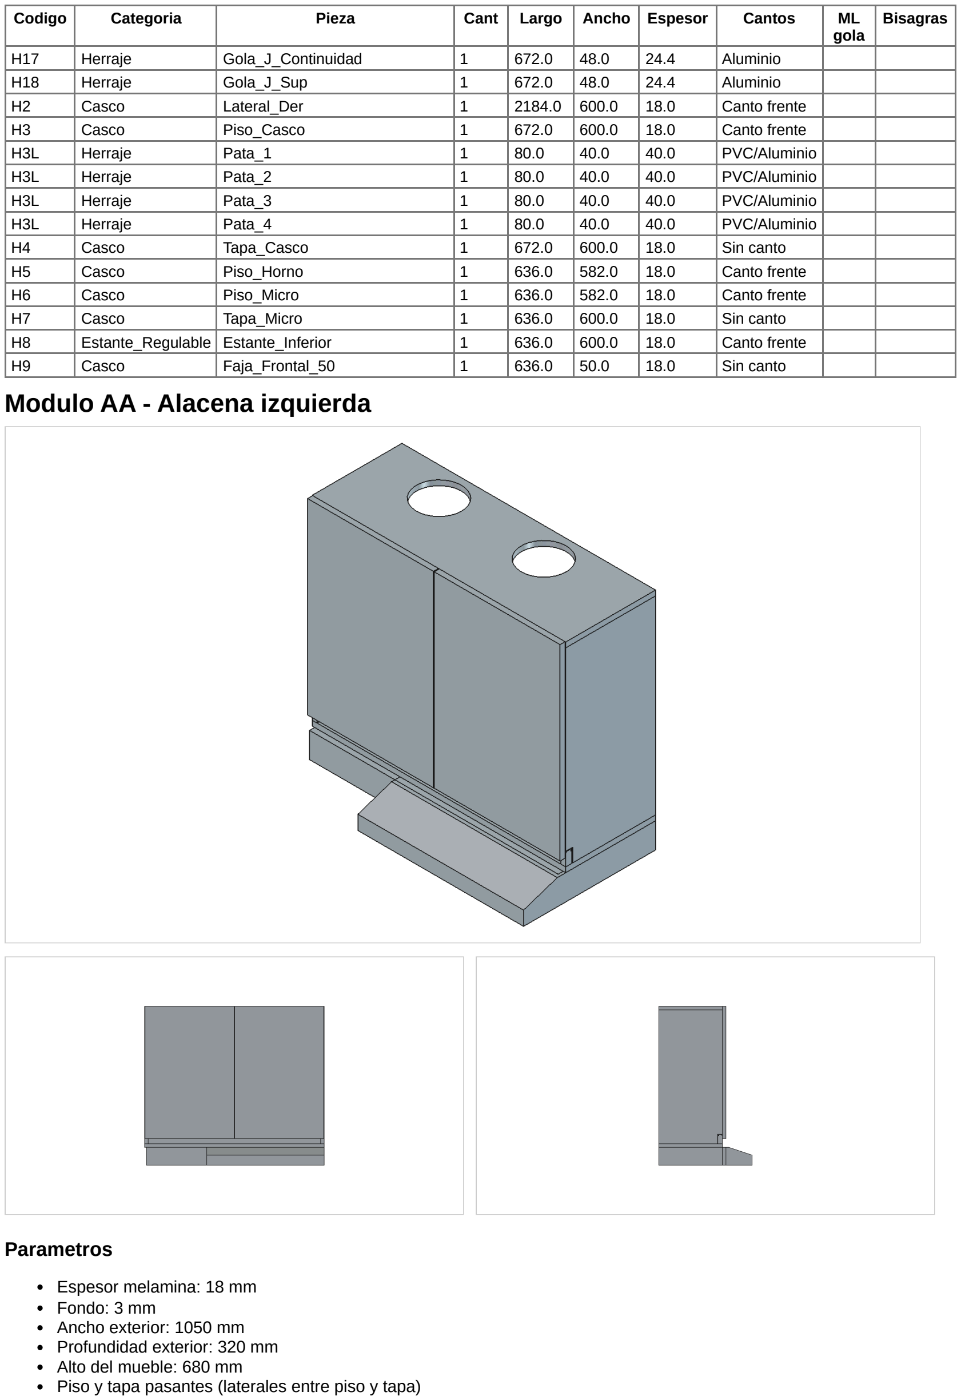
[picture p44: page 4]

Codigo | Categoria | Pieza | Cant | Largo | Ancho | Espesor | Cantos | ML gola | Bisagras
H17 | Herraje | Gola_J_Continuidad | 1 | 672.0 | 48.0 | 24.4 | Aluminio
H18 | Herraje | Gola_J_Sup | 1 | 672.0 | 48.0 | 24.4 | Aluminio
H2 | Casco | Lateral_Der | 1 | 2184.0 | 600.0 | 18.0 | Canto frente
H3 | Casco | Piso_Casco | 1 | 672.0 | 600.0 | 18.0 | Canto frente
H3L | Herraje | Pata_1 | 1 | 80.0 | 40.0 | 40.0 | PVC/Aluminio
H3L | Herraje | Pata_2 | 1 | 80.0 | 40.0 | 40.0 | PVC/Aluminio
H3L | Herraje | Pata_3 | 1 | 80.0 | 40.0 | 40.0 | PVC/Aluminio
H3L | Herraje | Pata_4 | 1 | 80.0 | 40.0 | 40.0 | PVC/Aluminio
H4 | Casco | Tapa_Casco | 1 | 672.0 | 600.0 | 18.0 | Sin canto
H5 | Casco | Piso_Horno | 1 | 636.0 | 582.0 | 18.0 | Canto frente
H6 | Casco | Piso_Micro | 1 | 636.0 | 582.0 | 18.0 | Canto frente
H7 | Casco | Tapa_Micro | 1 | 636.0 | 600.0 | 18.0 | Sin canto
H8 | Estante_Regulable | Estante_Inferior | 1 | 636.0 | 600.0 | 18.0 | Canto frente
H9 | Casco | Faja_Frontal_50 | 1 | 636.0 | 50.0 | 18.0 | Sin canto

## Modulo AA - Alacena izquierda

### Parametros

Espesor melamina: 18 mm
Fondo: 3 mm
Ancho exterior: 1050 mm
Profundidad exterior: 320 mm
Alto del mueble: 680 mm
Piso y tapa pasantes (laterales entre piso y tapa)

### Despiece AA

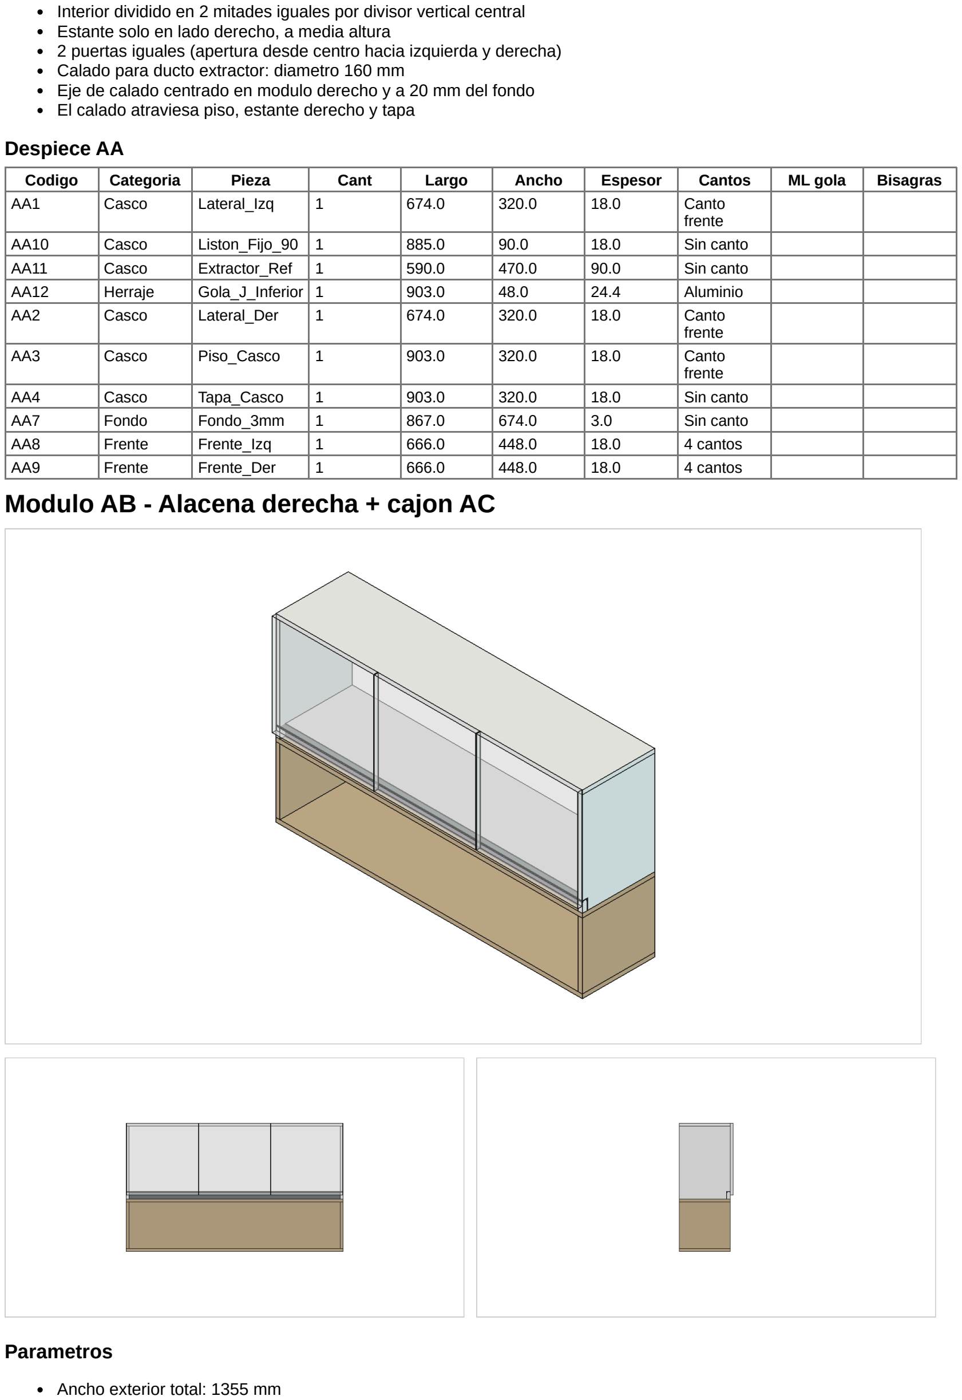
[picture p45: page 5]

Interior dividido en 2 mitades iguales por divisor vertical central Estante solo en lado derecho, a media altura
2 puertas iguales (apertura desde centro hacia izquierda y derecha) Calado para ducto extractor: diametro 160 mm
Eje de calado centrado en modulo derecho y a 20 mm del fondo
El calado atraviesa piso, estante derecho y tapa
Codigo | Categoria | Pieza | Cant | Largo | Ancho | Espesor | Cantos | ML gola | Bisagras
AA1 | Casco | Lateral_Izq | 1 | 674.0 | 320.0 | 18.0 | Canto frente
AA10 | Casco | Liston_Fijo_90 | 1 | 885.0 | 90.0 | 18.0 | Sin canto
AA11 | Casco | Extractor_Ref | 1 | 590.0 | 470.0 | 90.0 | Sin canto
AA12 | Herraje | Gola_J_Inferior | 1 | 903.0 | 48.0 | 24.4 | Aluminio
AA2 | Casco | Lateral_Der | 1 | 674.0 | 320.0 | 18.0 | Canto frente
AA3 | Casco | Piso_Casco | 1 | 903.0 | 320.0 | 18.0 | Canto frente
AA4 | Casco | Tapa_Casco | 1 | 903.0 | 320.0 | 18.0 | Sin canto
AA7 | Fondo | Fondo_3mm | 1 | 867.0 | 674.0 | 3.0 | Sin canto
AA8 | Frente | Frente_Izq | 1 | 666.0 | 448.0 | 18.0 | 4 cantos
AA9 | Frente | Frente_Der | 1 | 666.0 | 448.0 | 18.0 | 4 cantos

## Modulo AB - Alacena derecha + cajon AC

### Parametros

Ancho exterior total: 1355 mm

Profundidad: 320 mm
AC inferior en simil paraiso
AB superior en melamina blanca

### Despiece AB

Codigo | Categoria | Pieza | Cant | Largo | Ancho | Espesor | Cantos | ML gola | Bisagras
AB1 | Casco | Lateral_Izq | 1 | 455.0 | 320.0 | 18.0 | Canto frente
AB2 | Casco | Lateral_Der | 1 | 455.0 | 320.0 | 18.0 | Canto frente
AB3 | Casco | Piso | 1 | 1319.0 | 295.6 | 18.0 | Canto frente
AB4 | Casco | Tapa | 1 | 1355.0 | 320.0 | 18.0 | Sin canto
AB5 | Fondo | Fondo_3mm | 1 | 1319.0 | 455.0 | 3.0 | Sin canto
AB6 | Frente | Puerta_1 | 1 | 448.3 | 447.0 | 18.0 | 4 cantos
AB7 | Frente | Puerta_2 | 1 | 448.3 | 447.0 | 18.0 | 4 cantos
AB8 | Frente | Puerta_3 | 1 | 448.3 | 447.0 | 18.0 | 4 cantos
AB9 | Herraje | Gola_J_Inferior | 1 | 1355.0 | 48.0 | 24.4 | Aluminio
AC1 | Casco | Lateral_Izq | 1 | 320.0 | 291.0 | 18.0 | Canto frente
AC2 | Casco | Lateral_Der | 1 | 320.0 | 291.0 | 18.0 | Canto frente
AC3 | Casco | Piso | 1 | 1355.0 | 320.0 | 18.0 | Canto frente
AC4 | Casco | Tapa | 1 | 1355.0 | 320.0 | 18.0 | Sin canto
AC5 | Fondo | Fondo_18mm | 1 | 1319.0 | 291.0 | 18.0 | Sin canto

## Modulo L - Frente armario lavarropas

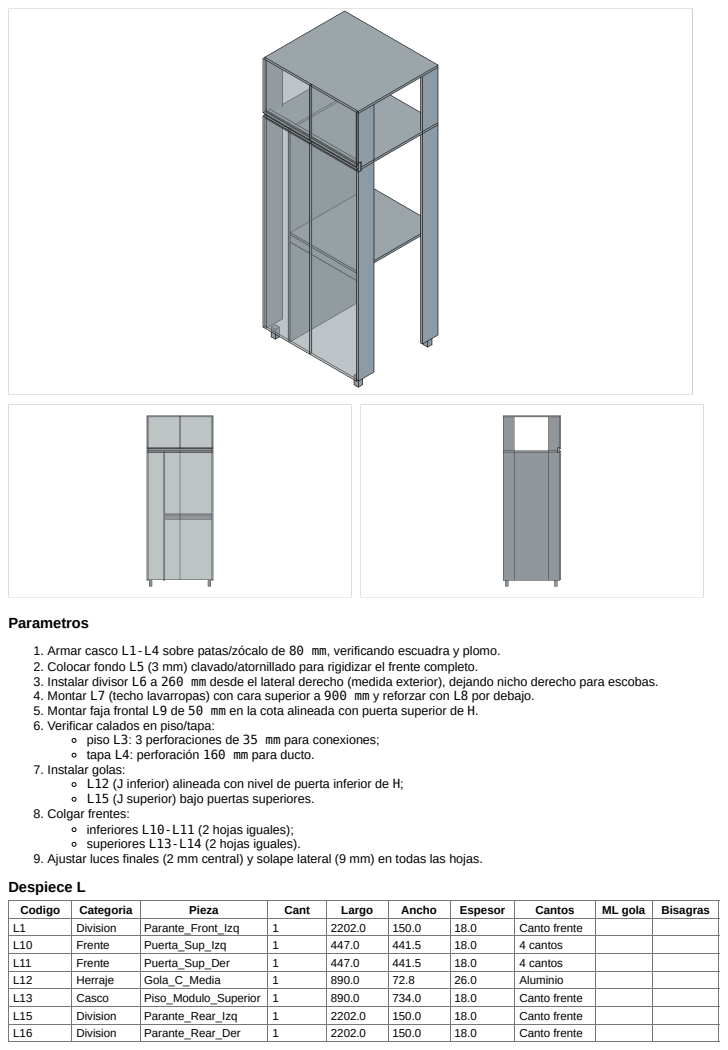
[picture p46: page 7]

1. Armar casco L1-L4 sobre patas/zócalo de 80 mm, verificando escuadra y plomo.
2. Colocar fondo L5 (3 mm) clavado/atornillado para rigidizar el frente completo.
3. Instalar divisor L6 a 260 mm desde el lateral derecho (medida exterior), dejando nicho derecho para escobas.
4. Montar L7 (techo lavarropas) con cara superior a 900 mm y reforzar con L8 por debajo.
5. Montar faja frontal L9 de 50 mm en la cota alineada con puerta superior de H.
6. Verificar calados en piso/tapa:

piso L3: 3 perforaciones de 35 mm para conexiones;
tapa L4: perforación 160 mm para ducto.

L12 (J inferior) alineada con nivel de puerta inferior de H;
L15 (J superior) bajo puertas superiores.

9. Ajustar luces finales (2 mm central) y solape lateral (9 mm) en todas las hojas.
Despiece L

Codigo | Categoria | Pieza | Cant | Largo | Ancho | Espesor | Cantos | ML gola | Bisagras
L1 | Division | Parante_Front_Izq | 1 | 2202.0 | 150.0 | 18.0 | Canto frente
L10 | Frente | Puerta_Sup_Izq | 1 | 447.0 | 441.5 | 18.0 | 4 cantos
L11 | Frente | Puerta_Sup_Der | 1 | 447.0 | 441.5 | 18.0 | 4 cantos
L12 | Herraje | Gola_C_Media | 1 | 890.0 | 72.8 | 26.0 | Aluminio
L13 | Casco | Piso_Modulo_Superior | 1 | 890.0 | 734.0 | 18.0 | Canto frente
L15 | Division | Parante_Rear_Izq | 1 | 2202.0 | 150.0 | 18.0 | Canto frente
L16 | Division | Parante_Rear_Der | 1 | 2202.0 | 150.0 | 18.0 | Canto frente

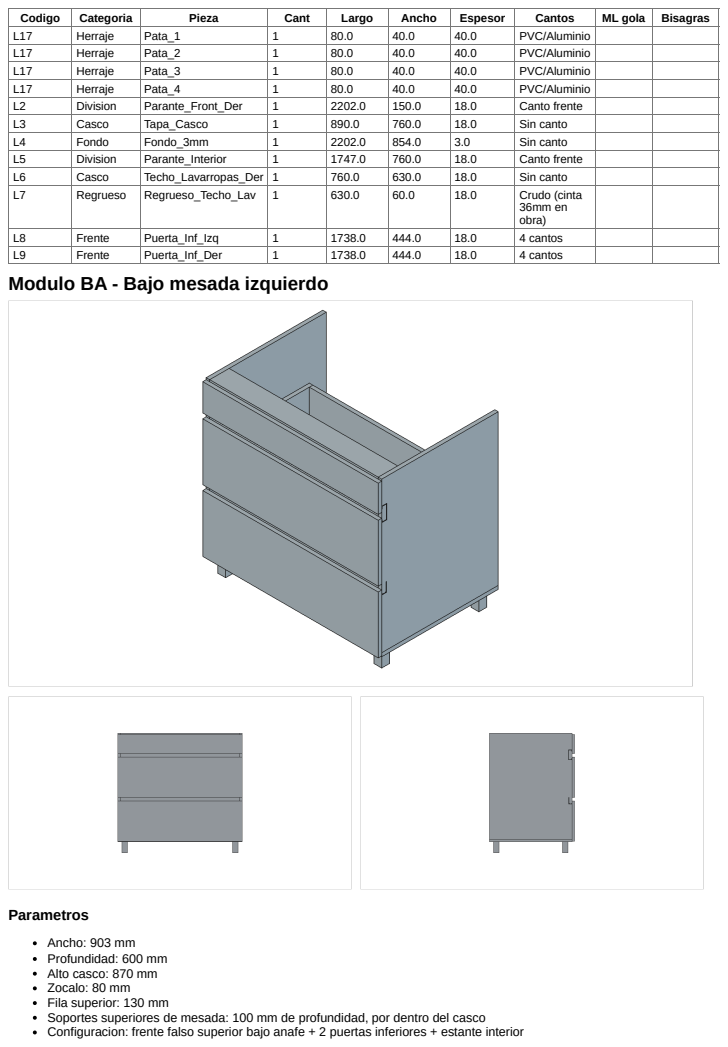
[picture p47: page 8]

Codigo | Categoria | Pieza | Cant | Largo | Ancho | Espesor | Cantos | ML gola | Bisagras
L17 | Herraje | Pata_1 | 1 | 80.0 | 40.0 | 40.0 | PVC/Aluminio
L17 | Herraje | Pata_2 | 1 | 80.0 | 40.0 | 40.0 | PVC/Aluminio
L17 | Herraje | Pata_3 | 1 | 80.0 | 40.0 | 40.0 | PVC/Aluminio
L17 | Herraje | Pata_4 | 1 | 80.0 | 40.0 | 40.0 | PVC/Aluminio
L2 | Division | Parante_Front_Der | 1 | 2202.0 | 150.0 | 18.0 | Canto frente
L3 | Casco | Tapa_Casco | 1 | 890.0 | 760.0 | 18.0 | Sin canto
L4 | Fondo | Fondo_3mm | 1 | 2202.0 | 854.0 | 3.0 | Sin canto
L5 | Division | Parante_Interior | 1 | 1747.0 | 760.0 | 18.0 | Canto frente
L6 | Casco | Techo_Lavarropas_Der | 1 | 760.0 | 630.0 | 18.0 | Sin canto
L7 | Regrueso | Regrueso_Techo_Lav | 1 | 630.0 | 60.0 | 18.0 | Crudo (cinta 36mm en obra)

L8 | Frente | Puerta_Inf_Izq | 1 | 1738.0 | 444.0 | 18.0 | 4 cantos
L9 | Frente | Puerta_Inf_Der | 1 | 1738.0 | 444.0 | 18.0 | 4 cantos

Modulo BA - Bajo mesada izquierdo

Ancho: 903 mm
Profundidad: 600 mm
Alto casco: 870 mm
Zocalo: 80 mm
Fila superior: 130 mm
Soportes superiores de mesada: 100 mm de profundidad, por dentro del casco
Configuracion: frente falso superior bajo anafe + 2 puertas inferiores + estante interior

### Despiece BA

Codigo | Categoria | Pieza | Cant | Largo | Ancho | Espesor | Cantos | ML gola | Bisagras
BA1 | Casco | Lateral_Izq | 1 | 772.0 | 600.0 | 18.0 | Canto frente
BA10 | Frente | Frente_Mid | 1 | 903.0 | 293.0 | 18.0 | 4 cantos
BA11 | Frente | Frente_Bot | 1 | 903.0 | 293.0 | 18.0 | 4 cantos
BA12 | Herraje | Gola_C_Superior | 1 | 903.0 | 72.8 | 26.0 | Aluminio
BA13 | Herraje | Gola_J_Media | 1 | 903.0 | 48.0 | 24.4 | Aluminio
BA14 | Fondo | Caja_Mid_Fondo_6mm | 1 | 841.6 | 500.0 | 6.0 | Fondo clavado pasante
BA14 | Cajon | Caja_Mid_Frente_Caja | 1 | 805.6 | 180.0 | 18.0 | 4 cantos
BA14 | Casco | Caja_Mid_Lateral_Der | 1 | 500.0 | 180.0 | 18.0 | Canto frente
BA14 | Casco | Caja_Mid_Lateral_Izq | 1 | 500.0 | 180.0 | 18.0 | Canto frente
BA14 | Cajon | Caja_Mid_Trasera_Caja | 1 | 805.6 | 180.0 | 18.0 | Sin canto
BA15 | Fondo | Caja_Bot_Fondo_6mm | 1 | 841.6 | 500.0 | 6.0 | Fondo clavado pasante
BA15 | Cajon | Caja_Bot_Frente_Caja | 1 | 805.6 | 180.0 | 18.0 | 4 cantos
BA15 | Casco | Caja_Bot_Lateral_Der | 1 | 500.0 | 180.0 | 18.0 | Canto frente
BA15 | Casco | Caja_Bot_Lateral_Izq | 1 | 500.0 | 180.0 | 18.0 | Canto frente
BA15 | Cajon | Caja_Bot_Trasera_Caja | 1 | 805.6 | 180.0 | 18.0 | Sin canto
BA2 | Casco | Lateral_Der | 1 | 772.0 | 600.0 | 18.0 | Canto frente
BA3 | Casco | Piso_Pasante | 1 | 903.0 | 600.0 | 18.0 | Canto frente
BA3L | Herraje | Pata_1 | 1 | 80.0 | 40.0 | 40.0 | PVC/Aluminio
BA3L | Herraje | Pata_2 | 1 | 80.0 | 40.0 | 40.0 | PVC/Aluminio
BA3L | Herraje | Pata_3 | 1 | 80.0 | 40.0 | 40.0 | PVC/Aluminio
BA3L | Herraje | Pata_4 | 1 | 80.0 | 40.0 | 40.0 | PVC/Aluminio
BA4 | Fondo | Fondo_3mm | 1 | 867.0 | 772.0 | 3.0 | Sin canto
BA5 | Casco | Soporte_Superior_Frente | 1 | 867.0 | 100.0 | 18.0 | 4 cantos
BA6 | Casco | Soporte_Superior_Fondo | 1 | 867.0 | 100.0 | 18.0 | Canto frente
BA9 | Frente | Frente_Falso_Sup | 1 | 903.0 | 139.0 | 18.0 | 4 cantos

## Modulo BB - Bajo mesada derecho

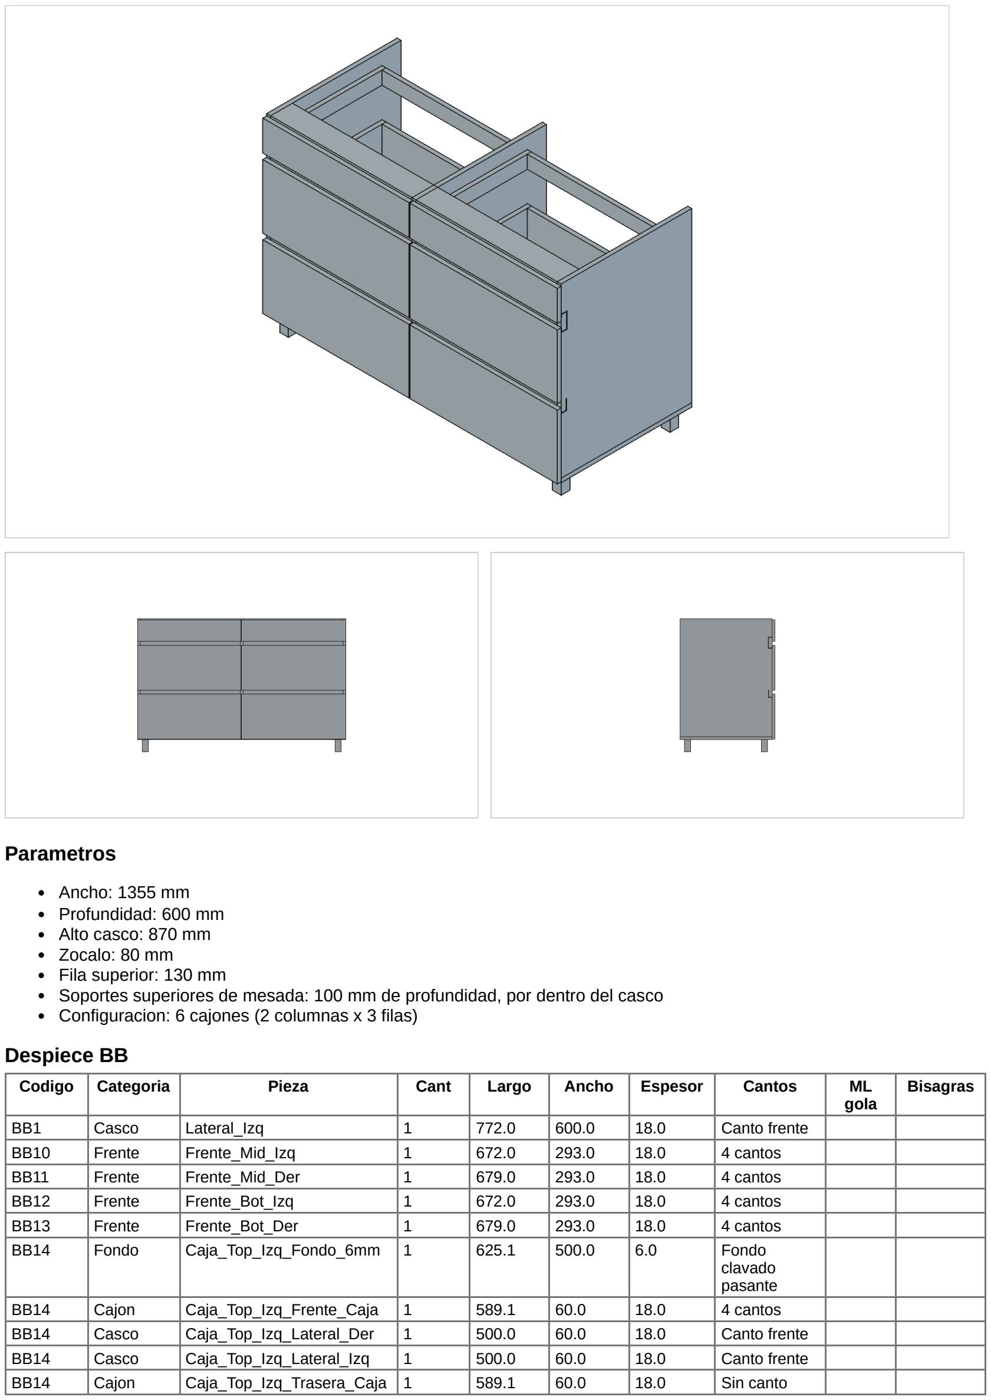
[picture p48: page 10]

### Parametros

Ancho: 1355 mm
Profundidad: 600 mm
Alto casco: 870 mm
Zocalo: 80 mm
Fila superior: 130 mm
Soportes superiores de mesada: 100 mm de profundidad, por dentro del casco
Configuracion: 6 cajones (2 columnas x 3 filas)

### Despiece BB

Codigo | Categoria | Pieza | Cant | Largo | Ancho | Espesor | Cantos | ML gola | Bisagras
BB1 | Casco | Lateral_Izq | 1 | 772.0 | 600.0 | 18.0 | Canto frente
BB10 | Frente | Frente_Mid_Izq | 1 | 672.0 | 293.0 | 18.0 | 4 cantos
BB11 | Frente | Frente_Mid_Der | 1 | 679.0 | 293.0 | 18.0 | 4 cantos
BB12 | Frente | Frente_Bot_Izq | 1 | 672.0 | 293.0 | 18.0 | 4 cantos
BB13 | Frente | Frente_Bot_Der | 1 | 679.0 | 293.0 | 18.0 | 4 cantos
BB14 | Fondo | Caja_Top_Izq_Fondo_6mm | 1 | 625.1 | 500.0 | 6.0 | Fondo clavado pasante
BB14 | Cajon | Caja_Top_Izq_Frente_Caja | 1 | 589.1 | 60.0 | 18.0 | 4 cantos
BB14 | Casco | Caja_Top_Izq_Lateral_Der | 1 | 500.0 | 60.0 | 18.0 | Canto frente
BB14 | Casco | Caja_Top_Izq_Lateral_Izq | 1 | 500.0 | 60.0 | 18.0 | Canto frente
BB14 | Cajon | Caja_Top_Izq_Trasera_Caja | 1 | 589.1 | 60.0 | 18.0 | Sin canto

Codigo | Categoria | Pieza | Cant | Largo | Ancho | Espesor | Cantos | ML gola | Bisagras
BB15 | Fondo | Caja_Top_Der_Fondo_6mm | 1 | 625.1 | 500.0 | 6.0 | Fondo clavado pasante
BB15 | Cajon | Caja_Top_Der_Frente_Caja | 1 | 589.1 | 60.0 | 18.0 | 4 cantos
BB15 | Casco | Caja_Top_Der_Lateral_Der | 1 | 500.0 | 60.0 | 18.0 | Canto frente
BB15 | Casco | Caja_Top_Der_Lateral_Izq | 1 | 500.0 | 60.0 | 18.0 | Canto frente
BB15 | Cajon | Caja_Top_Der_Trasera_Caja | 1 | 589.1 | 60.0 | 18.0 | Sin canto
BB16 | Fondo | Caja_Mid_Izq_Fondo_6mm | 1 | 625.1 | 500.0 | 6.0 | Fondo clavado pasante
BB16 | Cajon | Caja_Mid_Izq_Frente_Caja | 1 | 589.1 | 180.0 | 18.0 | 4 cantos
BB16 | Casco | Caja_Mid_Izq_Lateral_Der | 1 | 500.0 | 180.0 | 18.0 | Canto frente
BB16 | Casco | Caja_Mid_Izq_Lateral_Izq | 1 | 500.0 | 180.0 | 18.0 | Canto frente
BB16 | Cajon | Caja_Mid_Izq_Trasera_Caja | 1 | 589.1 | 180.0 | 18.0 | Sin canto
BB17 | Fondo | Caja_Mid_Der_Fondo_6mm | 1 | 625.1 | 500.0 | 6.0 | Fondo clavado pasante
BB17 | Cajon | Caja_Mid_Der_Frente_Caja | 1 | 589.1 | 180.0 | 18.0 | 4 cantos
BB17 | Casco | Caja_Mid_Der_Lateral_Der | 1 | 500.0 | 180.0 | 18.0 | Canto frente
BB17 | Casco | Caja_Mid_Der_Lateral_Izq | 1 | 500.0 | 180.0 | 18.0 | Canto frente
BB17 | Cajon | Caja_Mid_Der_Trasera_Caja | 1 | 589.1 | 180.0 | 18.0 | Sin canto
BB18 | Fondo | Caja_Bot_Izq_Fondo_6mm | 1 | 625.1 | 500.0 | 6.0 | Fondo clavado pasante
BB18 | Cajon | Caja_Bot_Izq_Frente_Caja | 1 | 589.1 | 180.0 | 18.0 | 4 cantos
BB18 | Casco | Caja_Bot_Izq_Lateral_Der | 1 | 500.0 | 180.0 | 18.0 | Canto frente
BB18 | Casco | Caja_Bot_Izq_Lateral_Izq | 1 | 500.0 | 180.0 | 18.0 | Canto frente
BB18 | Cajon | Caja_Bot_Izq_Trasera_Caja | 1 | 589.1 | 180.0 | 18.0 | Sin canto
BB19 | Fondo | Caja_Bot_Der_Fondo_6mm | 1 | 625.1 | 500.0 | 6.0 | Fondo clavado pasante
BB19 | Cajon | Caja_Bot_Der_Frente_Caja | 1 | 589.1 | 180.0 | 18.0 | 4 cantos
BB19 | Casco | Caja_Bot_Der_Lateral_Der | 1 | 500.0 | 180.0 | 18.0 | Canto frente
BB19 | Casco | Caja_Bot_Der_Lateral_Izq | 1 | 500.0 | 180.0 | 18.0 | Canto frente
BB19 | Cajon | Caja_Bot_Der_Trasera_Caja | 1 | 589.1 | 180.0 | 18.0 | Sin canto
BB2 | Casco | Lateral_Der | 1 | 772.0 | 600.0 | 18.0 | Canto frente
BB20 | Herraje | Gola_C_Superior | 1 | 1355.0 | 72.8 | 26.0 | Aluminio
BB21 | Herraje | Gola_J_Media | 1 | 1355.0 | 48.0 | 24.4 | Aluminio
BB3 | Casco | Piso_Pasante | 1 | 1355.0 | 600.0 | 18.0 | Canto frente
BB3L | Herraje | Pata_1 | 1 | 80.0 | 40.0 | 40.0 | PVC/Aluminio
BB3L | Herraje | Pata_2 | 1 | 80.0 | 40.0 | 40.0 | PVC/Aluminio
BB3L | Herraje | Pata_3 | 1 | 80.0 | 40.0 | 40.0 | PVC/Aluminio
BB3L | Herraje | Pata_4 | 1 | 80.0 | 40.0 | 40.0 | PVC/Aluminio
BB4 | Fondo | Fondo_3mm | 1 | 1319.0 | 772.0 | 3.0 | Sin canto
BB5 | Casco | Soporte_Superior_Frente | 1 | 1319.0 | 100.0 | 18.0 | 4 cantos
BB6 | Casco | Soporte_Superior_Fondo | 1 | 1319.0 | 100.0 | 18.0 | Canto frente
BB7 | Division | Divisor_Central | 1 | 772.0 | 600.0 | 18.0 | Canto frente
BB8 | Frente | Frente_Top_Izq | 1 | 672.0 | 139.0 | 18.0 | 4 cantos
BB9 | Frente | Frente_Top_Der | 1 | 679.0 | 139.0 | 18.0 | 4 cantos

## Modulo F - Mueble heladera + modular

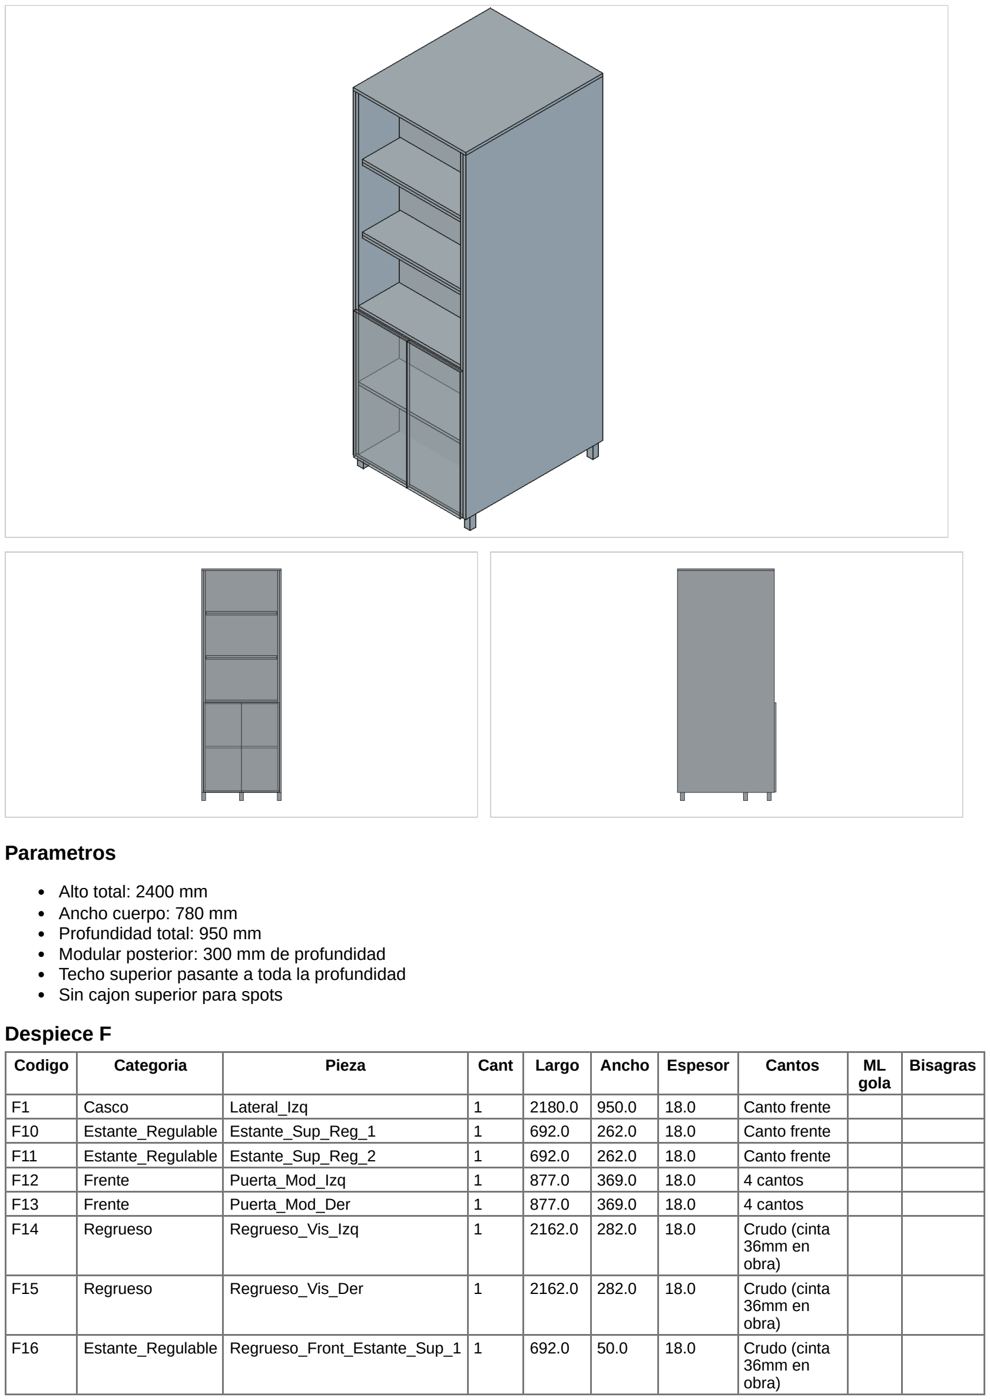
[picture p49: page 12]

### Parametros

Alto total: 2400 mm
Ancho cuerpo: 780 mm
Profundidad total: 950 mm
Modular posterior: 300 mm de profundidad Techo superior pasante a toda la profundidad
Sin cajon superior para spots

### Despiece F

Codigo | Categoria | Pieza | Cant | Largo | Ancho | Espesor | Cantos | ML gola | Bisagras
F1 | Casco | Lateral_Izq | 1 | 2180.0 | 950.0 | 18.0 | Canto frente
F10 | Estante_Regulable | Estante_Sup_Reg_1 | 1 | 692.0 | 262.0 | 18.0 | Canto frente
F11 | Estante_Regulable | Estante_Sup_Reg_2 | 1 | 692.0 | 262.0 | 18.0 | Canto frente
F12 | Frente | Puerta_Mod_Izq | 1 | 877.0 | 369.0 | 18.0 | 4 cantos
F13 | Frente | Puerta_Mod_Der | 1 | 877.0 | 369.0 | 18.0 | 4 cantos
F14 | Regrueso | Regrueso_Vis_Izq | 1 | 2162.0 | 282.0 | 18.0 | Crudo (cinta 36mm en obra)
F15 | Regrueso | Regrueso_Vis_Der | 1 | 2162.0 | 282.0 | 18.0 | Crudo (cinta 36mm en obra)
F16 | Estante_Regulable | Regrueso_Front_Estante_Sup_1 | 1 | 692.0 | 50.0 | 18.0 | Crudo (cinta 36mm en obra)

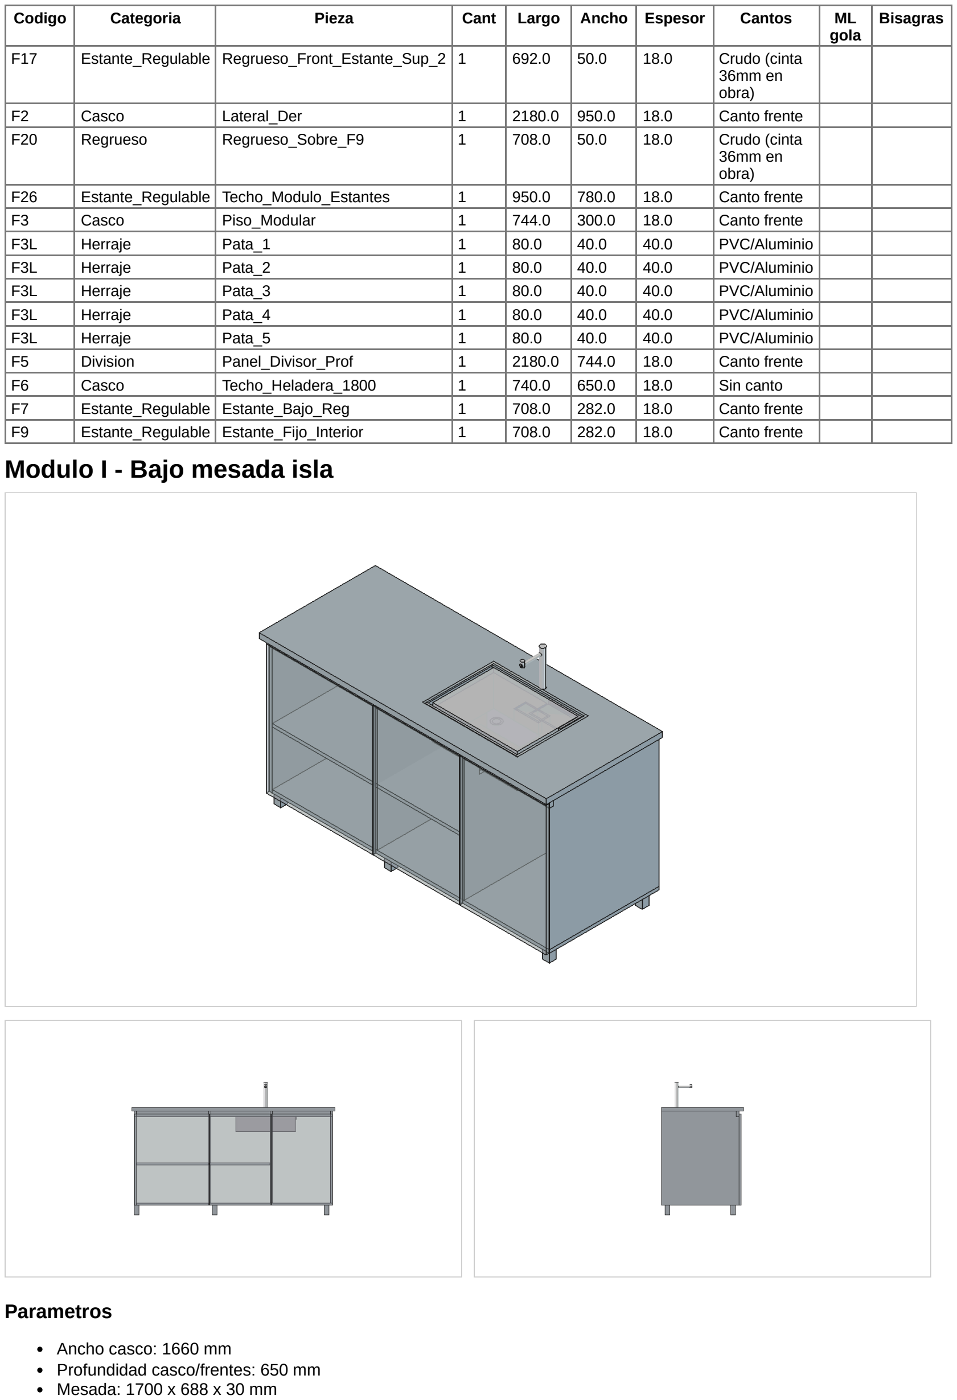
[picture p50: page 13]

Codigo | Categoria | Pieza | Cant | Largo | Ancho | Espesor | Cantos | ML gola | Bisagras
F17 | Estante_Regulable | Regrueso_Front_Estante_Sup_2 | 1 | 692.0 | 50.0 | 18.0 | Crudo (cinta 36mm en obra)
F2 | Casco | Lateral_Der | 1 | 2180.0 | 950.0 | 18.0 | Canto frente
F20 | Regrueso | Regrueso_Sobre_F9 | 1 | 708.0 | 50.0 | 18.0 | Crudo (cinta 36mm en obra)
F26 | Estante_Regulable | Techo_Modulo_Estantes | 1 | 950.0 | 780.0 | 18.0 | Canto frente
F3 | Casco | Piso_Modular | 1 | 744.0 | 300.0 | 18.0 | Canto frente
F3L | Herraje | Pata_1 | 1 | 80.0 | 40.0 | 40.0 | PVC/Aluminio
F3L | Herraje | Pata_2 | 1 | 80.0 | 40.0 | 40.0 | PVC/Aluminio
F3L | Herraje | Pata_3 | 1 | 80.0 | 40.0 | 40.0 | PVC/Aluminio
F3L | Herraje | Pata_4 | 1 | 80.0 | 40.0 | 40.0 | PVC/Aluminio
F3L | Herraje | Pata_5 | 1 | 80.0 | 40.0 | 40.0 | PVC/Aluminio
F5 | Division | Panel_Divisor_Prof | 1 | 2180.0 | 744.0 | 18.0 | Canto frente
F6 | Casco | Techo_Heladera_1800 | 1 | 740.0 | 650.0 | 18.0 | Sin canto
F7 | Estante_Regulable | Estante_Bajo_Reg | 1 | 708.0 | 282.0 | 18.0 | Canto frente
F9 | Estante_Regulable | Estante_Fijo_Interior | 1 | 708.0 | 282.0 | 18.0 | Canto frente

## Modulo I - Bajo mesada isla

### Parametros

Ancho casco: 1660 mm
Profundidad casco/frentes: 650 mm Mesada: 1700 x 688 x 30 mm

Alto casco: 870 mm
Zocalo/patas: 80 mm
Nicho lavavajillas libre: 605 mm
Sector bajo bacha: 1037 mm de ancho total
Dos puertas bajo bacha con divisor central
Piso falso removible en lavavajillas + estante removible al mismo nivel del estante bajo bacha

### Despiece I

Codigo | Categoria | Pieza | Cant | Largo | Ancho | Espesor | Cantos | ML gola | Bisagras
I1 | Casco | Lateral_Izq_Frente | 1 | 790.0 | 650.0 | 18.0 | 4 cantos
I10 | Casco | Soporte_Sup_Fondo | 1 | 1037.0 | 100.0 | 18.0 | Canto frente
I11 | Herraje | Pata_Back_1 | 1 | 80.0 | 40.0 | 40.0 | PVC/Aluminio
I11 | Herraje | Pata_Back_2 | 1 | 80.0 | 40.0 | 40.0 | PVC/Aluminio
I11 | Herraje | Pata_Back_3 | 1 | 80.0 | 40.0 | 40.0 | PVC/Aluminio
I11 | Herraje | Pata_Front_1 | 1 | 80.0 | 40.0 | 40.0 | PVC/Aluminio
I11 | Herraje | Pata_Front_2 | 1 | 80.0 | 40.0 | 40.0 | PVC/Aluminio
I11 | Herraje | Pata_Front_3 | 1 | 80.0 | 40.0 | 40.0 | PVC/Aluminio
I12 | Herraje | Gola_J_Superior | 1 | 1660.0 | 48.0 | 24.4 | Aluminio
I17 | Frente | Puerta_Lavavajillas | 1 | 764.0 | 628.5 | 18.0 | 4 cantos
I18 | Frente | Puerta_Bacha_Izq | 1 | 764.0 | 510.8 | 18.0 | 4 cantos
I18B | Frente | Puerta_Bacha_Der | 1 | 764.0 | 510.8 | 18.0 | 4 cantos
I2 | Casco | Lateral_Der | 1 | 772.0 | 650.0 | 18.0 | Canto frente
I20 | Mesada | Mesada_Calado_Bacha | 1 | 1700.0 | 688.0 | 30.0 | Sin canto
I3 | Division | Division_1 | 1 | 772.0 | 650.0 | 18.0 | Canto frente
I4 | Division | Division_2 | 1 | 772.0 | 650.0 | 18.0 | Canto frente
I6 | Casco | Piso_Der | 1 | 1037.0 | 650.0 | 18.0 | Canto frente
I8 | Estante_Regulable | Estante_Regulable_Bacha | 1 | 612.0 | 509.8 | 18.0 | Canto frente
I8B | Casco | Piso_Removible_Lavavajillas | 1 | 612.0 | 601.0 | 18.0 | Canto frente
I8C | Casco | Piso_Falso_Lavavajillas | 1 | 612.0 | 601.0 | 18.0 | Canto frente
I9 | Casco | Soporte_Sup_Frente | 1 | 1624.0 | 100.0 | 18.0 | 4 cantos

## Modulo R - Rinconera

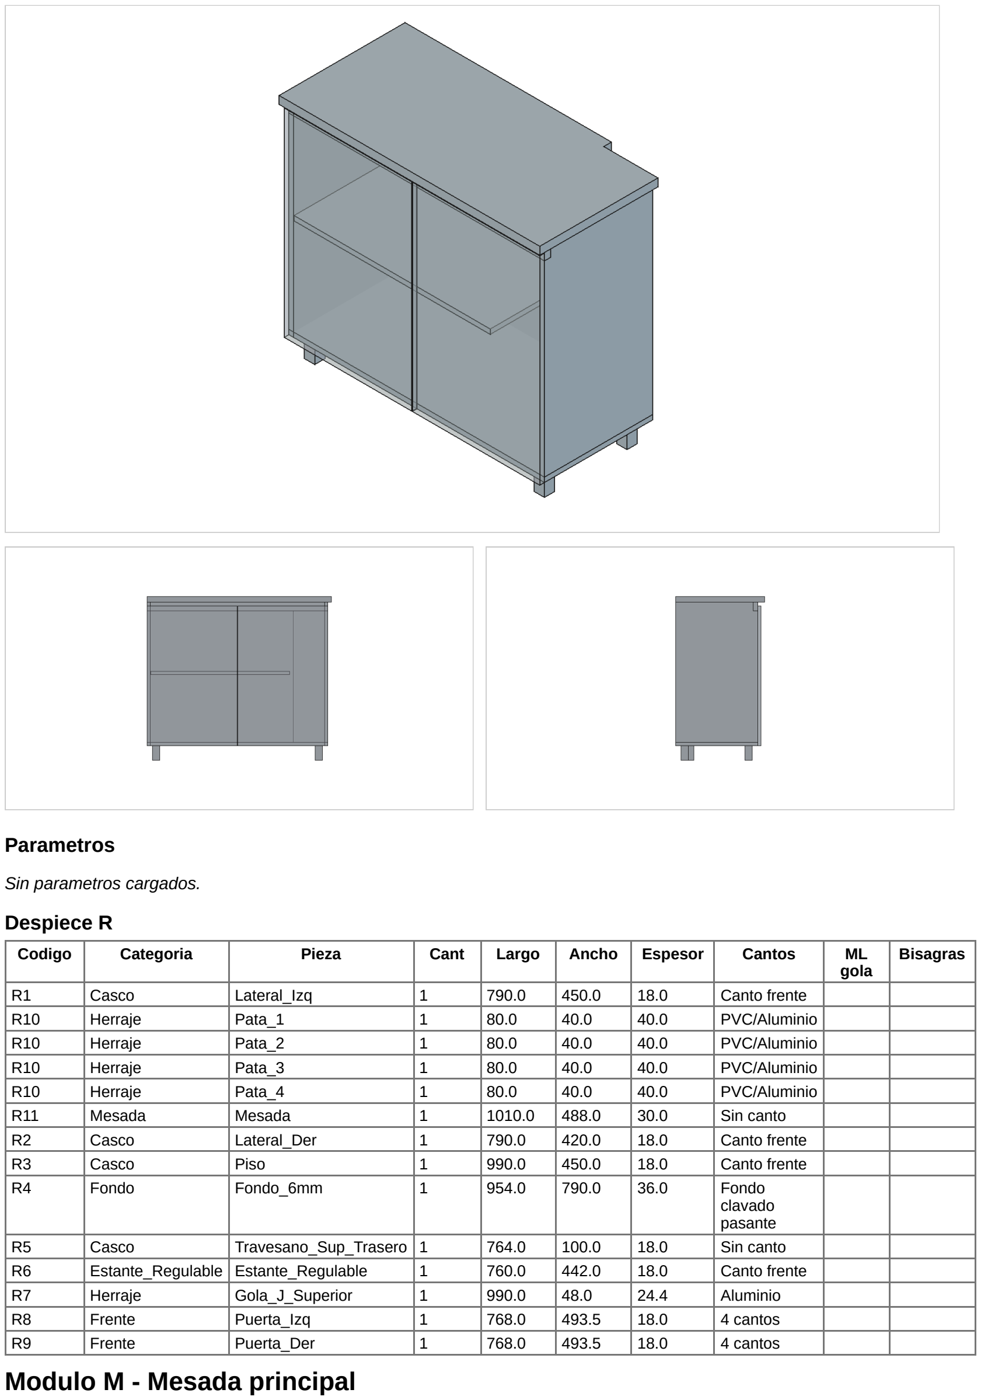
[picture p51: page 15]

### Parametros

Sin parametros cargados.

### Despiece R

Codigo | Categoria | Pieza | Cant | Largo | Ancho | Espesor | Cantos | ML gola | Bisagras
R1 | Casco | Lateral_Izq | 1 | 790.0 | 450.0 | 18.0 | Canto frente
R10 | Herraje | Pata_1 | 1 | 80.0 | 40.0 | 40.0 | PVC/Aluminio
R10 | Herraje | Pata_2 | 1 | 80.0 | 40.0 | 40.0 | PVC/Aluminio
R10 | Herraje | Pata_3 | 1 | 80.0 | 40.0 | 40.0 | PVC/Aluminio
R10 | Herraje | Pata_4 | 1 | 80.0 | 40.0 | 40.0 | PVC/Aluminio
R11 | Mesada | Mesada | 1 | 1010.0 | 488.0 | 30.0 | Sin canto
R2 | Casco | Lateral_Der | 1 | 790.0 | 420.0 | 18.0 | Canto frente
R3 | Casco | Piso | 1 | 990.0 | 450.0 | 18.0 | Canto frente
R4 | Fondo | Fondo_6mm | 1 | 954.0 | 790.0 | 36.0 | Fondo clavado pasante
R5 | Casco | Travesano_Sup_Trasero | 1 | 764.0 | 100.0 | 18.0 | Sin canto
R6 | Estante_Regulable | Estante_Regulable | 1 | 760.0 | 442.0 | 18.0 | Canto frente
R7 | Herraje | Gola_J_Superior | 1 | 990.0 | 48.0 | 24.4 | Aluminio
R8 | Frente | Puerta_Izq | 1 | 768.0 | 493.5 | 18.0 | 4 cantos
R9 | Frente | Puerta_Der | 1 | 768.0 | 493.5 | 18.0 | 4 cantos

## Modulo M - Mesada principal

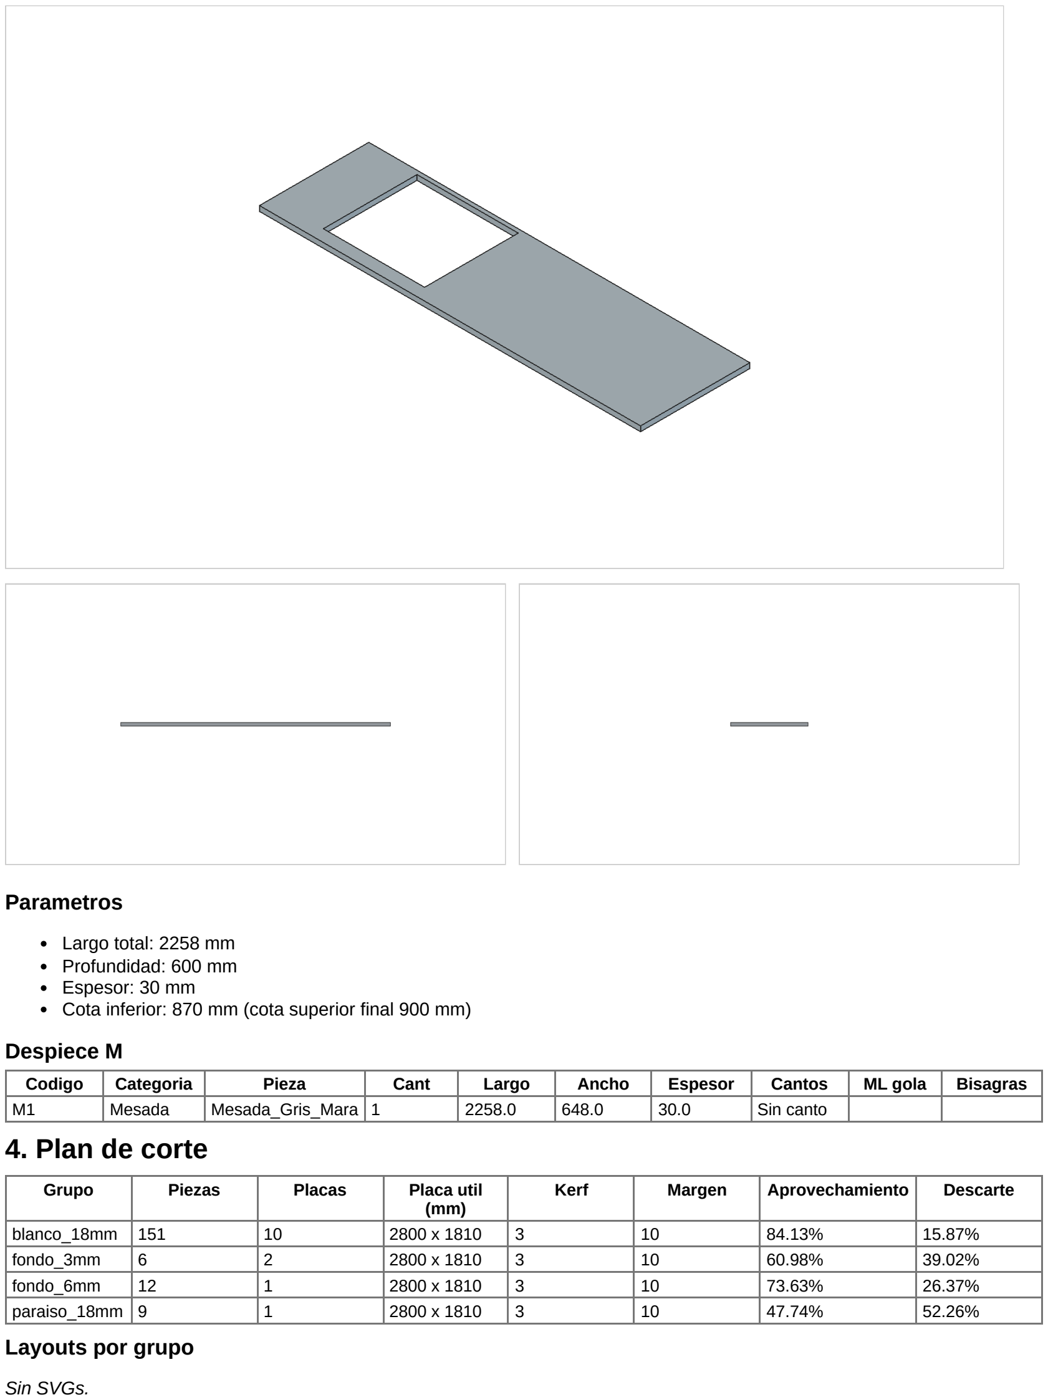
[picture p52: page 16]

### Parametros

Largo total: 2258 mm
Profundidad: 600 mm
Espesor: 30 mm
Cota inferior: 870 mm (cota superior final 900 mm)

### Despiece M

Codigo | Categoria | Pieza | Cant | Largo | Ancho | Espesor | Cantos | ML gola | Bisagras
M1 | Mesada | Mesada_Gris_Mara | 1 | 2258.0 | 648.0 | 30.0 | Sin canto

## 4. Plan de corte

Grupo | Piezas | Placas | Placa util (mm) | Kerf | Margen | Aprovechamiento | Descarte
blanco_18mm | 151 | 10 | 2800 x 1810 | 3 | 10 | 84.13% | 15.87%
fondo_3mm | 6 | 2 | 2800 x 1810 | 3 | 10 | 60.98% | 39.02%
fondo_6mm | 12 | 1 | 2800 x 1810 | 3 | 10 | 73.63% | 26.37%
paraiso_18mm | 9 | 1 | 2800 x 1810 | 3 | 10 | 47.74% | 52.26%

### Layouts por grupo

Sin SVGs.

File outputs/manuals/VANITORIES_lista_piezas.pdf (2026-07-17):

# Vanitory reforma 770 mm

Lista unitaria de corte. 24 piezas. Cantos: I=izq, D=der, S=sup, I=inf.

Codigo | Pieza | Material | Medidas (mm) | Cantos I D S I | Bisagras
VS_01_base_inf_pas | Base inferior pasante | Melamina blanca | 770 x 500 x 18 | 1 0 0 0
VS_02_lat_izq_base | Lateral izquierdo sobre base | Melamina blanca | 702 x 500 x 18 | 1 0 0 0
VS_03_lat_der_base | Lateral derecho sobre base | Melamina blanca | 702 x 500 x 18 | 1 0 0 0
VS_04_riel_sup_front_so p | Riel superior frontal soporte piedra | Melamina blanca | 734 x 100 x 18 | 1 0 0 0
VS_05_riel_sup_tras_so p | Riel superior trasero soporte piedra | Melamina blanca | 734 x 100 x 18 | 0 0 0 0
VS_06_est_reg_comp | Estante regulable completo | Melamina blanca | 734 x 470 x 18 | 1 0 0 0
VS_17_faja_cent_izq_so p | Faja central izquierda soporte corredera | Melamina blanca | 500 x 180 x 18 | 0 0 0 0
VS_18_faja_cent_der_so p | Faja central derecha soporte corredera | Melamina blanca | 500 x 180 x 18 | 0 0 0 0
VS_07_fte_caj_izq | Frente cajon izquierdo | Melamina blanca | 380 x 180 x 18 | 1 1 1 1
VS_08_fte_caj_der | Frente cajon derecho | Melamina blanca | 380 x 180 x 18 | 1 1 1 1
VS_09_pta_inf_izq | Puerta inferior izquierda | Melamina blanca | 510 x 380 x 18 | 1 1 1 1 | 2 x 35 mm (left)
VS_10_pta_inf_der | Puerta inferior derecha | Melamina blanca | 510 x 380 x 18 | 1 1 1 1 | 2 x 35 mm (right)
VS_11a_lat_izq_caj_izq | Lateral izquierdo cajon izquierdo | Melamina blanca | 300 x 140 x 18 | 0 0 1 0
VS_11b_lat_der_caj_izq | Lateral derecho cajon izquierdo | Melamina blanca | 300 x 140 x 18 | 0 0 1 0
VS_11c_trasfte_caj_izq | Trasfrente cajon izquierdo | Melamina blanca | 283 x 140 x 18 | 0 0 1 0
VS_11d_ctrfte_caj_izq | Contrafrente cajon izquierdo | Melamina blanca | 283 x 140 x 18 | 0 0 1 0
VS_11e_fondo_caj_izq | Fondo cajon izquierdo | Fondo cajon 5 mm | 300 x 283 x 5 | 0 0 0 0
VS_12a_lat_izq_caj_der | Lateral izquierdo cajon derecho | Melamina blanca | 300 x 140 x 18 | 0 0 1 0
VS_12b_lat_der_caj_der | Lateral derecho cajon derecho | Melamina blanca | 300 x 140 x 18 | 0 0 1 0
VS_12c_trasfte_caj_der | Trasfrente cajon derecho | Melamina blanca | 283 x 140 x 18 | 0 0 1 0
VS_12d_ctrfte_caj_der | Contrafrente cajon derecho | Melamina blanca | 283 x 140 x 18 | 0 0 1 0
VS_12e_fondo_caj_der | Fondo cajon derecho | Fondo cajon 5 mm | 300 x 283 x 5 | 0 0 0 0
VS_15_zoc_mes_piedra _tras | Zocalo mesada piedra trasero | Piedra negra | 770 x 120 x 20 | 0 0 0 0
VS_16_piedra_sup | Piedra superior | Piedra negra | 770 x 533 x 20 | 0 0 0 0

# Vanitory reforma 830 mm

Lista unitaria de corte. 24 piezas. Cantos: I=izq, D=der, S=sup, I=inf.

Codigo | Pieza | Material | Medidas (mm) | Cantos I D S I | Bisagras
VC_01_base_inf_pas | Base inferior pasante | Melamina blanca | 820 x 407 x 18 | 1 0 0 0
VC_02_lat_izq_base | Lateral izquierdo sobre base | Melamina blanca | 702 x 407 x 18 | 1 0 0 0
VC_03_lat_der_base | Lateral derecho sobre base | Melamina blanca | 702 x 407 x 18 | 1 0 0 0
VC_04_riel_sup_front_s op | Riel superior frontal soporte piedra | Melamina blanca | 784 x 100 x 18 | 1 0 0 0
VC_05_riel_sup_tras_so p | Riel superior trasero soporte piedra | Melamina blanca | 784 x 100 x 18 | 0 0 0 0
VC_06_est_reg_comp | Estante regulable completo | Melamina blanca | 784 x 377 x 18 | 1 0 0 0
VC_17_faja_cent_izq_so p | Faja central izquierda soporte corredera | Melamina blanca | 407 x 180 x 18 | 0 0 0 0
VC_18_faja_cent_der_s op | Faja central derecha soporte corredera | Melamina blanca | 407 x 180 x 18 | 0 0 0 0
VC_07_fte_caj_izq | Frente cajon izquierdo | Melamina blanca | 405 x 180 x 18 | 1 1 1 1
VC_08_fte_caj_der | Frente cajon derecho | Melamina blanca | 405 x 180 x 18 | 1 1 1 1
VC_09_pta_inf_izq | Puerta inferior izquierda | Melamina blanca | 510 x 405 x 18 | 1 1 1 1 | 2 x 35 mm (left)
VC_10_pta_inf_der | Puerta inferior derecha | Melamina blanca | 510 x 405 x 18 | 1 1 1 1 | 2 x 35 mm (right)
VC_11a_lat_izq_caj_izq | Lateral izquierdo cajon izquierdo | Melamina blanca | 300 x 140 x 18 | 0 0 1 0
VC_11b_lat_der_caj_izq | Lateral derecho cajon izquierdo | Melamina blanca | 300 x 140 x 18 | 0 0 1 0
VC_11c_trasfte_caj_izq | Trasfrente cajon izquierdo | Melamina blanca | 308 x 140 x 18 | 0 0 1 0
VC_11d_ctrfte_caj_izq | Contrafrente cajon izquierdo | Melamina blanca | 308 x 140 x 18 | 0 0 1 0
VC_11e_fondo_caj_izq | Fondo cajon izquierdo | Fondo cajon 5 mm | 308 x 300 x 5 | 0 0 0 0
VC_12a_lat_izq_caj_der | Lateral izquierdo cajon derecho | Melamina blanca | 300 x 140 x 18 | 0 0 1 0
VC_12b_lat_der_caj_der | Lateral derecho cajon derecho | Melamina blanca | 300 x 140 x 18 | 0 0 1 0
VC_12c_trasfte_caj_der | Trasfrente cajon derecho | Melamina blanca | 308 x 140 x 18 | 0 0 1 0
VC_12d_ctrfte_caj_der | Contrafrente cajon derecho | Melamina blanca | 308 x 140 x 18 | 0 0 1 0
VC_12e_fondo_caj_der | Fondo cajon derecho | Fondo cajon 5 mm | 308 x 300 x 5 | 0 0 0 0
VC_15_zoc_mes_piedra _tras | Zocalo mesada piedra trasero | Piedra negra | 820 x 120 x 20 | 0 0 0 0
VC_16_piedra_sup | Piedra superior | Piedra negra | 820 x 440 x 20 | 0 0 0 0

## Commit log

2026-03-10 Inicial: columna horno/micro con modelo FreeCAD, BOM, renders y documentación
    [columna_horno_micro.FCStd, columna_horno_micro.step, columna_horno_micro_bom.csv]
2026-03-10 Ajusta mueble H: 3 fajas 50mm, solapes 9mm y flujo de screenshots
    [columna_horno_micro.FCStd, columna_horno_micro.step, columna_horno_micro_bom.csv]
2026-03-10 Corrige visibilidad persistente en FCStd y robustez de make model
    [columna_horno_micro.FCStd, columna_horno_micro.step]
2026-03-10 Add manual PDF pipeline and snapshot assets; simplify Makefile
    [columna_horno_micro.FCStd]
2026-03-10 Add AA and AB upper cabinet modules; switch to pass-through top/bottom; remove AB divider
    [alacena_AA.FCStd, alacena_AA.step, alacena_AA_bom.csv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]
2026-03-10 Update AB/AC nomenclature and add AA/AB manuals with PDF outputs
    [alacena_AB.FCStd, alacena_AB.step, alacena_AB_bom.csv]
2026-03-10 Add BA/BB base cabinets, AC back panel, and countertop slab with cooktop cutout
    [alacena_AB.FCStd, alacena_AB_bom.csv, bajo_BA.FCStd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]
2026-03-10 Adjust BA/BB side panels under top supports and regenerate models
    [bajo_BA.FCStd, bajo_BA.step, bajo_BA_bom.csv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]
2026-03-10 Refine base cabinets and countertop details; add open drawer view in BB
    [bajo_BB.FCStd, bajo_BB.step, mesada.FCStd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]
2026-03-10 Ajusta anchos globales y regrueso frontal de horno
    [alacena_AA.FCStd, alacena_AA.step, alacena_AA_bom.csv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]
2026-03-10 Ajusta grilla continua BA-BB y actualiza anchos de modulos
    [alacena_AB.FCStd, alacena_AB.step, alacena_AB_bom.csv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]
2026-03-10 Alinea H a grilla de bajos y corrige orientacion de regruesos
    [alacena_AB.FCStd, alacena_AB.step, alacena_AB_bom.csv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]
2026-03-10 Alinea alacenas superiores contra fondo en ensamble
    [cocina_ensamble.FCStd, cocina_ensamble.step]
2026-03-10 Ajusta grilla global con axiomas de cotas y perfileria gola
    [alacena_AA.FCStd, alacena_AA.step, alacena_AA_bom.csv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]
2026-03-10 Ajuste final de grilla, simetria y continuidad visual
    [alacena_AA.FCStd, alacena_AA.step, alacena_AA_bom.csv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]
2026-03-10 Ajusta grilla BA/BB y alinea lineas de gola con H
    [alacena_AA.FCStd, alacena_AA.step, alacena_AB.FCStd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]
2026-03-10 Ajusta AA/BA: calados, gola y extractor biselado
    [alacena_AA.FCStd, alacena_AA.step, alacena_AA_bom.csv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]
2026-03-10 Ajustes finales AA/BA y fondos pasantes de cajones
    [bajo_BA.FCStd, bajo_BA.step, bajo_BA_bom.csv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]
2026-03-10 Normaliza prefijos y macro de screenshots para exportacion multi-documento
    [AA.FCStd, AA.step, AA_bom.csv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]
2026-03-10 Agrega optimizador de cortes OR-Tools y ajustes de nomenclatura/outputs
    [H.FCStd, H.step, H_bom.csv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]
2026-03-11 Ajusta modulo L: 2+2 puertas, profundidad 800, patas 80 y update ENS
    [ENS.FCStd, ENS.step, L.FCStd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]
2026-03-11 Actualiza modulo L: 2+2 puertas, gola C media, profundidad 760 y ajuste ENS
    [ENS.FCStd, ENS.step, L.FCStd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]
2026-03-11 Actualiza modelos, ensamble y capturas; corrige extractor y listones H
    [AA.FCStd, AA.step, ENS.FCStd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]
2026-03-11 Actualiza plan de cortes y manual integral con layouts SVG
    [blanco_18mm_placements.csv, fondo_3mm_placements.csv, summary.csv]
2026-03-11 Regenera proyecto completo: modelos, BOM, cortes y manual
    [AA.FCStd, AA.step, AB.FCStd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]
2026-03-11 Actualiza optimizacion de cortes para placa 2820x1830
    [blanco_18mm_placements.csv, fondo_3mm_placements.csv, fondo_6mm_placements.csv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]
2026-03-11 Ajusta modulo F: solapes, grilla, interferencias y nota de cantos crudos
    [F.FCStd, F.step, F_bom.csv]
2026-03-11 Ajusta modulo I: frentes C/R iguales, parante union, pisos internos y bacha centrada
    [ENSI.FCStd, ENSI.step, I.FCStd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]
2026-03-11 Ajusta I integrado, soportes internos y elimina modelo V
    [BA.FCStd, BA.step, BA_bom.csv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]
2026-03-12 Ajusta cajon superior de F
    [ENSI.FCStd, ENSI.step, F.FCStd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]
2026-03-12 Ajusta F e I y actualiza reglas de corte
    [ENSI.FCStd, ENSI.step, F.FCStd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]
2026-03-12 Checkpoint I con nicho y cava
    [ENSI.FCStd, ENSI.step, I.FCStd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]
2026-03-12 Checkpoint ajustes parciales de I
    [I.FCStd, I.step, I_bom.csv]
2026-03-12 Ajusta fondo I1B y base V3 en I
    [I.FCStd, I.step, I_bom.csv]
2026-03-12 Ajusta union frontal de I
    [I.FCStd, I.step, I_bom.csv]
2026-03-12 Ajusta soportes y parante superior de I
    [I.FCStd, I.step]
2026-03-12 Checkpoint ajustes de I y cava integrada
    [I.FCStd, I.step, I_bom.csv]
2026-03-12 Checkpoint I tras ajustes de cajonera y cava
    [I.FCStd, I.step]
2026-03-12 Ajusta nicho izquierdo de I
    [I.FCStd, I.step, I_bom.csv]
2026-03-12 Ajusta profundidad y nicho de I
    [I.FCStd, I.step, I_bom.csv]
2026-03-12 Ajusta barra de ENSI
    [ENSI.FCStd, ENSI.step]
2026-03-12 Ajusta AC doble 18 y ensamble isla
    [AB.FCStd, AB.step, AB_bom.csv]
2026-03-12 Alinea H con lineas de gola de alacenas
    [ENS.FCStd, ENS.step, H.FCStd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]
2026-03-12 Actualiza manual, cortes y sitio estatico
    [BA.FCStd, ENSI.FCStd, ENSI.step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]
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2026-03-12 Ajusta golas y frentes de BA y BB
    [BA.FCStd, BA.step, BB.FCStd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]
2026-03-12 Ajusta puertas de AA y piso de AB
    [AA.FCStd, AA.step, AA_bom.csv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]
2026-03-13 Alinea puerta y gola superior de H con AB
    [ENS.FCStd, ENS.step, H.FCStd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]
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2026-03-13 Corrige calado superior de F2
    [ENSI.FCStd, ENSI.step, F.FCStd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]
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2026-03-13 Actualiza F R ENSI y base de FULL
    [ENSI.FCStd, ENSI.step, F.FCStd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]
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2026-03-17 fix FCStd web model exports
    [AA.step, AA.stl, AA_bom.csv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]
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2026-03-17 refine FCStd layouts for I, R, ENSI and FULL
    [ENSI.FCStd, FULL.FCStd, R.FCStd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]
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2026-03-18 add supplier exports for 3mm and 6mm cuts
    [AA_AB_BA_BB_H_R_fondo_3mm.tsv, AA_AB_BA_BB_H_R_fondo_6mm.tsv]
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
